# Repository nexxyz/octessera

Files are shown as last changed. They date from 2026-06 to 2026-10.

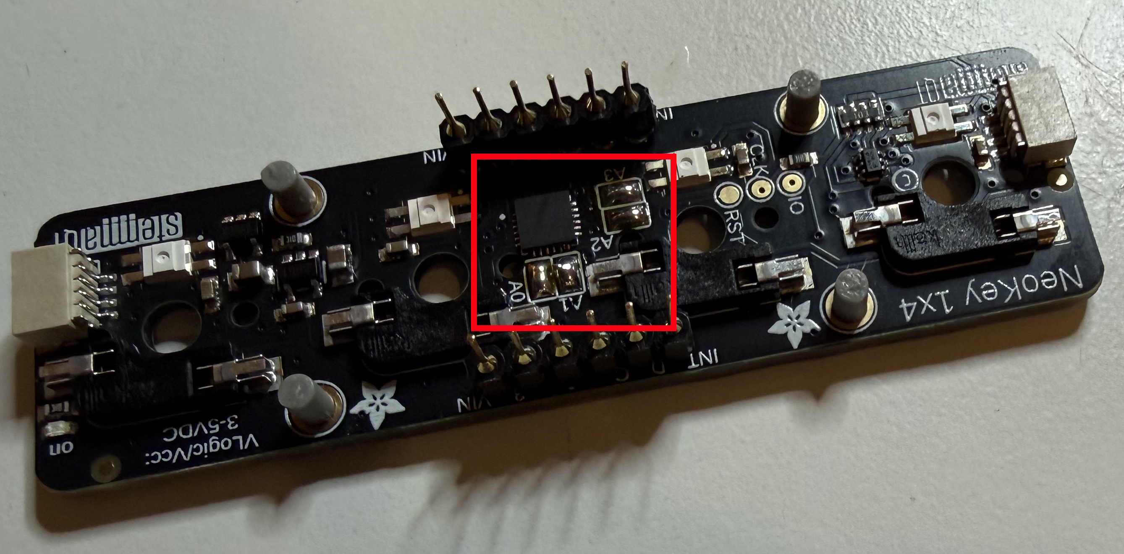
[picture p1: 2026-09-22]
userdocs/hardware/images/assembly/neokey-address-jumpers.jpg

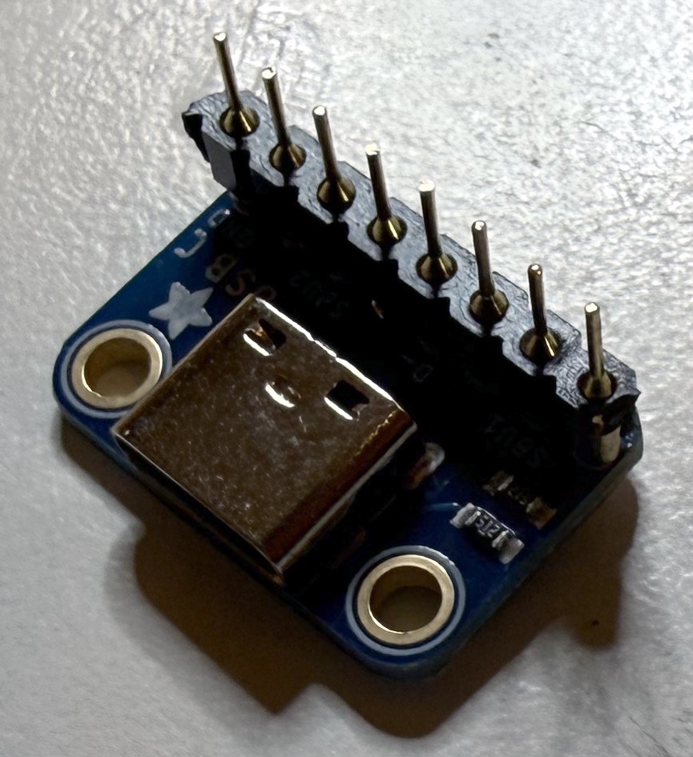
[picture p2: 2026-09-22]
userdocs/hardware/images/assembly/power-breakout.jpg

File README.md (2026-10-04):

# Octessera

Octessera turns cellular automata into music you can play.

It is a collection of small algorithmic musical world-bubbles. Set up a few
systems, combine them, nudge them, anchor them with a little sequencing, and
perform with the result in real time. Instead of filling in a piano roll, you
are giving small rule-based worlds room to surprise you.

## Start here

- [Try the simulator](userdocs/desktop-simulator.md) — make a sound without
  building the hardware.
- [Build the instrument](userdocs/hardware/assembly-manual.md) — assemble a
  standalone Octessera around a Raspberry Pi Zero 2 W or Orange Pi Zero 2W.

The standalone hardware uses one of those two fixed compute-board paths, with
an 8x8 grid, keys, encoders, OLED, and DAC. The desktop simulator mirrors the
same instrument so you can explore it on a computer first.

## What You Can Make

- Grow generative synth patterns from Life, Brain, Ant, Bounce, Raindrops, and
  other cellular-automata behaviors.
- Make hands-on drum sequences, load samples, and send parts to external MIDI
  gear.
- Layer up to eight instruments and let grid motion reshape another layer's
  pitch, filter, velocity, or probability through modulation.
- Route instruments directly or through FX buses, then shape the shared mix with
  bus and global effects.
- Use **Keys** to play a line live, and use **Play** pages to mix, pan, change
  trigger probability, move XY controls, and punch in momentary effects.

A first session might be a drifting `life` pattern under a hand-built drum
sequence, with a sampler providing the hits, a bus effect making room for the
synth, and a live Keys layer nudging the whole thing somewhere new.

## Two reading guides

- [User guide](userdocs/README.md) — simulator, assembly, setup, music-making,
  controls, and reference pages.
- [Technical guide](docs/README.md) — native architecture, contracts, fixed
  hardware paths, build tools, and provenance.

## Notes

[License](LICENSE) · [Sample source](samples/SOURCE.md) ·
[Hardware attributions](hardware/ATTRIBUTIONS.md) ·
[Third-party notices](THIRD_PARTY_NOTICES.md)

This project was created with AI assistance. Octessera itself, however, does not contain any AI.

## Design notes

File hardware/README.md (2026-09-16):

# Hardware

This is the home for Octessera's canonical hardware sources and committed
fabrication outputs.

## Navigate the hardware tree

- [`hardware/docs/`](docs/) contains build, bring-up, and hardware reference documents.
- [`hardware/pcb/`](pcb/) is the canonical KiCad source and library tree.
- [`hardware/enclosure/`](enclosure/) is the canonical CadQuery, generator, test, wrapper,
  and workflow source tree.
- The [hardware build entry](../userdocs/hardware/assembly-manual.md) walks through
  the shared assembly path.

## PCB outputs

[`hardware/pcb/gerber/`](pcb/gerber/) contains the committed fabrication output: Gerbers,
drill files, the KiCad job file, and [`gerber.zip`](pcb/gerber/gerber.zip).

## Enclosure outputs

The enclosure source tree includes
[`CAD_WORKFLOW.md`](enclosure/CAD_WORKFLOW.md) and the CadQuery generators,
tests, and wrappers. Its committed generated output sets are:

- [`hardware/enclosure/step/`](enclosure/step/) — exactly 18 STEP files;
- [`hardware/enclosure/stl/`](enclosure/stl/) — exactly 18 printable STL files;
- [`hardware/enclosure/3mf-single-material/`](enclosure/3mf-single-material/) — exactly 18 single-material 3MF files;
- [`hardware/enclosure/3mf-multicolor/`](enclosure/3mf-multicolor/) — exactly 18 3MF files.

The multicolor set is a complete print set: 12 authored two-material designs
plus six one-material support pieces.

Protective-case filenames are canonical and statusless (`protective_case_*`).
The design remains an unqualified check-fit prototype, not a drop-rated,
waterproof, or transport-qualified product.

## Attribution and notices

Consult these companions as applicable:

- [`hardware/ATTRIBUTIONS.md`](ATTRIBUTIONS.md)
- [`NOTICE`](../NOTICE)
- [`THIRD_PARTY_NOTICES.md`](../THIRD_PARTY_NOTICES.md)
- [`samples/SOURCE.md`](../samples/SOURCE.md)

## Release assets

GitHub Desktop and Pi release assets are built by the release workflows and are
not stored here. This tree contains the canonical hardware sources and
committed fabrication outputs only.

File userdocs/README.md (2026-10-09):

# Octessera user manual

Octessera is a collection of small algorithmic musical world-bubbles. Set up a
few systems, nudge them, anchor them with a little sequencing, and play the
result together with the machine.

## 1. Try the simulator

Start with the [desktop simulator](desktop-simulator.md) if you want to make a
sound before building anything. It needs no PCB, board, OLED, or soldering iron.

**Next:** [Learn the controls](controls-cheat-sheet.md)

## 2. Build the device

Choose a Raspberry Pi Zero 2 W or Orange Pi Zero 2W. Use the matching board
image and enclosure top.

[Build and assembly manual](hardware/assembly-manual.md) · [Safety and
power](hardware/safety-and-power.md)

**Next:** [Flash and first boot](hardware/flash-and-first-boot.md)

## 3. Flash and set it up

[Flash and first-boot guide](hardware/flash-and-first-boot.md) — matching image,
flashing, first boot, and network setup.

[USB roles](hardware/usb-roles.md) — host-computer connections.

**Next:** [Make music](#4-make-music)

## 4. Make music

1. In **Build**, choose `life`, `brain`, or `raindrops` for a layer.
2. Draw a few cells on the grid.
3. In **Shape**, choose a **synth**.
4. Press **Play** or **Space**.
5. Use **Play Mix** to adjust the layer's level, then explore the other Play
   pages.

[Controls cheat sheet](controls-cheat-sheet.md) · [Behaviors and Play
pages](behaviors-and-play.md) · [Sound and Link](sound-and-link.md) ·
[Recording](recording.md)

**Next:** [Controls cheat sheet](controls-cheat-sheet.md)

**Something is wrong?** Start with [troubleshooting](troubleshooting.md). Power
down before opening the case or moving wiring.

## Reference

### Contents

- **Operation:** [Controls cheat sheet](controls-cheat-sheet.md), [Behaviors and
  Play pages](behaviors-and-play.md), [Sound and Link: instruments, effects,
  and modulation](sound-and-link.md), [Recording audio and OLED](recording.md),
  [Data backup and restore](data-backup-restore.md),
  [Bluetooth keyboards and speakers](bluetooth.md), and
  [Troubleshooting](troubleshooting.md).
- **Build and hardware:** [Assembly manual](hardware/assembly-manual.md),
  [Flash and first boot](hardware/flash-and-first-boot.md),
  [Setup portal](hardware/setup-portal.md), [Enclosure](hardware/enclosure.md),
  [Protective case (optional)](hardware/protective-case.md),
  [Safety and power](hardware/safety-and-power.md), and
  [USB roles](hardware/usb-roles.md).
- **Quick reference:** [Printable quick reference](print/quick-reference.pdf).

### Practical performance

Use these as planning targets for dense patches:

| Mode | Synth voices | Sample voices | Bus FX | Global FX |
|---|---:|---:|---:|---:|
| Raspberry Latency | 16 | 16 | 8 | 2 |
| Raspberry Capacity | 32 | 32 | 8 | 2 |
| Orange Latency | 24 | 24 | 8 | 2 |
| Orange Capacity | 64 | 32 | 12 | 2 |

Voice counts are totals across all instrument slots, not per-instrument limits.
Adaptive voice stealing may reduce the active synth count as load rises. These
are practical targets rather than guarantees; behaviors, samples, and effects
all change the available headroom.

How quick does it feel? In Latency mode a grid press reaches your ears in about
6 ms on the Orange and 8 ms on the Raspberry. Capacity mode renders a little
ahead so it can spread the work over two cores, which puts it at about 13 to
15 ms: still fine for most playing, but you may feel it on fast finger drumming.

### Playing in front of people

Octessera boards skip the operating system's daily package-list and
manual-index jobs, plus a few other chores that do nothing useful on an
instrument. They never installed anything here anyway, but on the Raspberry
they made the audio stutter for a few seconds at a random time each day.

A handful of useful housekeeping jobs still run on a timer: log rotation, SD
card trim, temp-file cleanup, a package-database backup, and on the Raspberry
a once-a-minute Wi-Fi health log. Each of them has been run during playback
without disturbing the sound, but if you'd rather not find out the hard way,
use **System > Setup > Show Hold > Hold 48h** before a show. It postpones those
jobs for 48 hours (a reboot doesn't cancel it); they simply run at their next
scheduled time afterwards. **Release** ends the hold early. A couple of tiny
chores always keep running because things break without them: saving the
clock, and on the Orange trimming the in-memory logs.

The Raspberry's four cores share one fairly slow memory bus, so anything
heavy happening next to the music can still cause crackles even when it runs
on another core. Do your maintenance before the show, not during it: updates,
`apt` over SSH, copying big files onto the board. The Orange has a lot more
memory headroom and shrugs most of this off, but the same habit doesn't hurt.

One more thing: don't run `apt upgrade` on the board. Octessera boots its own
tuned kernel and device-tree setup, and a stock kernel or bootloader package
sneaking in can leave you with a board that boots but doesn't make a sound (or
doesn't boot at all). The boards hold those packages so apt leaves them alone,
but please don't go fishing with `--allow-change-held-packages`. Octessera
updates come through **System > Setup > Updates** or a fresh image.

### Samples

The default library has 320 media files: 318 WAV files available to the
sampler, plus two AIFF files outside the WAV-only browser. You can add your own
samples through the desktop sample browser or the board sample paths.

For the optional OLED microSD card, format it as FAT32 or exFAT and name the
volume `OCTESSERA`; the instrument only picks up a card with exactly that name.
This is SD2; the selected board's boot card is SD1. Put WAV files under
`octessera/samples`. You can swap the card while the instrument is on; give it
a couple of seconds to show up. If you use **System > SD Card 2 > Start
Transfer**, eject the host drive before
pressing **Back** or **Main** to stop the transfer.

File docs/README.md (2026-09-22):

# Technical guide

This is the short route through Octessera's current implementation contracts,
fixed hardware paths, build tools, and provenance. For operating the instrument,
start with the [user manual](../userdocs/README.md).

## Repository map

- `apps/` — platform applications and hardware adapters.
- `crates/` — native Rust core, runtime, and audio crates.
- `packages/` — shared TypeScript packages and desktop-facing contracts.
- `config/` + `resources/` — shipped defaults, generated configuration, and shared data.
- [`hardware/`](../hardware/README.md) — canonical PCB, enclosure, and hardware documentation.
- `userdocs/` — end-user build, controls, and operation guides.
- `docs/` — technical specifications, workflows, and contributor references.
- `tools/` — build, image, hardware, release, and verification tooling.
- `samples/` — bundled sample content, source acknowledgements, and manifests.
- `licenses/` + `third_party/` — generated dependency inventories and vendored/source provenance.
- `assets/` — shared branding and device visual assets.
- `userpatches/` — Armbian image overlays and device files; it stays at the root because Armbian consumes this conventional path.

## Architecture and contracts

- [Runtime boundaries](runtime-boundaries.md) — ownership between the desktop
  UI, native runtime, core, adapters, and realtime audio engine.
- [Menu and controls spec](menu-and-controls-spec.md) — the authoritative
  control, menu, overlay, persistence, and display contract.
- [Menu tree spec](menu-tree-spec.md) — the canonical menu structure.
- [Board profiles](board-profiles.md) — the two fixed board IDs and their
  platform boundaries.
- [Platform capabilities](../resources/platform-capabilities.json) — shared
  dimensions and limits used by native and desktop contracts.

## Hardware and images

- [Hardware pinout and connections](../hardware/docs/pinout-and-connections.md)
  — board wiring, buses, and port ownership.
- [Flash and first boot](../userdocs/hardware/flash-and-first-boot.md) — image
  selection, flashing, network setup, and first power-on.
- [Orange production image and runtime reference](../hardware/docs/orange-pi-production-reference.md)
  — Orange image, service, storage, audio, USB, and updater contracts.
- [Orange Pi input routing](../hardware/docs/orange-pi-input-routing.md) — the
  board-specific UART and encoder-routing overlay.

## Development, build, and deployment

- [Development workflows](development-workflows.md) — contributor workflow map
  and focused references.
- [Desktop development](workflows/desktop-development.md) — simulator
  development and desktop builds.
- [Pi provisioning](../tools/pi/provision/README.md) — Raspberry OS and boot
  configuration.
- [Board deployment](workflows/deployment.md) — Raspberry deployment and Orange
  input-routing operations.
- [Orange Pi tools](../tools/orange-pi/README.md) — Orange SSH bootstrap and
  cross-build commands.

## Attribution and licensing

- [License](../LICENSE) — terms for original Octessera material.
- [Notice](../NOTICE) — concise standalone-artifact notices.
- [Third-party notices](../THIRD_PARTY_NOTICES.md) — known third-party material.
- [Bundled sample source](../samples/SOURCE.md) — the sample-pack source.
- [Hardware attributions](../hardware/ATTRIBUTIONS.md) — PCB, enclosure, and
  module references.
- [Vendored CPAL provenance](../third_party/cpal-0.15.3/PROVENANCE.md) — the
  source and fixed audio-host modifications for the vendored dependency.

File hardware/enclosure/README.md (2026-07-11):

# Enclosure

This is the enclosure and mechanical reference for the Octessera hardware target.

Use it with [`../docs/pinout-and-connections.md`](../docs/pinout-and-connections.md) for wiring and [`../docs/pi-bring-up.md`](../docs/pi-bring-up.md) for Pi setup. For the user-facing docs home, start at [`../../userdocs/README.md`](../../userdocs/README.md).

This is the part where the instrument becomes an object you can pick up. Print carefully, test-fit patiently, and take out the SD card before you put the device in the enclosure, or it may break. Ask me how I found that one out.

## Current Status

The enclosure is under construction. The current parameter data in
`enclosure_params.json` is the `v21` set, but the generated two-level faceplate
is still an active design model, not a production-ready enclosure release.

- Case size: `247 x 140 mm`
- Main PCB rail height: `3.2 mm`
- NeoTrellis rail height: `8.0 mm`

## Two-Level CadQuery Model

Generate the current two-level model with CadQuery/OpenCascade:

```sh
python hardware/enclosure/generate_two_level_enclosure_cadquery.py
```

After changing the roof or parametric wave guidance, run the validation script:

```sh
python hardware/enclosure/validate_wave_roof.py
```

It writes:

- `../../release-artifacts/enclosure/step/case_top_two_level_cadquery.step`
- `../../release-artifacts/enclosure/stl/case_top_two_level_cadquery.stl`

The script requires the enclosure Python dependencies:

```sh
python -m pip install -r hardware/enclosure/requirements.txt
```

This model keeps OLED and encoders on the lower deck, raises the NeoKeys and
8x8 NeoTrellis field, and uses a parametric raised roof/shoulder over the Pi area.
See [`CAD_WORKFLOW.md`](CAD_WORKFLOW.md) for the edit and validation loop. For branded top artifacts, prefer:

```powershell
powershell -NoProfile -ExecutionPolicy Bypass -File hardware/enclosure/generate_branded_top_artifacts_checked.ps1
```

Branding source and cleanup rules are documented in [`../docs/branding-assets.md`](../docs/branding-assets.md).

The STEP file is the preferred generated artifact. This is still not a
production lid: it does not yet recreate the full underside lip, catch rims,
board capture ribs, or bottom mating interface. Promote it to the production top
only after validating that underside interface, board capture, connector
clearance, slicer output, and the measured component height stack.

## External Access

The current case exposes these ports:

- Left side: audio 3.5mm
- Left side: USB-C power
- Left side: Pi microSD
- Bottom side: Pi mini-HDMI
- Bottom side: Pi USB data

The OLED microSD is not exposed as a case-edge port in the current `v21` entry.

## Power Rule

- Power the device through the enclosure USB-C power opening.
- Do not power the Raspberry Pi through its own micro-USB power connector.
- The Pi micro-USB power connector is intentionally covered by the enclosure and is not meant to be used.

## Mechanical Strategy

The current enclosure captures the boards without running screws through active hardware areas.

- Case screws do not pass through the PCBs or component fields.
- Heat-set insert bosses are integrated into the outer locator rail regions.
- The main PCB is located laterally by tight rails and nubs.
- Lid capture ribs limit upward movement at safe board-edge regions.
- The NeoTrellis cluster is located by perimeter rails.
- The NeoTrellis left rail is broken for the `J1` / connector path clearance.
- NeoTrellis vertical retention is handled by the screwed-down top faceplate and edge capture ribs, not by screws through the button field.

## Printing Notes

Current enclosure notes from the parameter source:

- No OLED top-edge / top-plate hole above the display
- Case height reduced to `140 mm`; width remains `247 mm`
- The checked-in release artifact is the current generated faceplate mesh:
  `../../release-artifacts/enclosure/stl/case_top_two_level_cadquery.stl`.

## Source of Truth

- Parameters: [`enclosure_params.json`](enclosure_params.json)
- Enclosure layout image: [`layout.png`](layout.png)
- Wave/slot guidance: [`wave_guidance.py`](wave_guidance.py)
- Parametric generator: [`generate_two_level_enclosure_cadquery.py`](generate_two_level_enclosure_cadquery.py)
- Standoff pillar generator: [`generate_standoff_pillars.py`](generate_standoff_pillars.py)
- Standoff top-pin generator: [`generate_standoff_top_pins.py`](generate_standoff_top_pins.py)
- CAD workflow and checks: [`CAD_WORKFLOW.md`](CAD_WORKFLOW.md)
- Branded top artifact wrapper: [`generate_branded_top_artifacts_checked.ps1`](generate_branded_top_artifacts_checked.ps1)
- Roof-wall validation: [`validate_wave_roof.py`](validate_wave_roof.py)

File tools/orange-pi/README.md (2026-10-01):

# Orange Pi tools

This is a one-key bootstrap for an Armbian Orange Pi. It creates only the
dedicated `octessera` deployment account and its SSH key authorization. It does
not edit global `sshd` configuration, passwords, firewall rules, or default
users. Supply the deployed board target explicitly; the bootstrap examples below
remain generic for bringing up a replacement image.

## SSH bootstrap

### 1. Generate the key on Windows

Run this from the repository root in PowerShell. The key is created only when
`$env:USERPROFILE\.ssh\octessera_orange_pi_ed25519` is absent. The script never
prints the private key. Supplying a host appends a labelled stanza to
`$env:USERPROFILE\.ssh\config`; an existing different stanza is an error, not
an overwrite.

```powershell
.\tools\orange-pi\bootstrap-ssh.ps1 -HostName "<ORANGE_HOST>" -UserName octessera
```

To preview without creating or changing anything:

```powershell
.\tools\orange-pi\bootstrap-ssh.ps1 -HostName "<ORANGE_HOST>" -UserName octessera -WhatIf
```

Copy the public-key line and the exact next command printed by the script.
Copy `bootstrap-armbian-ssh.sh` to the Orange Pi first; for example, place it
in the current directory as `./bootstrap-armbian-ssh.sh` using the board's
local terminal, a console transfer, or another trusted path.

Record the deployment-key fingerprint on Windows:

```powershell
ssh-keygen -lf "$env:USERPROFILE\.ssh\octessera_orange_pi_ed25519.pub" -E sha256
```

### 2. Run on the Orange Pi terminal

Run this on the Armbian board, not on Windows. Replace the quoted key with the
single line printed in step 1:

```sh
sudo bash ./bootstrap-armbian-ssh.sh 'ssh-ed25519 AAAA... octessera-orange-pi'
```

The script is idempotent. It preserves existing `authorized_keys` entries and
refuses unexpected existing `octessera` homes, groups, or sudoers rules. It
requires exactly one `ssh-ed25519` public-key argument. Passwordless sudo is
not enabled unless explicitly requested:

```sh
sudo bash ./bootstrap-armbian-ssh.sh --allow-deploy-sudo 'ssh-ed25519 AAAA... octessera-orange-pi'
```

That opt-in grants `octessera` passwordless sudo for all commands and writes
`/etc/sudoers.d/octessera-deploy`; the script validates the rule with
`visudo`. Without the flag, the standard sudo policy is unchanged.

### 3. Verify fingerprints, then connect

Before accepting a host key, compare the board's host-key fingerprint with the
fingerprint shown by Windows. On the Orange Pi's local terminal:

```sh
sudo ssh-keygen -lf /etc/ssh/ssh_host_ed25519_key.pub -E sha256
```

On Windows, replace `<ORANGE_PI_HOST>` with the user-supplied IP or hostname:

```powershell
ssh-keyscan -t ed25519 <ORANGE_PI_HOST> | ssh-keygen -lf - -E sha256
```

Only continue when those fingerprints match. Then test the dedicated key
(replace the host with the same user-supplied value):

```powershell
ssh -i "$env:USERPROFILE\.ssh\octessera_orange_pi_ed25519" -o IdentitiesOnly=yes octessera@<ORANGE_PI_HOST> "id -un; hostname; test -r ~/.ssh/authorized_keys"
```

If the local script added its stanza, the shorter equivalent is:

```powershell
ssh octessera-orange-pi "id -un; hostname; test -r ~/.ssh/authorized_keys"
```

Review the host key before answering the first SSH authenticity prompt. Do not
use `StrictHostKeyChecking=accept-new` as a substitute for comparing the
fingerprint.

### Removal and revocation

To revoke this key but keep the deployment account, remove its exact public
key line from `/home/octessera/.ssh/authorized_keys` on the Orange Pi and then
remove the local key files if no longer needed:

```sh
sudoedit /home/octessera/.ssh/authorized_keys
```

```powershell
Remove-Item "$env:USERPROFILE\.ssh\octessera_orange_pi_ed25519", "$env:USERPROFILE\.ssh\octessera_orange_pi_ed25519.pub"
```

To remove the account and its home after revoking the key:

```sh
sudo userdel --remove octessera
sudo groupdel octessera
```

If passwordless deploy sudo was enabled, remove only the drop-in after checking
that it is the rule created for this account:

```sh
sudo rm -- /etc/sudoers.d/octessera-deploy
sudo visudo -c
```

Remove the labelled `OCTESSERA ORANGE PI` stanza from the Windows SSH config
manually. Do not commit private keys, public keys, fingerprints tied to a
specific board, hostnames, IP addresses, or generated SSH config to Git.

## Target and transport

Set the target for the board you are operating. Use `with-opi-ssh.ps1` for
SSH and SCP; it supplies the dedicated key,
`known_hosts`, strict host-key checking, and the passphrase from
`OCTESSERA_PI_PASSPHRASE`.

```powershell
$OrangeTarget = "octessera@<ORANGE_HOST>"
./tools/orange-pi/with-opi-ssh.ps1 ssh -Target $OrangeTarget "id -un; hostname"
```

For input-routing changes, use the [Orange input-routing reference](../../hardware/docs/orange-pi-input-routing.md)
and its `provision-input-routing.ps1` wrapper. The [deployment workflow](../../docs/workflows/deployment.md)
covers Raspberry deployment, Orange development deployment, and Orange input routing.

## Cross-build and stage

The WSL Docker builder writes AArch64 binaries and schema-2 metadata sidecars
under `target/orange-pi-cross/`:

```powershell
./tools/orange-pi/build-opi-cross.ps1 -Binary orange-oled-smoke -Profile release
./tools/orange-pi/build-opi-cross.ps1 -Binary orange-seesaw-smoke -Profile release
./tools/orange-pi/build-opi-cross.ps1 -Binary octessera-pi -Profile release
./tools/orange-pi/test-build-opi-cross.ps1
```

Use `-DryRun` to print the Docker command. The canonical outputs are
`orange-oled-smoke`, `orange-seesaw-smoke`, and `octessera-pi`, each with its
adjacent `.metadata.json` file. The production image and runtime bundle use the
contracts in the [Orange production reference](../../hardware/docs/orange-pi-production-reference.md).

To stage an output on the fixed board, use the canonical wrapper and preserve
the binary and sidecar names:

```powershell
$OrangeTarget = "octessera@<ORANGE_HOST>"
./tools/orange-pi/with-opi-ssh.ps1 scp `
  -Target $OrangeTarget `
  target/orange-pi-cross/octessera-pi `
  "${OrangeTarget}:/tmp/octessera-pi"
./tools/orange-pi/with-opi-ssh.ps1 scp `
  -Target $OrangeTarget `
  target/orange-pi-cross/octessera-pi.metadata.json `
  "${OrangeTarget}:/tmp/octessera-pi.metadata.json"
```

### Persistent Orange development runtime (explicit opt-in)

This is **not** the release updater and is separate from the temporary
foreground `/pi-smoke orange` run. After reviewing the target, artifact, and
service interruption, use the exact cross-built runtime candidate and its
unchanged adjacent metadata sidecar:

```powershell
$OrangeTarget = "octessera@<ORANGE_HOST>"
./tools/orange-pi/deploy-opi-fast.ps1 -Target $OrangeTarget -LocalBinary target/orange-pi-cross/octessera-pi
# Later, to return to the installed release:
./tools/orange-pi/deploy-opi-fast.ps1 -Target $OrangeTarget -Restore
./tools/orange-pi/test-deploy-opi-fast.ps1
```

The binary must match the current repository HEAD and be an ELF64 AArch64
`runtime-candidate` for `orange-pi-zero-2w`, with schema-2 release-profile
metadata and matching SHA-256. This does **not** promote `runtime_ready` or
write release/updater metadata. On the board, the tool stages a root-owned
copy at `/opt/octessera/dev/<source-commit>/octessera-pi` and overrides only
`ExecStart` using `/etc/systemd/system/octessera.service.d/90-octessera-dev.conf`.
It refuses a pre-existing drop-in or an unexpected service/executable, checks
the restarted process, and tries to restore the installed service on activation
failure. `-Restore` removes only the recognized development override; it does
not delete the development binary. Neither action touches `current`, releases,
the installed executable symlink, boot files, or the image. A failure to verify
rollback requires immediate manual service inspection. Journal errors and
underruns are reported as warnings; an active service is not proof of clean
audio. Keep hardware listening and control checks in the operator loop. The
tool refuses an existing `/opt/octessera/dev/<source-commit>` directory rather
than overwriting a previously staged build; restore leaves that directory in
place for explicit operator review or cleanup.

## Performance tools

The current performance commands are also listed in
[`docs/workflows/pi-development-and-profiling.md`](../../docs/workflows/pi-development-and-profiling.md):

```powershell
$OrangeTarget = "octessera@<ORANGE_HOST>"
./tools/orange-pi/run-orange-capability-study.ps1 -Target $OrangeTarget -Mode PassiveBaseline -PrintOnly
./tools/orange-pi/run-orange-capability-study.ps1 -Target $OrangeTarget -Mode Dsp64 -AllowServiceInterruption -PrintOnly
./tools/orange-pi/run-orange-capability-study.ps1 -Target $OrangeTarget -Mode Dsp256 -AllowServiceInterruption -PrintOnly
./tools/orange-pi/run-orange-live-audio-matrix.ps1 -Target $OrangeTarget -PrintOnly
./tools/orange-pi/run-orange-performance-baseline.ps1 -Target $OrangeTarget -PrintOnly
```

Active runs use `-AllowServiceInterruption`; the live matrix additionally uses
`-AllowMatrixServiceInterruption`. The command-generation checks are:

```powershell
./tools/orange-pi/test-with-opi-ssh.ps1
./tools/orange-pi/test-run-orange-capability-study.ps1
./tools/orange-pi/test-run-orange-live-audio-matrix.ps1
./tools/orange-pi/test-run-orange-performance-baseline.ps1
```

For an isolated Orange AWAKE live candidate, the workstation-only Aux timing
smoke is separately opt-in. It runs a short cutoff-edit pattern after the native
menu and host path are verified, then requires an accepted, identified automatic
default-save success for the final edit revision. The native worker emits that
completion only after writing the clone's default config. The existing AWAKE
wrapper uses a temporary study-store clone:

```powershell
$OrangeTarget = "octessera@<ORANGE_HOST>"
$previousAutoAux = $env:OCTESSERA_ORANGE_STUDY_AUTOAUX
$env:OCTESSERA_ORANGE_STUDY_AUTOAUX = "1"
try {
  ./tools/orange-pi/run-orange-capability-study.ps1 `
    -Target $OrangeTarget -Mode LiveCandidate -UiProfile -AutoPlay -KeepAwake `
    -AllowServiceInterruption -LiveSeconds 30
} finally {
  if ($null -eq $previousAutoAux) {
    Remove-Item Env:OCTESSERA_ORANGE_STUDY_AUTOAUX -ErrorAction SilentlyContinue
  } else {
    $env:OCTESSERA_ORANGE_STUDY_AUTOAUX = $previousAutoAux
  }
}
```

Without the workstation opt-in, `-KeepAwake` does not schedule Aux turns. The
candidate refuses the timing sequence unless all its timing/profile gates and
the isolated study-store path are present; it never rewrites the installed
user store. If Auto Save is off, the candidate enables it through the native
Saves menu in the temporary clone so the final edit has a due save. The one-line
`orange-autoaux` report includes the final save revision, request ID, and elapsed
time from the edit burst to accepted completion, alongside the existing input,
OLED, and host-command evidence. A missing completion or matching failed save
fails the opt-in smoke; unrelated, stale-revision, manual, and unidentified
results do not count. The installed default and original user store remain
untouched.

## Orange Pi USB gadget composer

`orange-pi-usb-gadget.sh` is the Armbian ConfigFS composer. It reads
`/var/lib/octessera/presets/system.json`; `audioOutputs.usb` selects UAC2 and
`usb.midiOutEnabled` selects MIDI. The fixed UDC is `musb-hdrc.4.auto`.

```sh
sudo bash ./tools/orange-pi/orange-pi-usb-gadget.sh setup \
  --config /var/lib/octessera/presets/system.json
sudo bash ./tools/orange-pi/orange-pi-usb-gadget.sh teardown
bash ./tools/orange-pi/test-orange-pi-usb-gadget.sh
```

Supported modes are no gadget, `midi`, `uac2`, and `combined`; the installed
image uses `combined`. Setup and teardown share
`/run/lock/octessera-orange-usb-gadget.lock`. `--lock-file`, `--configfs-root`,
and `--udc-root` are available for isolated fake-ConfigFS tests.

The product strings are `Octessera MIDI`, `Octessera Line In`, and
`Octessera Audio + MIDI` for `midi`, `uac2`, and `combined`. MIDI and combined
require a writable ConfigFS `interface_string`. The MIDI interface descriptor
and Windows `DEVPKEY_Device_BusReportedDeviceDesc` are `Octessera MIDI`; the
composer writes and verifies the 14-byte value before binding the UDC.

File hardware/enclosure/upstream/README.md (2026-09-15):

# Upstream parametric box

`andy_wings_parametric_box.py` is adapted from **Simple and Light Parametric
BOX – CadQuery** by Andy Wings / `@WingsWorld_2406962`:

- Printables: https://www.printables.com/model/1069138-simple-and-light-parametric-box-cadquery
- Matching Thingiverse listing: https://www.thingiverse.com/thing:6842165
- License: [CC BY-SA 4.0](https://creativecommons.org/licenses/by-sa/4.0/)

Octessera adapted and modified the upstream shell, mating ring, hinge, and Clip
profile algorithms. The adaptation only makes construction reusable, derives
the hinge leaf depth from each measure instance, supports configured clip
positions, skips the horizontal chamfer when `chamfer_xy=0` while preserving the
default chamfer, and guards default construction/export behind the module
entrypoint.

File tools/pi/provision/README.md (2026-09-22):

# Pi provisioning

`../provision-pi.ps1` installs the development Pi OS, boot, network, sudoers,
performance, and splash configuration. It is safe to run again after changing
the tracked files in this directory or the shared Pi image files.

Provision the device before the first fast deployment:

```powershell
$PiTarget = "pi@<PI_HOST>"
./tools/pi/provision-pi.ps1 -Target $PiTarget -BoardProfile raspberry-pi-zero-2w
```

The selected initramfs is not refreshed by default. Pass `-UpdateInitramfs` for
an explicit OS or boot rebuild; the direct script accepts
`--update-initramfs`. Provisioning removes the retired Raspberry animation hook
and script before an explicit rebuild, so no board carries animation in its
initramfs. The deployment script does not change OS configuration; it uploads
the binary or source, restarts the service, and can tail its logs.
Raspberry Pi provisioning rejects `orange-pi-zero-2w`; Orange Pi uses the
separate Armbian bring-up path.

The shared transport wrapper reads an encrypted-key passphrase only from the
process environment and removes its temporary askpass script when it exits.
Set `OCTESSERA_PI_PASSPHRASE` in the current PowerShell process first:

```powershell
# Set OCTESSERA_PI_PASSPHRASE in this PowerShell process before these commands.
$PiTarget = "pi@<PI_HOST>"
./tools/pi/with-rpi-ssh.ps1 ssh -Target $PiTarget "hostname"
./tools/pi/with-rpi-ssh.ps1 scp -Target $PiTarget ./candidate.bin "${PiTarget}:/tmp/candidate.bin"
./tools/pi/with-rpi-ssh.ps1 ssh-payload -Target $PiTarget ./remote-script.sh
```

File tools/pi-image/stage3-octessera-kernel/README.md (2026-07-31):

# Raspberry custom-kernel stage

Enable this stage before `stage4-octessera`. The image build must provide:

- `OCTESSERA_KERNEL_PACKAGE`: the already validated exact arm64 `.deb`;
- `OCTESSERA_KERNEL_CHECKSUMS`: its one-entry `SHA256SUMS` file;
- `OCTESSERA_KERNEL_PROVENANCE`: the package provenance JSON; it is copied and
  validated before `dpkg` is allowed to install the package.

The stage rechecks the package filename, Debian control fields, checksum, ARM64
firmware header, DTB, overlays, and required modules. It retains stock boot
files under `octessera/recovery-stock` before installing the package. Stage 4B
generates the custom initramfs after the service stage has installed its hooks.

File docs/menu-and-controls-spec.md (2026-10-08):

# Menu and Controls Spec (Authoritative)

This is the entry point for the canonical menu/control spec. The full menu tree is split into `docs/menu-tree-spec.md`; that file is part of this authoritative spec and must stay in sync with native menu changes.

Context-help copy source: `resources/menu-help-texts.tsv` (required header row). Each row provides a title plus two short text fields. Keep one idea per text field; the runtime may join and wrap them for the target display.
Platform capability source: `resources/platform-capabilities.json`; generated TypeScript and Rust constants must stay in sync with it. Display palette source: `resources/display-palette.json`; generated TypeScript, CSS, and Rust constants must stay in sync with it.

## Cheat Sheet

| Combo | Function | Notes |
|---|---|---|
| Shift + Space | Stop | Internal sync: stop/reset, silence internal audio, and clear held MIDI notes without broad panic.
| Shift + Space (external sync) | Resync arm | External sync: arms a one-shot resync at the next 96-PPQN (one-bar) boundary; playback and the grid continue, then transport origins reset to zero and the arm clears.
| Shift + Back | Clear active layer | Re-initializes current active layer behavior state.
| Shift + Fn | Combined modifier | Acts as its own logical button; Fn and Shift are inactive while both physical buttons are held.
| Combined modifier + Main press | Context help | Opens help for highlighted menu entry.
| Fn + Main press | Aux mappings modal | Opens the scrollable mappings modal from anywhere, whether stopped or playing. Holding Fn alone does not open it.
| Fn + Main encoder turn right outside edit | Single step | While paused/stopped, advances exactly one behavior generation and remains paused/stopped; while playing, shows `Pause first`. Turning left is consumed with no action. Numeric edit takes priority over this gesture.
| Main numeric edit turn | Coarse/fine value change | Plain Main is coarse; Fn+Main is fine. Shift+Main and combined Shift+Fn+Main remain coarse. Fn does not change enum, bool, or text edit turns.
| Aux1–3 numeric turn | Coarse/fine bound value change | Plain turn is coarse and Fn turn fine in the normal custom/auto-map target. Shift is coarse and combined Shift+Fn fine in the shifted custom bank only, with no fallback.
| Fn + Space | Reset stop | Stops/resets, silences internal audio, and clears held MIDI notes without broad panic; takes priority over sample preview.
| Combined modifier + Space | Reserved | No-op.
| Fn + leftmost grid column | Navigate layers (1..8) | Mirrors `Build > Layer`.
| Combined modifier + leftmost grid column | Layer trigger gate toggle | Toggles that layer between `0%` and its previous trigger mode without changing active layer. Only this disable transition releases held Synth, FM, Plucked, and Sampler notes owned by that layer, plus external MIDI notes; an already-ringing one-shot Drum hit finishes its decay. Ordinary Play Trigger Gate edits to `0%` only suppress future admissions. Other layers are unaffected, and re-enable does not resurrect released notes.
| Fn held + leftmost column LEDs | Navigation indicators | Cyan = navigation/current layer focus, green = configured layer, gray/black = inactive or non-navigable.
| Fn + rightmost grid column | Navigate Play pages | Opens `Play` and enables Play page if currently off; exits Play if already active.
| Combined modifier held LEDs | Layer-only indicators | Shows the left/layer side of Fn navigation only; Play page column is hidden/reserved.
| Sample assign + Shift + cell | Row assign step | Applies current selected-cell assign step to the whole row.
| Sample assign + combined modifier + cell | Column assign step | Applies current selected-cell assign step to the whole column.
| Fn + Aux press | Alternate aux binding | Binds the focused bindable value as that aux Turn target, or focused action as its `!` press target.

## Control Mapping

| Control | Simulator Key | Function |
|---|---|---|
| Main encoder turn | ← → | Move cursor / adjust values |
| Main encoder press | Enter | Enter group / enter/exit edit / trigger action |
| Back button | Backspace / Esc | Go back / exit edit / clear grid (with Shift) |
| Space button | Space | Play / Pause |
| Shift + Space | Shift+Space | Stop/reset with internal-audio silence and bounded held-note cleanup; external sync arms the next 96-PPQN boundary instead |
| Fn + Space | Ctrl+Space | Reset stop with internal-audio silence and bounded held-note cleanup |
| Shift + Fn + Space | Shift+Ctrl+Space | Reserved no-op |
| Shift + Back | Shift+Backspace / Shift+Esc | Clear grid (re-initialize behavior) |
| Aux encoder 1-3 turn | (simulated) | Adjust a numeric target coarsely, or retain ordinary discrete turns for enum/bool targets; Orange SW1/SW2/SW4 use the native GPIO event path |
| Aux encoder 1-3 press | (simulated) | Trigger bound press mapping; Orange AUX2's switch line is unavailable only while UART0 TX is active and is enabled by the input-routing overlay |
| Fn + Aux encoder press | Fn + (simulated) | Alternate action: bind current value as Turn target or current action as `!` press target |
| Fn + Main encoder press | Fn+Enter | Open/close the Aux mappings modal; holding Fn alone does not open it |
| Shift + Aux encoder turn/press | Shift + (simulated) | Numeric turns are coarse; use only the shifted aux binding bank |
| Fn + Aux encoder turn | Fn + (simulated) | Fine numeric turn on the normal custom/auto-map target |
| Shift + Fn + Aux encoder press | Shift+Ctrl + (simulated) | Bind current value/action into shifted aux binding bank |
| Shift + Fn + Aux encoder turn | Shift+Ctrl + (simulated) | Fine numeric turn using only the shifted custom bank |
| Shift + Fn | Shift+Ctrl | Combined modifier; acts as its own logical button and disables Fn/Shift functions while both are held |
| Combined modifier + Main press | Shift+Ctrl+Enter | Context help for highlighted entry |
| Fn + Main encoder turn right outside editing | Ctrl+→ | Single behavior/world generation step while paused/stopped; while editing, numeric values turn finely and other edit types keep their ordinary turn behavior |
| Fn + leftmost grid column | Ctrl + leftmost grid column | Navigate active layer (1..8); hold Fn to see layer indicators |
| Fn + rightmost grid column | Ctrl + rightmost grid column | Navigate/activate Play Play page; hold Fn to see page indicators |
| Shift + Fn + leftmost grid column | Shift+Ctrl + leftmost grid column | Toggle that layer's trigger gate without changing active layer; disabling releases its held Synth, FM, Plucked, Sampler, and external MIDI notes and suppresses future triggers; one-shot Drum hits finish their decay |
| Sample assign mode + Shift + cell press | Shift + cell | Apply current assign toggle/level step to entire row |
| Sample assign mode + combined modifier + cell press | Shift+Ctrl + cell | Apply current assign toggle/level step to entire column |

## USB-host keyboard

The base keyboard controls mirror the simulator controls. USB-host capture
additionally maps the three AUX encoder rows:

| Keyboard key | Native control | Repeat |
|---|---|---|
| ← / ↑ | Main encoder turn `-1` | Accepted |
| → / ↓ | Main encoder turn `+1` | Accepted |
| Q / W / E | AUX1 turn `-1` / click / turn `+1` | Turns accepted; click suppressed |
| A / S / D | AUX2 turn `-1` / click / turn `+1` | Turns accepted; click suppressed |
| Y/Z / X / C | AUX3 turn `-1` / click / turn `+1` | Turns accepted; click suppressed |
| Enter | Main encoder press | Suppressed |
| Backspace / Escape | Back button | Suppressed |
| Space | Space button (`S`) | Suppressed |
| Shift | Shift modifier | Suppressed |
| Control | Fn modifier | Suppressed |

Key presses and releases update the corresponding native button or modifier state. Arrow and AUX turn key-repeat events emit additional turns; repeat events for Enter, AUX click keys, Back, Space, Shift, and Control do not emit additional edges. AUX click key releases clear their held keyboard state without retriggering the encoder click, and disconnect, disable, read failure, and shutdown use the same held-state cleanup. The AUX3 left key is the physical key immediately right of left Shift; Linux binds that position as `KEY_Z` whether its keycap is `Y` or `Z`. Space remains the hardware Space/S button; the letter `S` is the AUX2 encoder click. Modifier combinations therefore retain their normal semantics: Shift+Space is Stop (or Resync arm under external sync), Control+Space is Reset stop, and Shift+Control+Enter opens context help.

Raspberry capture requires the persisted USB role to be `Host`; changing that role still uses the existing save-and-reboot flow. Orange capture uses the fixed USB-A host connector and is independent of USB0 OTG/gadget behavior. On both boards, capture is enabled only for graphical HDMI modes: `live-grid`, `plain-grid`, `active-behavior`, and `cycle-behaviors`. `Terminal` disables capture. Hotplug and HDMI-mode transitions are live: the first supported keyboard is selected and exclusively grabbed, a second keyboard is ignored while it is selected, and disconnects or gate changes release held logical controls and the grab.

Simulator grid drag behavior follows the active behavior's declared interaction mode. Paint behaviors drag-toggle/draw cells for editing; momentary behaviors such as Keys release the previous cell when the pointer enters another cell, matching a single finger sliding across grid buttons.

Raspberry and Orange use the same native encoder dispatch semantics: consecutive turns from one encoder in one direction coalesce and clamp to a `-127..127` delta, reversals remain ordered, and pending turns dispatch before an encoder press. Each input pickup drains at most 16 encoder events so other runtime work is not starved.

Help popup behavior:

- Main encoder turn scrolls help text
- Main encoder press closes help

Aux mappings modal behavior:

- Fn + Main encoder press opens the scrollable modal from anywhere, whether transport is stopped or playing. Releasing Fn does not close it; Fn held alone does not open it.
- The modal shows all 12 mappings, including unbound rows as `-`:

  | Bank | Aux | Turn | Click |
  |---|---|---|---|
  | Normal | 1 | Mapping or `-` | Mapping or `-` |
  | Normal | 2 | Mapping or `-` | Mapping or `-` |
  | Normal | 3 | Mapping or `-` | Mapping or `-` |
  | Shifted | 1 | Mapping or `-` | Mapping or `-` |
  | Shifted | 2 | Mapping or `-` | Mapping or `-` |
  | Shifted | 3 | Mapping or `-` | Mapping or `-` |

- Normal mappings use a custom binding first, then auto-map; shifted mappings use the shifted custom bank only, with no fallback.
- Main encoder turn scrolls the modal. Aux turns and clicks do nothing while it is open; they do not affect the underlying menu or bindings.
- Plain Main press, Fn + Main press again, or Back closes the modal. Shift + Fn + Main press opens context help instead. After closing, normal Main/Shift+Main clicks, Fn fine turns, and Aux bindings work as usual.

## Transport States

- Play: `▶` (green flash on full-note/measure boundaries, yellow flash on other beat boundaries)
- Pause: `⏸`
- Stop: `■`
- Stop, accepted MIDI Start, and resync reset the transport origin, generic scan cursor, autonomous Build cadence, Pattern phase, and Looper playback position while preserving evolved worlds, configuration, and recorded loop; behavior-owned state follows each behavior's reset contract. While transport runs, clearing or replacing a behavior reinitializes or restores its behavior-owned state as defined, while preserving the transport-owned generic interpretation cursor, fractional accumulator, and page/section phase. Only Sequencer has origin-immediate static-grid semantics: page 1 step 1 is anchored at transport origin, empty leading cells are timed rests, and later pages continue without restarting. For an armed external resync, clocks strictly before the next 96-PPQN boundary process normally; the boundary clock is consumed by the reset, scanning Sequencer layers process their origin tick at reported PPQN 0, and non-Sequencer layers do not receive a zero-elapsed tick. The following clock reports PPQN 1 and does not repeat the origin tick. Pause and layer trigger-gate changes preserve phase; true stop/reset returns to origin. Pause/Continue resumes the exact phase.

## Seeded Randomness

Randomness is unseeded unless a source opts in. `Build > Seed` (`randomSeed`, `1..9999`, default `1`) is one shared per-patch seed. `Build > Lx > Seeded` makes that layer's behavior randomness, including hash-style choices and the Rhythm/Musical/weave pattern seed, follow a stream mixed from Seed and the layer index. `Link > Lx > Seeded` does the same for that layer's trigger probability and random arp order; unseeded Link layers keep the shared unseeded streams. Seeded streams restart on every transport reset (stop, play-from-stop, accepted MIDI Start, resync), on patch load, and when Seed or the layer's Seeded switch changes, so the same starting world, inputs, and timing replay the same result on every platform. Restarting a stream never resets an evolved grid. Instrument and FX audio-rate noise is never seeded.

## Menu Tree

The full native menu tree lives in [`menu-tree-spec.md`](menu-tree-spec.md). Keep that file in sync with native menu/control changes.

System children are ordered as Load Preset, Recording, Notes, MIDI, Audio, UI, conditional SD Card 2,
conditional HDMI Video, conditional Bluetooth, Saves, Setup, Reset, then Panic, Sys. Info, Basic Help, Reboot, and Shutdown.
Within each recursive group, parameters and submenus precede action rows, except that the dynamic Rename group lists preset choices before its Rename actions. The System tree fully expands
the desktop, Orange, Raspberry Gadget, and Raspberry Host branches.

## OLED Display

- Native presentation publishes a positive-revision `oled_frame` (`128x128`, `rgb565be`) only when the frame bytes change, immediately before the semantic snapshot that references `oledFrameRevision`. PlaybackRuntime owns OLED brightness conversion and must not emit a snapshot with revision `0`, including when presentation input is absent or malformed. Before the first valid frame, an invalid snapshot is suppressed and typed fault/status is emitted; after a valid frame, non-OLED snapshot state continues with the prior positive revision and a typed retain-last-good fault/status. Desktop, Raspberry, and Orange consume native frames only; no TypeScript or semantic Pi renderer fallback is permitted.
- Every snapshot `display` object carries the required `bodyLayout`: `rows` preserves the existing menu/help/sample/restore/confirmation/System Info/concise-MIDI row semantics, including its 28-character/7-row normalization, bars, selected-line scrolling, and scrollbars; `card` is used for setup-portal and Backup / Restore status and keeps every complete semantic source string in `display.lines`. Card rendering uses the shared `x=4`, `width=120`, `y=18`, `height=91`, `rowAdvance=13` body rectangle (20 monospace columns by 7 rows), reserves the final visual row for the selected action, and ignores row bars/scroll metadata. When card prose wraps or later semantic lines do not fit, only the final visible prose row receives `...`. The canonical native renderer and the Pi renderer use the same fixed-font layout metrics and wrapping rules.
- Pi/Orange cache candidates promote only on an exact matching snapshot reference. With no accepted frame, publication is explicit black. With an accepted frame and a missing, future, stale, malformed, or conflicting reference, publication is `RetainedLastGood` carrying the accepted immutable bytes and revision, while the typed cache fault remains sticky. Same-revision byte conflicts remove candidates or poison accepted revisions; only a strictly newer valid candidate plus matching snapshot can recover. The first acknowledged menu still requires an exact accepted matching pair; retained-last-good is not sufficient. Boot, direct fault, shutdown, suspend, and ownership lifecycle frames remain native adapter paths.

- 128×128 pixel, simulated in desktop app
- 20 characters × 8 lines of text (5×7 font, 16px line height)
- Top line: title bar (colored by section)
- Canonical display palette names are independent from menu sections: `GREEN` `#63D23F` for `Build`, `RED` `#DD82CD` for `Link`, `BLUE` `#35CFF2` for `Shape`, `YELLOW` `#FFD447` for `Play`, `GRAY` `#C9CED6` for `System`, plus white `#FFFFFF` and black `#000000`. Runtime, Pi, and desktop UI colors use this palette unless a behavior deliberately owns its own palette.
- Body lines 2-8: menu items use a `> ` marker and inverted highlight on the selected row, and `* ` when editing; while browsing, selected value rows stay compact on one row (for example `> Cutoff 127`) instead of adding a separate value row
- Native menu snapshots include rendered-row scroll metadata (`scrollOffset`, `totalRows`, `visibleRows`) for the current body window. Desktop renders this as a 1-2 px scrollbar inside the OLED body only when total rendered rows exceed visible body rows; it does not consume text columns and is omitted for splash/help/confirm overlays unless menu metadata is present.
- Context help for every submenu, parameter, action, and non-file selector menu item must resolve to an entry from `resources/menu-help-texts.tsv`; native tests must fail on missing coverage. Behavior selector leaves use behavior-specific help, behavior category menu items use stable `behavior.category.*` help keys, and parameter binding picker leaves resolve to the underlying target parameter help. Dynamic file menu items such as sample browser files and folders keep their own `sample.*` action help.
- Platform-sized menu/runtime limits such as layer count, instrument count, sample slots, bus count, global FX slots, Play-FX concurrency, scan section counts, OLED size, and pan position count come from `resources/platform-capabilities.json`.
- Splash graphics use the shared static `SPLASH_SLEEP_SHUTDOWN` logo+wordmark background for sleep/shutdown with the existing toaster geometry; the native sleep transition toast is exactly `Going to sleep`; regular logo presentation remains unchanged for startup/wakeup.
- On Pi, `display.off` keeps the OLED dark. Otherwise a top-level `runtimeError` takes full-frame priority over splash, menu, and footer toast content; it shows the typed domain/code/operation/message fault and leaves transport/event indicators hidden. The native MIDI input-list failure presentation is the exception: it keeps the concise `MIDI INPUTS` / `MIDI unavailable` menu frame and toast. With no runtime error, splash precedes the normal menu/footer priority described below.
- Full runtime errors use seven fixed body rows at the existing card geometry: `DOMAIN ` plus 11 identifier cells, `CODE ` plus 13, `OP ` plus 15, then `MSG ` plus up to 14 message cells and three continuation rows with a four-space prefix plus up to 14 cells. Identifier underscores become spaces; controls and whitespace collapse; unsupported glyphs become visible `?`; missing identifiers show `unknown`. Messages preserve supported path punctuation and underscores, use `needs attention` when missing, wrap words and hard-break long words across the four message rows, and end the final content row with `...` when truncated. Unused continuation rows are empty. PlaybackRuntime owns this layout; Pi consumes the resulting rows.
- `PlaybackRuntime::latched_errors` is the sole canonical owner of presented runtime-error visibility. While its top error is visible, ordinary physical `DeviceInput` messages are rewritten internally and never forwarded to platform adapters; `requestSnapshot: false` is ignored on this gated path. Awake `DeviceInput::ButtonA { pressed: Some(true) }` (the Back button) or `DeviceInput::EncoderPress { id: Some("main") }` dismisses only the exact captured top error; the transaction then emits the underlying menu/modal/OLED snapshot. A dismissal does not restart transport or emit any action/effect/event/command. Every other input, including button releases, encoder turns, aux inputs, grid presses/releases, and `Other`, is consumed without changing the underlying state. Wake handling still has precedence: the first input that wakes the OLED is consumed as wake input and does not dismiss the error frame.
- While the error gate is active, Shift/Fn/combined-modifier press and release inputs update only their physical pressed/held state. They do not execute mapped controls, and dismissal does not blindly clear a modifier that is still physically held; a release received during the error gate reconciles the held state before the underlying UI is restored.
- The runtime error frame shows the compact `Back/Press: close` affordance below the fixed metadata/message rows.
- A visible setup portal modal has priority after confirmation dialogs and ahead of system-info and help modals.
- A visible Backup / Restore card has the same modal priority after confirmation dialogs and setup-portal presentation, ahead of system-info and help modals.
- Bottom-right corner: transport icon (`▶` / `⏸` / `■`), hidden while a footer toast is active
- Transport color: the native snapshot owns the NeoKey presentation. Back is red; Space is red stopped, blue paused, dim green while playing at rest, yellow on beat flashes, and green on measure flashes. Combined modifiers are blue, held modifiers are yellow, and inactive modifiers are dim gray.
- Event-dot and transport-flash presentation uses native monotonic deadlines: 45 ms for the event dot and 90 ms for beat/measure flashes. A visible start, flash-kind change, or expiry transition forces one snapshot; same-state retriggers extend only.
- Aggregate audio-load telemetry is separate from worker warning presentation. Recent voice stealing turns the active event dot magenta; aggregate load and voice-steal status remain on the desktop audio-load bridge and do not drive the worker icon.
- Persistent-worker CPU icon: red at `(117,5)` only when valid persistent worker metrics report `high_cpu_steady`; missing or inline metrics hide it. A missed-quantum flash has priority in that same CPU slot and uses the inverted white/black CPU glyph, so the red CPU icon is hidden while the miss is active. The save icon remains yellow at `(107,5)` and may coexist with either CPU-slot state. A newly missed persistent quantum replays the previous final master quantum exactly once when its frame count matches; otherwise it emits silence, and subsequent refills during recovery emit silence. `missedQuantumFlash` is armed for five emitted seconds (`sampleRate * 5`), clears on the exact emitted-frame crossing, and resets on a later miss. These status transitions do not change the existing OLED layout or coordinates.
- Toast text: displayed at bottom for feedback messages

NeoKey snapshot contract:

- `neoKeyLeds.back`, `.space`, `.shift`, and `.fn` are required native RGB values before brightness scaling. Desktop and Pi apply the same basis-point rule: normal scale is `buttonBrightness * 100`; dimmed scale is zero for zero brightness, otherwise `max(buttonBrightness * 8, 400)`; each channel is `(channel * scale + 5000) / 10000`.
- `eventDotOn`, `transportIcon`, and `transportFlash` are required top-level snapshot fields. `transportFlash` is not duplicated under `settings`.

## Grid Coordinate Boundary

- The fixed grid is 8×8. Native behavior/world coordinates use a lower-left origin: `(0,0)` is bottom-left and `y` increases upward.
- Display and hardware frames use top-left row-major order at the boundary. `platform-core` owns the pure logical row-major and logical/display projection helpers; `playback-runtime` delegates its existing display-index API to them.
- Desktop `GRID_DOMAIN` remains a deliberate boundary mirror for input/rendering and is checked against every cell in `resources/grid-projection-v1.json`. The fixture is verification data, not a runtime projection table.
- HAL NeoTrellis wiring remains fixed adapter data: four device quadrants, physical keys, device addresses, and GRB output are kept separate from the shared world/display projection.

Value editing semantics:

- Number/enum/bool rows enter edit mode on Main press; Main or Back finishes the row. At the Save Setting choice, Back means Cancel; at the Restart? choice, Back means Continue.
- Navigation memory is limited to `System`, `System > Notes`, `System > Audio`, `System > Audio > Engine`, and `System > UI`. It is native, ephemeral, cleared on menu rebuild, and does not apply to any other menu, dynamic list, sample browser, preset list, MIDI port list, parameter picker, help, confirm dialog, or assignment overlay.
- `System > Audio > Engine` persists `runtimeConfig.dsp.workerWarningThreshold` as `70/75/80/85/90/95` with default `85`, and `runtimeConfig.dsp.busIdleThreshold` as `exact/-140/-120/-100/-80` with default `-120`. These typed settings propagate directly to the realtime engine without rebuilding prepared audio or changing structural render-plan revisions. Worker warning presentation and bus silence behavior are separate runtime phases.
- Steady high-CPU presentation uses persistent worker metrics only: the configured threshold is immediate, clearing requires utilization strictly below `threshold - 5 percentage points` for five rendered seconds, and equality remains in the hold band and resets clear accumulation. Absent worker metrics hide the icon. `DeadlineMiss` is native, nonterminal ownership recovery; a valid previous final master quantum is repeated once on the first matching missed quantum, then pending refills are silent until the late state recovers. `missedQuantumFlash` remains a native status flag for five emitted seconds, including exact boundary clearing and reset on a later miss; it does not alter the existing visual structure. Structural worker failures (`DispatchFailed`, `CompletionFailed`, `WorkerExited`, and `InvalidBlock`) remain sticky terminal states and do not enter this recovery path.
- `System > Notes` keeps the existing `sound.noteLengthMs`, `sound.velocityScalePct`, and `sound.velocityCurve` keys and semantics. `System > Audio > Perf. Mode` persists `runtimeConfig.sound.optimizeFor` as `latency|capacity`; its compact OLED values are `Lat` and `Cap` for the full Latency and Capacity choices, it is visible on Raspberry and Orange, and it is hidden on desktop. `System > Audio > Polyphony` keeps the existing `sound.voiceStealingMode` values `fixed12/fixed16/auto-soft/auto-balanced/auto-hard/none`; `Engine` keeps the existing DSP threshold keys and values. Neither performance mode changes voice or FX limits.
- `System > Saves` separates local device settings from portable music. `System > Saves > System` contains `Save System` and `Load System`; `System > Saves > Default` contains `Auto Save`, `Backups`, `Save Patch`, and `Load Patch`. `Library` keeps its named-preset actions unchanged. These actions use the same native input semantics on hardware and desktop.
- Restart-sensitive edits to Audio, `System > MIDI > USB Device > USB MIDI`, `System > Setup > USB Role`, and their output settings use the native confirmed System-only Apply flow and `Restart required.` warning. Its default is `Cancel`. A Host pre-save warning shows `Restart required.`, `Before Host reboot:`, `Unplug computer USB.`, and `Audio/MIDI/SD2 off.` The confirmed Apply saves the setting to the System file; it does not discard unsaved musical edits. A successful Host save shows `Restart?` / `Saved. Reboot to apply?` followed by `Unplug computer USB`, `before Host reboot.`, and `Audio/MIDI/SD2 off.`; non-Host acknowledgements retain the existing two-line dialog. Both use default `Continue` and optional `Reboot now`; stale or failed acknowledgements never reboot or advance the persisted baseline. Setting-only saves preserve unrelated dirty edits. `Start Transfer` and `Stop Transfer` under `System > SD Card 2` retain their existing modal/cancel behavior. General MIDI enable/input/clock/sync remains under `System > MIDI`.
- `System > Audio` exposes conditional USB Audio, conditional HDMI Audio, Master Vol, conditional Perf. Mode, Polyphony, and Engine in that order; the output rows are optional mirrors of the always-on Jack mix and are only on Pi boards. USB Audio is hidden and disabled in USB Host mode, while HDMI Audio remains visible. `System > MIDI` contains `MIDI Active`, then conditional `MIDI Host` and `USB Device` groups, then Sync / Clock. MIDI Active is the global runtime gate and selects no port or device. MIDI Host contains MIDI Out then MIDI In and is shown on desktop and Orange, and on Raspberry only in Host mode. USB Device contains USB MIDI and is shown on Orange and on Raspberry only in Gadget mode; it is the computer-facing gadget interface and automatically owns both Gadget MIDI input and output while enabled. Host-selected input/output IDs are ignored while USB Device MIDI is enabled; on Orange they are retained for later use after it is disabled. USB Device changes are restart-sensitive: pending edits do not change the live route until the next process startup. `System > Setup > USB Role` is Raspberry-capability-only and precedes Updates. Host also hides SD Card 2 Start Transfer while retaining Stop Transfer for cleanup, and Gadget does not restore previously disabled outputs. `System > SD Card 2` contains Start Transfer and Stop Transfer; the second card is exposed to a USB host only while conflicting USB audio, MIDI, and recording are inactive. `System > HDMI Video` contains the existing HDMI display controls; SD Card 2 and HDMI Video are board-only. HDMI Audio is independent of HDMI video. Simultaneous physical outputs use independent unsynchronized clocks and can drift or echo; this phase does not provide sample alignment.
- `System > Reboot` and `System > Shutdown` confirm before emitting their native effects, after the recovery-save effect. One board-neutral terminal lifecycle requires that save to succeed, atomically stops non-terminal follow-ups and new input, independently attempts external MIDI panic and internal audio silence, then only after both succeed publishes and physically acknowledges the final shutdown/reboot snapshot and LED/OLED state before submitting the board-specific fixed power request. Save, safety, terminal acknowledgement, and power-submission failures are typed/logged and never resume normal follow-ups incorrectly. The exact ordinary-menu toasts remain `Rebooting` and `Shutting down`; the OLED frame stays preserved while native hardware teardown completes. Raspberry uses the exact noninteractive power commands allowed by `/etc/sudoers.d/octessera-shutdown`, with no broad `NOPASSWD` grant. Orange uses its fixed root-owned `/run/octessera-device-apply/reboot.sock` with exact `reboot\n` and `poweroff\n` requests and exact `accepted\n`/`rejected\n` responses. Orange reboot still validates persisted config in the root helper; poweroff does not depend on that config validation. This bounded contract applies to confirmed instrument-menu actions, not arbitrary administrative `systemctl poweroff` or `systemctl reboot` commands.
- `System > Setup > Updates > Check` emits `RuntimePlatformEffect::UpdateCheck` without confirmation. On supported Raspberry Pi hosts, the updater reports whether the GitHub release contains the installed profile's ZIP/checksum pair. On Orange, Check/Apply/Rollback use the root-owned broker and guarded updater with the explicit profile-qualified `octessera-<version>-orange-pi-zero-2w-runtime-updater-aarch64.zip` and `SHA256SUMS-orange-pi-zero-2w-runtime-updater.txt` pair. These actions update only the managed runtime release; full Armbian, kernel, device-tree, and image replacement remains manual, and the standalone manual runtime ZIP is not an OTA asset. Orange profile, asset, manifest, checksum, and health mismatches fail closed; it never consumes Raspberry assets or falls back to the manual ZIP or image path. On desktop, Check opens the GitHub releases page; desktop Apply and Rollback report unsupported. On supported Raspberry and Orange hosts, Apply and Rollback confirm first, stage the candidate or previous runtime release, and schedule guarded validation. The immediate Apply result may be `Update health validation scheduled.`; it is not a completed-update result. The guard validates process identity and stability before committing; downloaded Apply candidates also require profile/version readiness, and a failed validation automatically restores the previous release. Legacy installations must be provisioned or updated with the current OS bundle, or reflashed, before online apply; the legacy updater must not apply new releases.
- On the Orange production runtime, native musical events, runtime audio commands, and silence route through the realtime engine at the shared 44.1 kHz runtime rate. Jack is always-on primary; selected USB or HDMI audio routes are optional mirrors of the canonical Jack mix. Readiness depends on Jack; an absent, waiting, or faulted optional mirror is route-local and never blocks or replaces Jack. HDMI audio is separate from HDMI video, and simultaneous physical outputs are not sample-synchronized. MIDI uses the native host adapter, including USB MIDI when the configured gadget port is present. The service polls NeoTrellis/NeoKey over `/dev/i2c-2` at about 10 ms and uses the native gpiocdev v2 encoder path for all four encoders. Orange HAL descriptors reverse each literal board A/B net at the event boundary so all four produce canonical turn direction without changing shared quadrature decoding. AUX2 A/B offsets 227/269 are always requested; switch offset 224 is omitted only while UART0 is active and is requested once the dedicated UART0-disabled input-routing overlay is applied. Lower-left grid and GRB output semantics remain unchanged.
- `System > Sys. Info` opens a native loading popup and emits `RuntimePlatformEffect::SystemInfoRequest`. Desktop and Pi return an asynchronously identified, sanitized `RuntimeSystemInfo` containing OS/version, Octessera version, primary IP/MAC when available, hostname, and explicit board profile. The desktop UI only renders the resulting snapshot.
- `System > Setup > Configure WiFi` uses stable key `system.configureWifi` and keeps its existing confirmation and native setup-portal behavior. `System > Setup > Backup / Restore` uses stable key `system.backupRestore` and remains a direct, unconfirmed action. Updates and Hardware Test remain under Setup without action-key changes.
- `System > Setup > Show Hold` is board-only (Raspberry and Orange) and follows Updates. `Hold 48h` (`maintenance.hold`) and `Release` (`maintenance.release`) are direct, unconfirmed actions that emit `RuntimePlatformEffect::MaintenanceHold { active }` and show the `Show hold: 48h` / `Show hold released` toast. The board writes or removes `/var/lib/octessera/show-hold/until` (Unix expiry seconds); the images' `ExecCondition` drop-ins skip fstrim, logrotate, dpkg-db-backup, systemd-tmpfiles-clean, and the Raspberry network-health logger while that time is in the future and no more than about 48 h away. Skipped jobs run at their next schedule; the hold survives reboots. Desktop reports it as board-only.
- `System > HDMI Video` displays `Mode` as `Terminal | live-grid | plain-grid | active-behavior | cycle-behaviors` and persists the canonical `runtimeConfig.hdmi.mode` value (`none|live-grid|plain-grid|active-behavior|cycle-behaviors`, default `none`). `Terminal` is the compatibility label for stored/runtime `none`; it releases and disables Octessera framebuffer output so Linux terminal ownership can show, while snapshots retain their existing black/inactive HDMI grid semantics. `Bars per cycle` appears only in `cycle-behaviors` mode.
- `System > Bluetooth` is board-only. It contains `Bluetooth` (key `bluetooth.enabled`, persisted as `runtimeConfig.bluetooth.enabled`, default Off) and, only while it is On, `Audio Out`, `Devices`, `Pair New`, and `Forget`. The setting powers the board radio; Off powers it down. `Audio Out` (key `bluetooth.audio`, persisted as `runtimeConfig.bluetooth.audio`, default Off) sends a copy of the final mix to the first paired, connected speaker: the primary callback fills a bounded, never-blocking monitor tap, and a background feeder (SCHED_OTHER, nice 10, on the DSP cores) plays it through bluez-alsa. Monitor audio is dropped under pressure, lags by a few hundred milliseconds, and never changes the wired outputs; a disconnected speaker simply stops it. `Devices` lists paired devices as `name [kbd]` or `name [audio]` with ` - on` for connected ones, and pressing a row connects or disconnects it. `Pair New` emits `BluetoothScan { active: true }` when it opens and `active: false` when Back leaves it; it opens while still empty and lists found unpaired keyboards and speakers. Pressing a row pairs, trusts, and then connects the device; a passkey shows as a modal, and Back or a Main click cancels pairing. `Forget` removes a pairing. Results and failures arrive as `BluetoothStatus` toasts. While Bluetooth is On, keyboard capture also accepts Bluetooth keyboards under the same HDMI gate, so Raspberry Gadget can be played from a Bluetooth keyboard.
- Hardware HDMI timing can be sampled on Pi/Orange Pi without framebuffer writes using `cargo run -p octessera-pi --bin octessera-pi-hdmi-bench --release`.
- `System > Recording` persists `runtimeConfig.recording.maxMinutes` with default `10` and clamps to `1..120`; the same limit applies to WAV and Audio+OLED AVI. `Start Audio` emits `RuntimePlatformEffect::RecordingStartAudio { max_minutes }` and writes 44.1 kHz stereo signed-16 little-endian PCM WAV. `St. Audio+OLED` emits `RuntimePlatformEffect::RecordingStartAudioOled { max_minutes }` and writes an AVI with 128x128 MJPG video at 10 fps plus 44.1 kHz stereo signed-16 little-endian PCM audio. Audio is the master clock, so each video frame advances every 4,410 audio frames and accepted OLED frames are held between updates. `Stop` emits `RuntimePlatformEffect::RecordingStop` and is safe when idle. Both actions capture the final internal stereo output; external MIDI instrument audio is not captured.
- Recording roots are fixed by host adapter: desktop uses the Tauri Audio/Music directory under `Octessera/recordings` for WAV and `Octessera/screen-recordings` for Audio+OLED; Raspberry uses `/home/pi/recordings` and `/home/pi/screen-recordings`; Orange uses `/var/lib/octessera/recordings` and `/var/lib/octessera/screen-recordings`. A reserved `.partial.*` file becomes `.wav`/`.avi` after successful finalization, or `.incomplete.wav`/`.incomplete.avi` after gaps, ingress overflow, or accepted-OLED material loss; failed workers retain the partial file and existing takes are never replaced.
- Recording feedback is native: a successful start shows `Recording started`; a duplicate start shows `Recording is already running`; manual Stop shows `Recording saved` or `Recording incomplete`; clean max-duration completion shows `Max time: saved`. While active, recording keeps the OLED awake without changing the saved `OLED Sleep` setting, and normal idle sleep timing restarts when recording ends.
- Browsing selected values are shown on the selected label row; edit mode uses a separate value-focused row for clarity.
- Breadcrumbs use full labels for the current submenu and short labels for ancestors, e.g. `/S/FX/Bus 1` and, one level deeper, `/S/FX/B1/Slot 1`. Top-level ancestors use `Build`/`B`, `Link`/`L`, `Shape`/`S`, `Play`/`P`; layer ancestors use `Layer N`/`LN`; FX bus ancestors use `Bus N`/`BN`. Overlong breadcrumbs are front-ellipsized with `...` so the current location remains visible. Section color follows the canonical section path, not the truncated display text.
- Menu items that lead to a submenu or selector render with a trailing `>` marker. `Build > Layer > Behavior: <id>` is a synthetic browser-style selector, not an editable enum. It groups behavior items under `[Human]`, `[Rhythm]`, `[Musical]`, then alphabetically under `[Cellular]`, `[Fields]`, `[Geometry]`, `[Growth]`, and `[Motion]`, uses `..` items for parent navigation, and writes the selected native behavior ID to that layer's persisted `behaviorId` field. Human includes direct play plus `weave`; Rhythm includes `polyrhythm`, `breaks`, `fills`, `clave`, `groove`, and `euclid`; Musical includes `ostinato`, `motif`, `canon`, `chords`, `contour`, `cadence`, and `phrase`. Selecting a behavior uses a targeted native Build refresh for that layer and does not rebuild the full menu tree. `arp` is not a native Build behavior; arpeggiation lives under `Link > L* > Arp`. `glider` is no longer a behavior ID; its glider injection controls are part of `life`. `forest_fire` is the canonical Forest Fire behavior ID, with no `forest` alias. `bubbles` belongs to Motion; its current, drift, and buoyancy items use eighth-cell units per tick, and `Add Bubble` spawns one bottom-origin rising bubble immediately.
- Forest Fire renders trees and burning cells as visible, but event interpretation follows the behavior's trigger types: tree-to-fire and manual ignition emit activate triggers, burned-out cells emit deactivate triggers, visible non-burning trees are stable, and unrelated empty cells emit no event.
- `crystal_growth` is the canonical Crystal Growth behavior ID, with no `crystal` or `crystals` alias. It belongs to Growth before `dla`. `cross` grows through cardinal neighbors only; `diagonal` grows through diagonal neighbors only; `snowflake` grows through cardinal neighbors plus parity-selected diagonals: even `(x + y)` uses NW/SE, odd uses NE/SW. Grid press seeds or refreshes the exact lower-left world-space cell without toggling it off or changing its phase; scheduled/action seeding chooses deterministic cells.
- `lightning` is the canonical Lightning behavior ID, with no aliases. It belongs to Fields before `raindrops`. Target edges use lower-left world space: north is `y=max`, south is `y=0`, east is `x=max`, and west is `x=0`; automatic strikes seed from the opposite edge. On the connection tick, all visible lightning cells emit activate once, then remain stable during decay and deactivate when cleared.
- `kuramoto` is the canonical Kuramoto behavior ID, with no aliases. It belongs to Fields before `lightning`. Cells are visible only near the sync/wrap window; phase wraps emit activate, stable sync-window cells stay quiet, grid press sets the exact lower-left world-space cell just before wrap and emits activate, and `Desync Pulse` perturbs phases without immediate activate events.
- `wave` is the canonical Wave behavior ID, with no aliases. It belongs to Fields near `raindrops` but uses oscillating displacement/velocity rather than ripple rings or diffusion. Grid press applies an impulse to the exact lower-left world-space cell and emits activate; threshold crossings activate/deactivate as the wave propagates and damps. `Impulse Interval` and `Spawn Step` schedule deterministic small impulses so the default patch keeps breathing.
- `gravity` is the canonical Gravity behavior ID, with no aliases. It belongs to Motion after `bubbles`. It is falling granular sand only: gravity directions use lower-left world space, movement into a new cell activates the destination and deactivates the origin, unchanged settled grains are stable, and near-saturated/stalled defaults drain a few settled grains instead of staying full.
- `boids` is the canonical Boids behavior ID, with no aliases. It belongs to Motion after `bubbles` and `gravity`. It renders many quantized flocking agents; cell entry activates, vacated cells deactivate only when no boid remains, and scatter changes velocity without immediate activation.
- `orbit` is the canonical Orbit behavior ID, with no aliases. It belongs to Motion after `boids`. Particles orbit one moving attractor; particle cell entry activates, vacated cells deactivate only when no particle remains, and attractor-only cells render stable except press/reset forced accents.
- `sand_ripples` is the canonical Sand Ripples behavior ID, with no aliases. It belongs to Motion after `orbit`. It models wind-driven grain transport and migrating crests, with no water flow or gravity avalanche behavior; saturated defaults shed tiny deterministic gaps so dunes keep moving.
- `lava_lamp` is the canonical Lava Lamp behavior ID, with no aliases. It belongs to Motion between `boids` and `orbit`. It renders soft moving blobs/metaball-like fields that merge and split; it is not flocking, orbiting, or passive diffusion.
- `ink` is the canonical Ink behavior ID, with no aliases. It belongs to Fields before `ising`. Ink diffuses toward cardinal-neighbor average and fades; direct drops force activate, passive threshold crossings activate/deactivate, and low pigment remains quiet. `Drop Interval` and `Spawn Step` schedule deterministic small drops for default liveness.
- `ising` is the canonical Ising behavior ID, with no aliases. It belongs to Fields between `ink` and `kuramoto`. It models binary magnetic domains with temperature, noise, and field bias; spin flips to +1 activate, flips to -1 deactivate, unchanged +1 cells remain stable, and -1 cells are quiet.
- `reaction_diffusion` is the canonical Reaction-Diffusion behavior ID, with no aliases. It belongs to Fields between `raindrops` and `wave`. It uses two-chemical Gray-Scott-style integer pattern formation; B concentration drives visibility, upward threshold crossings activate, downward visibility crossings deactivate, and grid presses splash chemicals into the exact lower-left world-space cell plus cardinal neighbors. `Seed Interval` and `Spawn Step` schedule deterministic small chemical splashes for default liveness.
- `rivers` is the canonical Rivers behavior ID, with no aliases. It belongs to Fields between `reaction_diffusion` and `wave`. It models water flow over height with erosion/deposition, cardinal non-wrapping downhill movement, and visible water threshold triggers.
- `cracks` is the canonical Cracks behavior ID, with no aliases. It belongs to Growth before `crystal_growth`. Crack tips propagate through stressed cells, new tips activate, stress-only cells are stable/quiet, and shatter/replace removes visible pane cells in bounded staged passes with deactivate triggers.
- `coral` is the canonical Coral behavior ID, with no aliases. It belongs to Growth before `cracks`. Exposed cardinal colony surfaces grow, adjacent opposing colonies become skeletons instead of directly converting, breakaway clearing deactivates removed cells, and full defaults thin a few cells deterministically instead of staying solid.
- `physarum` is the canonical Physarum behavior ID, with no aliases. It belongs to Growth after `dla`. Bounded agents follow trail and food, deposit evaporating memory, food is stable/quiet, and seed slime forces new agent-cell activate accents.
- `vines` is the canonical Vines behavior ID, with no aliases. It belongs to Growth after `physarum`. Directional tendril tips seek light and open space, branches reserve empty cells without wrapping, pruning deactivates removed vines, full defaults shed a few old cells deterministically, and direct planting uses exact lower-left world-space cells.
- `fractal_explorer` is the canonical Fractal Explorer behavior ID, with no aliases. It belongs to Geometry before `shapes`. It dynamically samples Mandelbrot/Julia regions with drift and zoom; class increases activate, class disappearance deactivates, and grid press recenters the exact world-space cell with a one-shot forced activate. Its mode action key is `toggleFractalMode`.
- `maze_growth` is the canonical Maze Growth behavior ID, with no aliases. It belongs to Geometry between `fractal_explorer` and `shapes`. It carves one-cell corridors from frontiers, moves walkers over visible cells, never wraps neighbors, and collapse/removal deactivates visible cells.
- `predator_prey` is the canonical Predator–Prey behavior ID, with no aliases. Grass persistence and regrowth are visible, quiet `Stable` background events; animals emit activate on entry, birth, and reseed, deactivate on move-out or death, and stable while persisting. Predator eating a herbivore adds a one-tick trigger-only cardinal burst without mutating neighbor cells, so visible grass cells may briefly emit activate as predator-event accents. Saturated defaults reopen a few cells instead of staying full.
- `twinkle` is the canonical Twinkle behavior ID, with no aliases. It keeps a deterministic 1–5 star cap, with `Activate` on births, `Deactivate` on deaths, `Stable` on persisting stars, and quiet inactive cells. A manual birth at the cap replaces one deterministic existing star. One tick may perform at most one eligible fade and one birth; `Star Life` gates fading, and `Cluster Bias` selects clipped, non-wrapping neighborhoods versus global empty cells. Missing saved cells seed the deterministic default, while an explicit empty array stays empty. `Reseed Stars` and `Clear Stars` are the only Twinkle actions; Build `Reset` remains the generic behavior reset.
- `cyclic` is the canonical Cyclic behavior ID, with no aliases. It belongs to Cellular between `brain` and `forest_fire`. Cells chase the next discrete state through a clipped Moore neighborhood; advancement emits activate except wrap-to-zero, which emits deactivate. Zero cells are inactive and quiet.
- Bool behaves like a 2-option enum (`off`/`on`) and changes on encoder turn, not immediate row press
- Named target selectors (instrument slot, layer index, mixer route) display their computed names via `formatDisplayValue()` (e.g. `I1: synth`, `L3: rain`, `fxb2`)
- The instrument target enums under `Link > Layer > Scanning` and `Link > Layer > Events` keep canonical options as `I#: name`; their unselected rows show only `I#`, while the selected item uses exactly two body rows: its plain item-specific heading followed by the selected `> I#: name` detail (or `>* I#: name` while editing). Long selected details scroll horizontally in both browsing and edit mode. Other named selectors retain their existing presentation.
- Behavior `none` hides Build Step Rate, dynamic behavior config rows, and Reset while preserving stored values. Instrument Type `none` hides Note Mode, engine-specific params, mixer/MIDI rows, and Slot Actions while preserving stored config.
- `Shape > Instruments > I# > Type` offers `fm` (shown as `FM`) alongside synth, sampler, and MIDI. An FM slot keeps Type, Note Mode, FM, Mixer, Auto Label, Name, and Slot Actions in that order. FM opens to seven rows: `Preset >`, `Tone >`, `Index Env >`, `Filter >`, `Volume >`, `Amp Env >`, `Filter Env >`; all fit below the OLED title. `Preset > Load` offers Init, Soft Keys, and Bell for this slot's FM settings. Tone contains exactly Ratio (`0.5|1|2|3|4|5|6|8`, default `2`, displayed as `1:2|1:1|2:1|3:1|4:1|5:1|6:1|8:1`), Fine cents (-100..100, default 0, shown with sign and `c`), Index (0..100, default 50, mapped to 0..4 radians), Vel to Index (0..100%, default 0), Mod Shape (0..100%, default 0), and Mod Mix (0..100%, default 0), in that order. The six Tone rows fit on the existing OLED body. Fine cents offsets the modulator interval relative to the carrier, not carrier tuning. Vel to Index scales harmonic depth rather than directly scaling amplitude or Volume; Mod Shape blends a second harmonic when Index is above 0; Mod Mix adds audible modulator tone even at Index 0 and can reinforce at Ratio 1. Tone edits can reshape notes already ringing. Index Env starts at Attack 0 ms, Decay 250 ms, Sustain 20%, Release 120 ms. Volume starts at Gain 80%, Vel Sens 100%; Amp Env starts at 5/300/70/350. FM Filter and Filter Env use Synth's control scales and defaults, saved under this slot's own `fm` block. Use the familiar edit encoder and Back to nudge the tone; FM audio follows the same Mixer and FX bus path as Synth, while MIDI remains external.
- FM parameter binding pickers expose Index, Volume Gain, Filter Cutoff, and Filter Res as numeric targets for modulation, XY, and Aux. Their saved labels carry an `FM` prefix and fit on the OLED's selected Current row. Ratio and Filter Type stay menu selectors, not continuous binding targets.
- `Shape > Instruments > I# > Type` also offers `pluck` (shown as `Plucked`). A Plucked slot keeps Type, Note Mode, Plucked, Mixer, Auto Label, Name, and Slot Actions in that order. Plucked opens to six rows: `Preset >`, `String >`, `Filter >`, `Volume >`, `Amp Env >`, `Filter Env >`, all below the OLED title. `Preset > Load` offers Init, Nylon, Steel, and Muted for this slot's Plucked settings. String has seven rows in order: Decay (`100..5000 ms`, default `1500`), Brightness (`0..100%`, default `65`), Pick Pos (`5..50%`, default `25`), Pick Depth (`0..100%`, default `65`), Stiffness (`0..100%`, default `0`), Body Amt (`0..100%`, default `0`), and Body Hz (`100..2000 Hz`, default `500`). These fit the existing seven-row OLED body. Decay and Brightness edits can reshape ringing notes; the four new String controls apply to the next pluck. Pick Depth changes excitation color, not Pick Pos or Brightness. Stiffness shapes wire-like inharmonic upper partials; it is not a literal material, weight, or tension model. Body Amt adds coloration outside the string feedback, and Body Hz moves that coloration rather than shared Filter cutoff; Body Hz is dormant at zero Body Amt. Volume starts at Gain 80% and Vel Sens 100%; Amp Env starts at 0/0/100/900. Filter and Filter Env keep Synth's scales and defaults but save under this slot's `pluck` block. Use the normal edit encoder and Back. Plucked audio uses the same Mixer and FX bus path as Synth and FM.
- Plucked binding pickers offer numeric Decay, Brightness, Pick Pos, Gain, Filter Cutoff, and Filter Res. Decay and Brightness adjust ringing strings; Pick Pos shapes the next pluck and does not change a note already ringing. Filter Type and instrument Type are not smooth numeric targets.
- Sampler binding pickers offer Tune, Gain, Base Velocity, velocity sensitivity/levels, and Filter Cutoff/Res as audible audio targets. Filter Type, Env Amount, Key Tracking, Amp Env, and Filter Env remain editable and saved in the Sampler menu, but are not currently rendered as sampler audio controls and are not offered as new binding targets.
- `Sampler > Kit > Load` is the first Sampler group; Sample Slot, the loaded sample, Browse, Assign, Tune, Gain, Base Velocity, optional Vel Levels group, Vel Levels switch, Filter, Vel Sens, Amp Env, and Filter Env retain their relative order. SDB Kit, Synth Kit, and Dist Kit replace this slot's eight sample paths, not its cell assignments/per-cell levels, selected sample slot, or other sample settings. The browser still offers `..`, folders, files, `(empty)`, and Space preview; loading a kit does not preview it.
- `Shape > Instruments > I# > Type` also offers `drum` (shown as `Drum`). A Drum slot shows Type, Drum, Mixer, Auto Label, Name, Slot Actions; Note Mode is hidden because hits are always one-shot. Drum has eight rows: `Kit >`, Voice, `Edit >`, Assign, Cell Tune, Preview, `Filter >`, `Volume >`. The OLED shows seven body rows at once; turn to scroll down to Volume without covering the footer. `Kit > Load` offers Default, Tight, and Heavy: loading changes eight voice sounds/settings, not mapped cell references or their tune offsets. Voice lists `V1: Kick` through `V8: Rim`, deriving each name from its current Sound. Edit preserves Sound (`kick`, `snare`, `closed_hat`, `open_hat`, `low_tom`, `high_tom`, `clap`, `rim`), Tune (-12..12 semitones), Decay (20..2000 ms), Tone (0..100%), and Attack (0..50 ms), then appends Sweep st (0..36 semitones), Sweep ms (0..200 ms), Noise % (0..100), and Level % (0..100). The nine Edit rows scroll within the existing seven-row OLED body. For legacy data missing these controls, Sound defaults are Kick 24/55/12/100, Snare 3/25/80/100, Closed/Open Hat 0/0/95/100, Low Tom 8/70/15/100, High Tom 6/50/15/100, Clap 0/0/95/100, and Rim 0/0/35/100 (Sweep st/ms/Noise %/Level %). Sweep and Noise shape the next hit, not one already ringing; Sweep ms at 0 causes no pitch excursion even when Sweep st is positive. Noise % blends noise against pitched tone. Level % attenuates the selected kit voice, not kit-wide Gain. Sound resets that voice's style controls; other voices and cell offsets stay put. Drum keeps its own Filter and Volume values using Synth's control scales, with default Gain 80% and Vel Sens 100%; no Amp Env or Filter Env page.
- The four per-slot Load lists use the existing Synth preset confirmation: choosing an entry opens confirmation with Cancel selected; nothing changes until Confirm. A confirmed load affects only that slot and shows which slot, type, and entry was loaded; custom names and mixer routing remain. No load action plays an automatic preview. `System > Saves` is still the separate whole-patch workflow, not a per-slot kit save manager.
- Assign maps the selected voice onto grid cells with the Sample Assignment gestures: plain press sets/replaces or toggles that cell, Shift+press edits its whole world-space row (bottom row `y=0`), combined modifier+press edits its column. Assignments start empty, never auto-fill the grid; Back exits without undoing work. Cell Tune picks an assigned cell and edits that cell's -24..24 semitone offset; empty cells report `No drum here`, and Back returns to selection, then exits. Preview plays the selected voice at its own Tune with zero cell offset through the main encoder, without Space or the sample browser. Numeric kit Tune/Decay/Tone/Attack bindings change **next hits**, never ringing hits; slot Gain/Filter Cutoff/Res remain live targets. Voice, Sound, cell offsets, Filter Type, and instrument Type are not smooth numeric targets.
- `Play > Drums` is seventh in the Play page list (Fn+right world `y=6`), leaving rows 0..5 alone. `Slot` displays `I#: Drum` for existing Drum slots and initially selects the first one for this session. The seventh Play row reads `No Drum slot` when none exists; the menu does not add a selectable guidance row. Assigned grid presses on the Drums page play one immediate hit even when stopped; releases are consumed. Empty cells/non-Drum slots are silent. This direct performance mode does not also invoke behavior, Link, or trigger probability. Outside it, behavior-triggered Drum hits still follow their normal Link/probability/timing path.
- Parameter target pickers mirror the main menu root order (`Build`, `Link`, `Shape`, `Play`, `System`) so modulation, Aux, and XY target browsing use the same mental model as normal navigation. Within `Build`, Behavior targets are generated per layer: layers with behavior `none` expose no behavior targets; real behavior layers expose their own Step Rate as `layers.N.algorithmStep` and config fields/actions as `layers.N.build.behaviorConfig.*`.
- Global Play XY and layer X/Y parameter-mod bindings may store optional user `Range Min`/`Range Max` values. These constrain modulation output while preserving the target capability `min`/`max` metadata. Enum and bool bindings ignore user ranges.
- `Play > XY` is ordered `X Axis`, `Y Axis`, `Smoothing`, `Invert X`, `Invert Y`, `Release`. `Smoothing` is `Off` at `0`, or `10–500 ms` in `10 ms` steps with a shipped default of `80 ms`; it displays `Off` or `<n> ms`. Raw XY markers update immediately, while mapped normalized axes glide independently from their current mapped values without overshoot before target range/step conversion. Elapsed time is monotonic; sample-hold retains and completes an active glide, reset-center moves the marker immediately to center and glides mapped axes to `0.5` when enabled, and inversion retargets only the affected mapped axis while the marker remains non-inverted.
- `Link > LFOs > L1..L8` is the canonical global exact-eight bank stored as `runtimeConfig.linkLfos`. Slots are not associated with layers. Targets are additive, numeric, and live-safe only; exclusive controls and every LFO configuration key are excluded. Phase and live contributions are transient and are not serialized; playback-runtime composes the current contributions once per affected endpoint and emits transient audio commands without mutating the persistent config.
- Layer X/Y, global Play XY, and global LFO target assignments are staged through the native claim validator. An exclusive target may have only one layer/Play claim, and an LFO may never claim one; rejected assignments leave the binding, contribution, revision, autosave state, and menu focus unchanged and show a bounded `Mapping rejected` toast. Accepted assignments and removals refresh the visible `Current:` claim label.
- Each layer has `Link > L* > Arp` stored as `layers.N.link.arp` with `mode`, `source`, `stepIntervalSteps`, `noteLengthMs`, `gatePct`, and `octaveSpread`. Defaults are `none`, `simultaneous`, `1`, `120`, `80`, and `0`. Sources are `simultaneous` routed note-on batches and playback-runtime tracked `held` notes; unsupported sources normalize to `simultaneous`. `none` preserves the normal Link path. Other modes emit finite note-ons using `noteLengthMs * gatePct / 100` and do not create held notes; matching note-offs update held membership and do not cut off arp-owned finite notes. `stepIntervalSteps` is clamped to 1..16, `noteLengthMs` to 10..2000, `gatePct` to 1..100, and `octaveSpread` to 0..3.
- Link event mappings (`activate`, `stable`, `deactivate`, `scanned`, `scanned_empty`) have per-target Delay and Retrig controls. Delay is counted in that layer's link ticks; Retrig is extra repeats after the original at delay+1, delay+2, and so on. Trigger probability is evaluated once before scheduling.
- Link collapses only same-tick NoteOn duplicates within one CellTriggerKind group and mapping context, after finalized instrument routing and before Delay/Retrig scheduling; it keeps the first event and duration and uses the highest velocity. Other event kinds, lanes, ticks, layers, mappings, and durations remain distinct.
- Musical timing selectors use the 24 PPQN vocabulary `1/32T`, `1/32`, `1/16T`, `1/16`, `1/8T`, `1/8`, `1/4T`, `1/4`, `1/2T`, `1/2`, `1/1T`, `1/1`. Straight `1/64` is intentionally not exposed because it is 1.5 pulses at 24 PPQN; triplet values are exact. Invalid timing labels use the canonical `1/8`/12-pulse default when presented in selectors; delay metadata continues to normalize invalid labels to the nearest note derived from `timeMs`.
- When `Number Style` is `bar` or `bar+numbers`, bounded sound/control/behavior number items keep the numeric value on the selected text row and render a compact bounded bar on the next body row, so the value is not shortened to make room for the bar. Bars use the current row/menu color, keep a visible bounding box for empty/partial/full states, render marker-style values as a tick inside the same box, and preserve contrast on highlighted rows.
- Bar display applies automatically to FX params, synth/FM/sample shaping controls, editable mixer volume/pan, FX bus volume/pan, Play FX controls, system sound/UI controls, Link axis controls, and behavior controls such as spawn interval/count, threshold, lifespan, and radius
- `Play > FX > Pitch Shift` exposes `Semitones`, `Cents`, `Slide In`, `Slide Out`, and `Mix`. Slide times are `10..3000 ms` in `10 ms` steps with defaults of `120 ms` and `180 ms`; pitch amount glides linearly in octaves, independently of the fixed `PITCH_FILL_FRAMES=1088` live-input fill and fixed 10 ms wet/dry anti-click envelopes.
- DLA has `Cell Life` (`0..256`, default `96`) so old aggregate cells age out and the cluster keeps renewing instead of filling the grid forever. `0` disables DLA aging/removal. If aging removes the whole cluster, DLA reseeds its small starter cluster.
- Selector-like numeric rows stay plain text, including MIDI channels, instrument/sample slots, layer selectors, and MIDI note ranges
- Structural selector edits apply immediately while the menu item is in edit mode through key-specific fast paths. This covers instrument type, instrument route, FX bus slot type, and master FX slot type. Behavior selection applies immediately when a behavior action item is pressed. Dynamic parameter menu items also apply immediately while editing.
- Runtime audio commands and full audio-config payloads use the same native normalization on desktop and Pi. Malformed instrument/FX payloads retain the last good audio state and surface a typed audio failure; sample preview resolves and decodes through the host adapter before entering the selected realtime instrument path.
- If a loaded sample cannot be found or decoded on the current platform, the native loaded-sample row and matching browser row display `N/A-<filename>` using the saved path's basename. The original path remains the replacement action's source and remains unchanged in patch/config payloads; available samples keep their normal names. Missing shipped `samples/...` files still fail audio preparation rather than becoming acceptable defaults.
- FX buses expose three ordered mono-chain slots: `Slot 1`, `Slot 2`, and `Slot 3`, with keys under `mixer.buses.N.slot1.*`, `slot2.*`, and `slot3.*`. When bus config is missing, the menu displays shipped defaults (`Slot 1: Delay`, `Slot 2: Duck`, `Slot 3: None`) rather than selecting the first option by accident. Old runtime/default configs that omit `slot3` load it as `none`; saved configs include explicit `slot3`. Global/master FX remains two stereo slots and does not expand with bus slot count.
- The Pi active bus FX warning budget is 12 active bus slots, matching the current 4 buses × 3 slots maximum after Pi DSP profiling. The warning budget excludes the two global/master FX slots and does not reject saved patches.
- Bus Delay FX exposes `Mix %`, `Spread %`, `Time Mode`, `Time Note`, and `Time ms`. Editing `Time Note` switches to note mode and materializes `timeMs` from the current BPM; later BPM edits retime note-mode bus Delays. Editing `Time ms` switches to ms mode and remains manual. Runtime/audio commands carry `timeMs` only, while `timeMode` and `timeNote` persist as patch metadata and are excluded from modulation, Aux, and XY binding targets. `Spread %` is 0..100 and widens only the final FX bus output; instruments, sampler voices, bus sends, and the FX slot chain remain mono. Delay Mix 0 with Spread 100 produces no widening.
- Bus Duck FX exposes `Source`, `Source Tap` (`pre|post`, displayed as `Pre|Post`), `Threshold` 0..1, `Amount %` 0..100, `Attack` 1..500 ms, and `Release` 1..5000 ms. For an Instrument source, `Pre` is the raw source before its fader; `Post` applies its fader before instrument-target momentary FX and pan. For a Bus source, `Pre` is the bus input before its fader and Slot 1→2→3 chain; `Post` applies that bus fader to the same pre-chain input. A bus input already includes routed instruments' faders and instrument-target momentary FX. Both modes exclude source-bus slot FX, bus-target momentary FX, spread/pan, global FX, and master volume. Missing `sourceTap` defaults to `pre` for legacy patches. These are the canonical menu, saved-config, and realtime ranges; accepted values are passed to the ducking renderer without a narrower downstream range.
- Bus input and Slot 1→2→3 processing remain mono. Bus `Volume`, `Pan Pos`, and delay `Spread %` apply only at the final bus output stage before summing into the main mix.
- Bar value text uses compact units where useful: `%`, `ms`/`s`, `Hz`, `bpm`, `dB`, semitones/cents, and pan as `L15`/`C`/`R15`; ambiguous internal `0..1` ranges display as `0..100`
- `Link > Swing` is a global groove amount. `0%` is straight timing. Swing delays internal off-beat step/scan progression and catches up before the next beat; external MIDI clock output remains straight.

Action row markers:

- `!` prefix means the row is an action item
- Plain action rows reduce one leading display space so the action text aligns visually with ordinary menu item text despite the `!` marker. Auto-mapped rows keep the normal alignment because `1-` and `1!` prefixes are equal width.
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

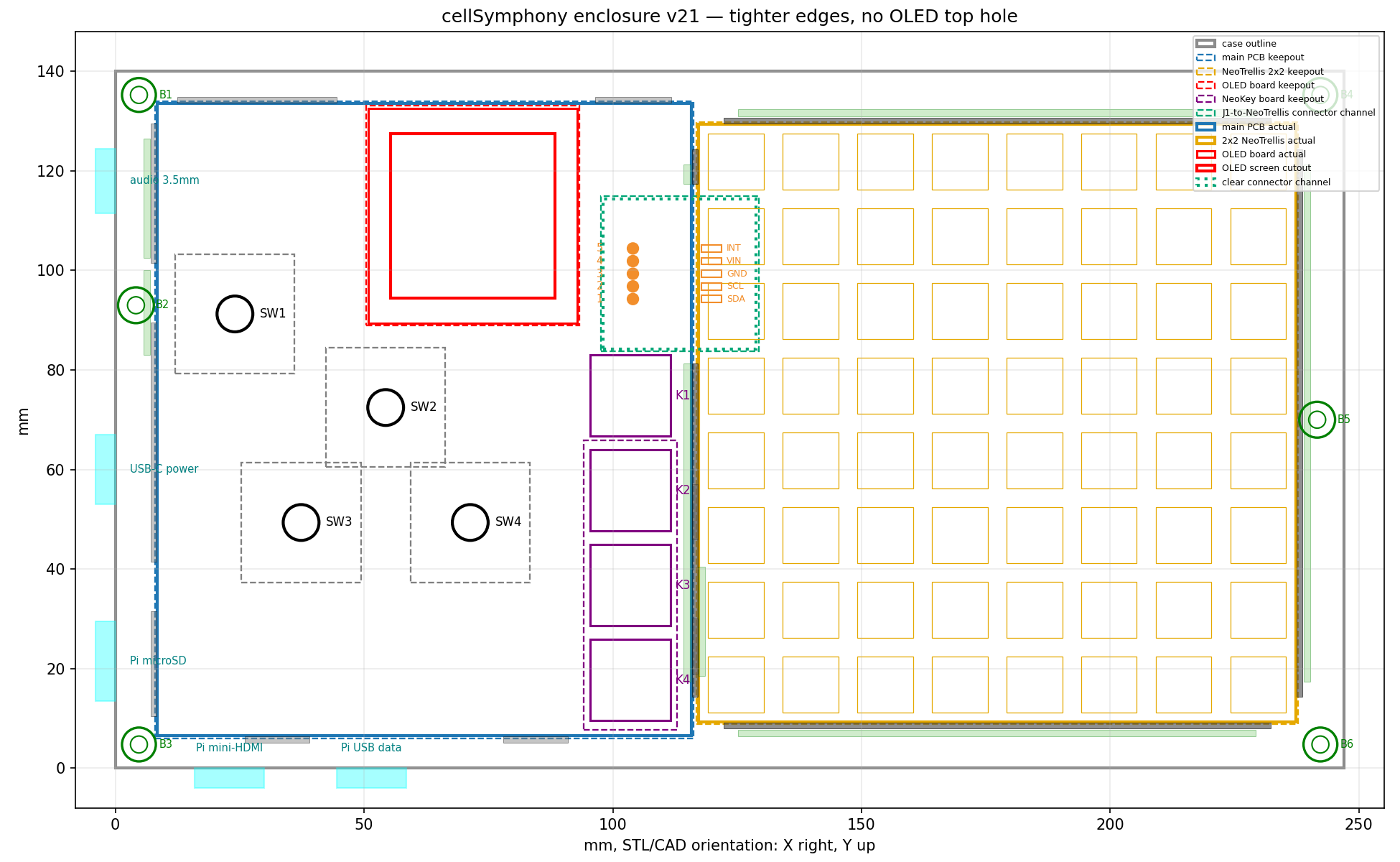
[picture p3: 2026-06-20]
hardware/enclosure/layout.png

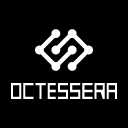
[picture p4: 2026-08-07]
assets/octessera-pi-booting.png

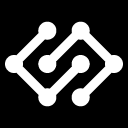
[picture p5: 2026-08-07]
assets/octessera-app-large.png

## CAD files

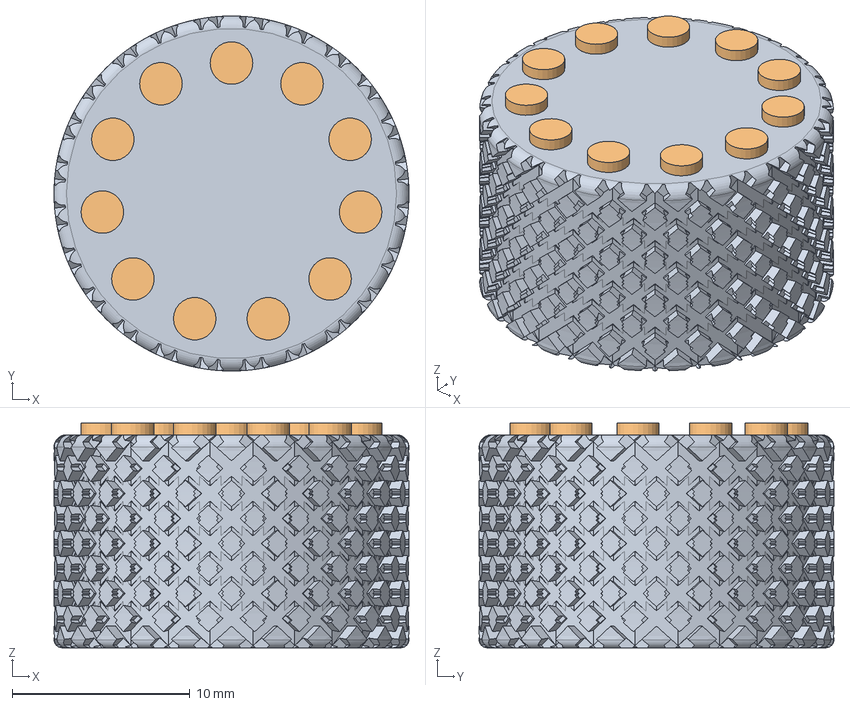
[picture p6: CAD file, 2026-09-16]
hardware/enclosure/step/encoder_cap_main_knurled_dots.step
20.0 x 20.0 x 12.7 mm

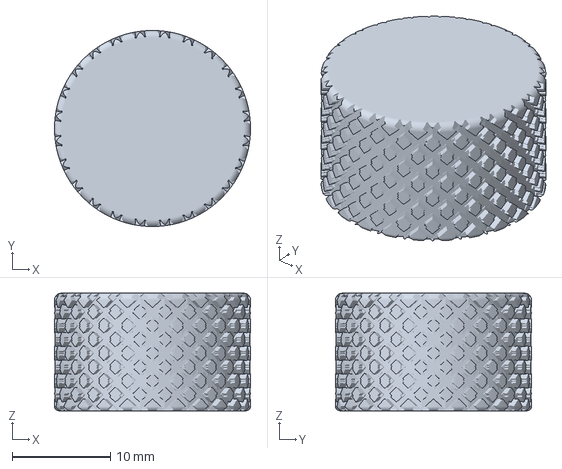
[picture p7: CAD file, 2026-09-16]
hardware/enclosure/3mf-multicolor/encoder_cap_main_knurled_dots_multicolor_flush.3mf
20.0 x 20.0 x 12.0 mm

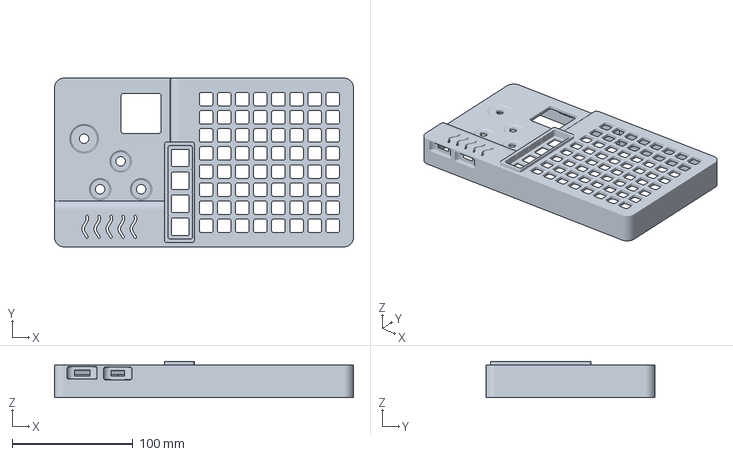
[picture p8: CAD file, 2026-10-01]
hardware/enclosure/3mf-multicolor/case_top_two_level_raspberry-pi-zero-2w_multicolor.3mf
248.0 x 140.0 x 30.0 mm

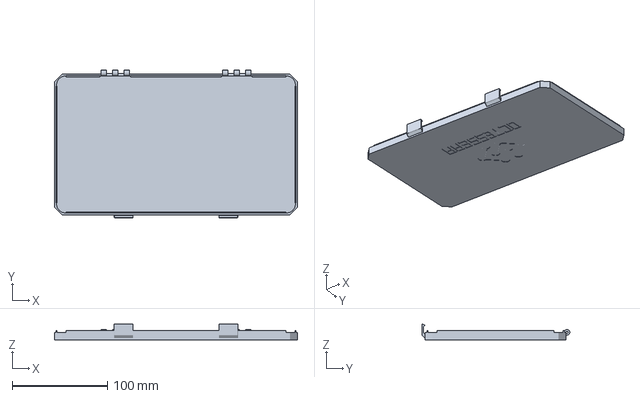
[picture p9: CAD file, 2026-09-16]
hardware/enclosure/3mf-single-material/protective_case_shallow_lid_debossed_branding.3mf
255.6 x 155.4 x 16.8 mm

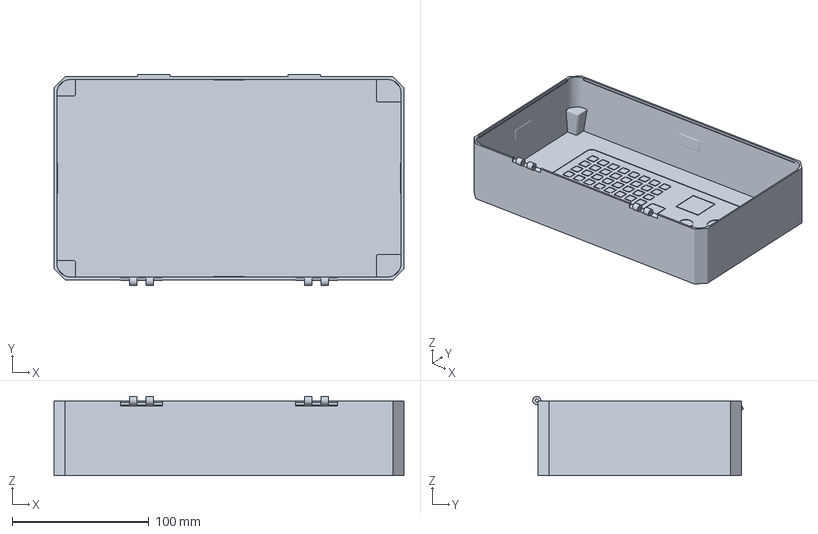
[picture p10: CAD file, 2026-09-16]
hardware/enclosure/3mf-single-material/protective_case_deep_tub_debossed_logo.3mf
255.6 x 153.8 x 57.8 mm

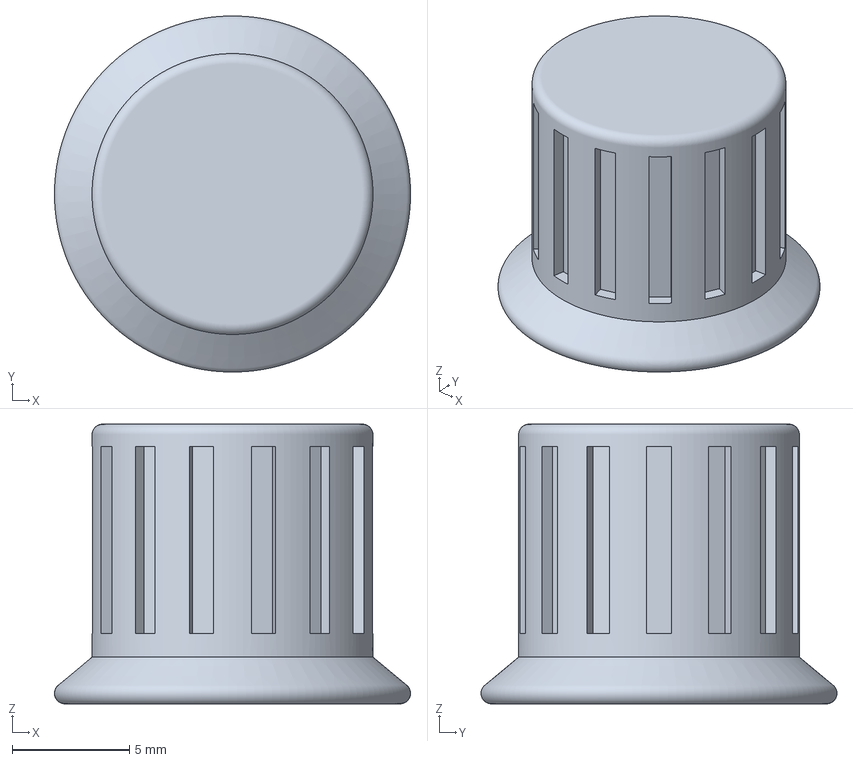
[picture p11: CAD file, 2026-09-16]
hardware/enclosure/3mf-multicolor/encoder_cap_aux2_ribbed_dots_multicolor_flush.3mf
15.2 x 15.2 x 11.9 mm

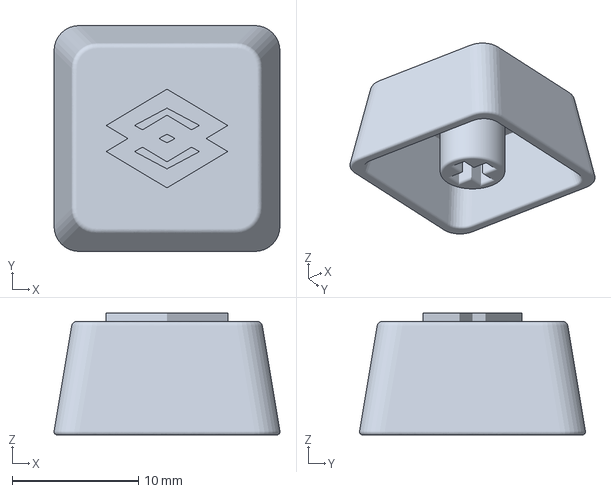
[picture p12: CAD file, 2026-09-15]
hardware/enclosure/3mf-single-material/mx_keycap_fn_layer.3mf
17.9 x 17.9 x 9.65 mm

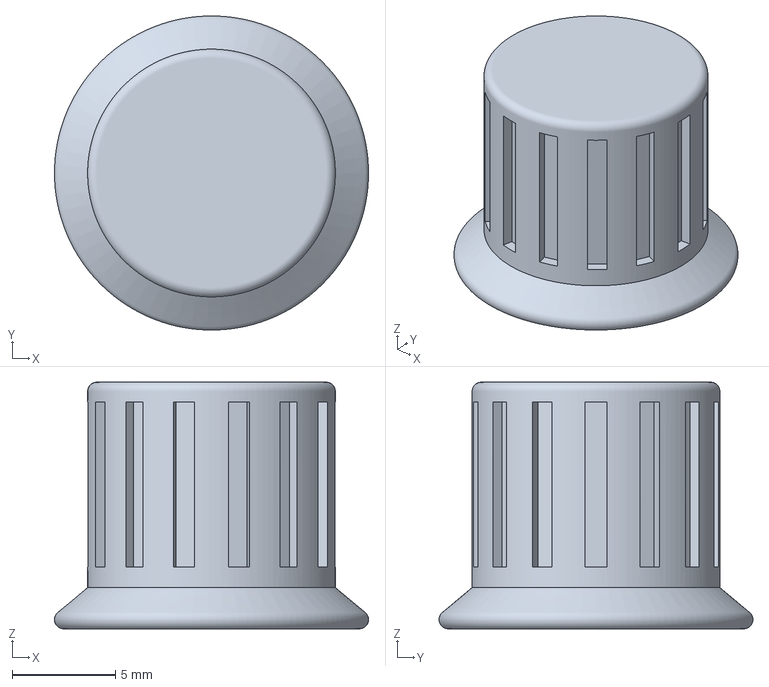
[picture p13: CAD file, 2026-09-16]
hardware/enclosure/3mf-multicolor/encoder_cap_aux3_ribbed_dots_multicolor_flush.3mf
15.2 x 15.2 x 11.9 mm

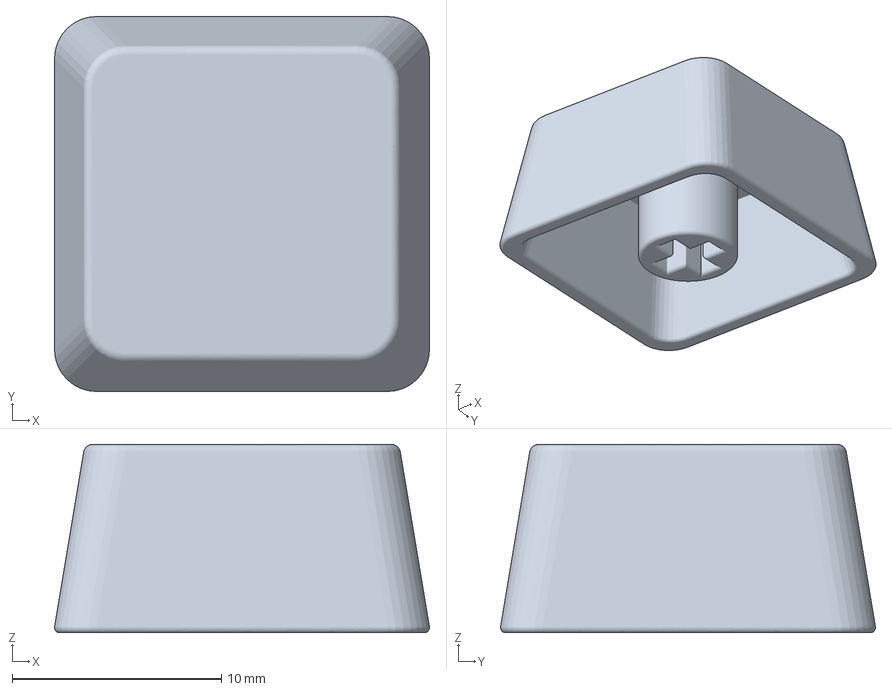
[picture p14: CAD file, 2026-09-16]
hardware/enclosure/3mf-multicolor/mx_keycap_fn_layer_multicolor_flush.3mf
17.9 x 17.9 x 9.00 mm

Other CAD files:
hardware/enclosure/3mf-single-material/encoder_cap_main_knurled_dots.3mf
hardware/enclosure/step/case_top_two_level_cadquery_orange-pi-zero-2w.step
release-artifacts/enclosure/stl/case_top_two_level_cadquery_orange_pi.stl
hardware/enclosure/3mf-multicolor/case_top_two_level_orange-pi-zero-2w_multicolor.3mf
hardware/enclosure/step/case_top_two_level_cadquery_raspberry-pi-zero-2w.step
release-artifacts/enclosure/stl/case_top_two_level_cadquery.stl
hardware/enclosure/step/mx_keycap_back.step
hardware/enclosure/3mf-single-material/case_top_two_level_cadquery_raspberry-pi-zero-2w.3mf
hardware/enclosure/step/mx_keycap_fn_layer.step
hardware/enclosure/3mf-multicolor/case_bottom_plate_cadquery.3mf
hardware/enclosure/3mf-multicolor/encoder_cap_aux1_ribbed_dot_multicolor_flush.3mf
hardware/enclosure/3mf-multicolor/friction_insert_expanding_plug_flat_sides.3mf
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

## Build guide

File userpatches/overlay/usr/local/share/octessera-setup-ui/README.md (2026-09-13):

# Octessera setup portal

Static UI for the one-page branded dark Wi-Fi setup portal.

## Page fields

- Country code
- Scanned or manual SSID
- Wi-Fi password or open network
- Local device password and confirmation; it is required even when SSH is disabled
- SSH key, SSH password, or none
- Optional hostname
- Apply

## Backend calls

- `GET /networks` and `POST /connect` are served by the pinned patched
  wifi-connect. It owns the setup AP, DHCP, HTTP portal, and network switch.
- `POST http://192.168.42.1:8080/country` applies the two-letter country code to
  the running radio.
- `POST http://192.168.42.1:8080/stage` validates the country, local device
  password, SSH, and hostname fields and passes them to the root coordinator in
  memory.

## `/stage` request body

Send JSON to `http://192.168.42.1:8080/stage` with these exact fields:

```json
{
  "sshMode": "none",
  "sshPublicKey": "",
  "accountPassword": "Example-only-123!",
  "accountPasswordConfirm": "Example-only-123!",
  "hostname": "",
  "wifiCountry": "US"
}
```

The example password is fictional; do not reuse it.

`sshMode` must be one of `none`, `key`, or `password`.

The local device password is set for the board account even when `sshMode` is
`none`. Key mode installs the public key and keeps SSH password login disabled.
Password mode enables SSH password login using the same local device password.
None mode keeps SSH disabled while leaving the local console and attended sudo
password available.

## `/country` request body

Send JSON to `http://192.168.42.1:8080/country` with exactly one field:

```json
{"wifiCountry":"US"}
```

The endpoint accepts two ASCII letters and applies the country to the running
radio. It does not write credentials.

## `/connect` request body

Send form-urlencoded fields:

- `ssid`
- `identity`
- `passphrase`

`identity` may be blank.

## Behavior

- Apply `/country` before the initial network scan and before every refresh.
- Call `/stage` before `/connect`.
- Show the provisional `Applying setup` screen after `/stage` succeeds and
  before `/connect`. A response only means that wifi-connect accepted the
  request. The AP may disconnect while settings apply; watch the OLED for the
  result and find the address in `System > Sys. Info` after success.
- The browser makes no completion or retry call. Keep form state in memory only.
- Do not rely on external services or storage.

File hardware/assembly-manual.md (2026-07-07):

# Cell Symphony Hardware Assembly Manual

This guide builds the standalone Cell Symphony instrument: PCB, soldered controls, plug-in modules, NeoTrellis grid, Raspberry Pi image, and enclosure.

The hardware is still being fit-tested. Check the current enclosure files before ordering printed parts.

## Source files

- Gerbers for PCB fabrication: [`KiCAD/gerber/gerber.zip`](KiCAD/gerber/gerber.zip)
- Schematic: [`KiCAD/cellSymphony.kicad_sch`](KiCAD/cellSymphony.kicad_sch)
- PCB layout: [`KiCAD/cellSymphony.kicad_pcb`](KiCAD/cellSymphony.kicad_pcb)
- Wiring reference: [`pinout-and-connections.md`](pinout-and-connections.md)
- Pi setup and bring-up: [`pi-bring-up.md`](pi-bring-up.md)
- Enclosure reference: [`enclosure/README.md`](enclosure/README.md)

## BOM

### PCB and electronics

| Qty | Item | Exact/current part | Notes |
|---:|---|---|---|
| 1 | Custom PCB | Fabricate from [`KiCAD/gerber/gerber.zip`](KiCAD/gerber/gerber.zip) | Order as a two-layer PCB unless the Gerber notes say otherwise. |
| 4 | NeoTrellis 4x4 driver PCB | [Mouser `485-3954`](https://www.mouser.com/ProductDetail/Adafruit/3954), Adafruit `3954` | Forms the 8x8 grid. |
| 4 | Silicone 4x4 keypad | [Mouser `485-1611`](https://www.mouser.com/ProductDetail/Adafruit/1611), Adafruit `1611` | One per NeoTrellis board. |
| 1 | NeoKey 1x4 QT | [Mouser `485-4980`](https://www.mouser.com/ProductDetail/Adafruit/4980), Adafruit `4980` | Holds the four Cherry MX keys. |
| 1 | Raspberry Pi Zero 2 W with header | [Mouser `358-SC0721`](https://www.mouser.com/ProductDetail/Raspberry-Pi/SC0721), Raspberry Pi `SC0721` | Use the headered version. |
| 1 | SSD1351 OLED breakout with microSD holder | [Mouser `485-1431`](https://www.mouser.com/ProductDetail/Adafruit/1431), Adafruit `1431` | SPI display. |
| 1 | PCM5102 I2S DAC | [Mouser `485-6250`](https://www.mouser.com/ProductDetail/Adafruit/6250), Adafruit `6250` | Line/headphone output path. |
| 1 | USB-C power breakout | [Mouser `485-4090`](https://www.mouser.com/ProductDetail/Adafruit/4090), Adafruit `4090` | Power the device here, not through the Pi. |
| 5 | Horizontal rotary encoder with switch | [Mouser `652-PEC12R-4225F-S24`](https://www.mouser.com/ProductDetail/Bourns/PEC12R-4225F-S0024), Bourns `PEC12R-4225F-S0024` | The PCB uses four encoders; buy one spare. |
| 4 | Black D-shaft encoder knob | [Mouser `450-BA600`](https://www.mouser.com/ProductDetail/Eagle-Plastic-Devices/450-BA600) | Main/aux encoder caps. |
| 1 | Red 20mm encoder knob | [Mouser `485-5530`](https://www.mouser.com/ProductDetail/Adafruit/5530), Adafruit `5530` | Optional accent knob. |
| 2 | STEMMA QT / Qwiic JST-SH cable, 200mm | [Mouser `485-4401`](https://www.mouser.com/ProductDetail/Adafruit/4401), Adafruit `4401` | For module bring-up or alternate I2C wiring. |
| 1 | Polarized capacitor | [`470uF`, 16V, radial, about 8x12mm](https://de.aliexpress.com/item/1005010415990713.html) | PCB footprint: `CP_Radial_D8.0mm_P3.50mm`. Any equivalent 470uF polarized radial capacitor with 3.5mm lead pitch and >5V rating is fine. |
| 1 | 1x5 right-angle female socket/header, 2.54mm pitch | [2.54mm right-angle female header strip](https://de.aliexpress.com/item/32896617287.html) | Cut to 5 pins for the NeoTrellis connector on the PCB. |
| 1 | 5-wire female-to-male Dupont cable, about 5cm | [Female-to-male Dupont jumper cable set](https://de.aliexpress.com/item/1005003683781229.html) | Use five adjacent leads, about 5cm long, to connect the NeoTrellis array to the PCB. |
| several | Low-profile female header/socket strips, 2.54mm pitch | [Round-pin 2.54mm header/socket strip](https://de.aliexpress.com/item/1005006673257121.html) or [round-pin 2.54mm header/socket strip](https://de.aliexpress.com/item/4001122376295.html) | Cut to length for Pi, OLED, DAC, power breakout, and other plug-in modules. Confirm the socket height before ordering. |
| 4 | Cherry MX-compatible key switches | [Mouser `540-MX1A-G1NW`](https://www.mouser.com/ProductDetail/CHERRY/MX1A-G1NW), Cherry MX Black, or any MX-compatible switch | Install into the NeoKey after bring-up. |
| 4 | MX keycaps | [Mouser `540-G99-1779ZUB`](https://www.mouser.com/ProductDetail/CHERRY/G99-1779ZUB), or any MX-stem keycap | Match your preferred profile. |
| 1 | MicroSD card for Raspberry Pi | 16GB or larger recommended | Flash the release image. |
| 1 | USB-C power supply | 5V supply with enough current for Pi + LEDs | Connect only to the USB-C breakout. |
| 1 | Audio cable/headphones/speaker | 3.5mm audio | Used for test and operation. |

### 3D printed and mechanical parts

| Qty | Item | File/spec | Notes |
|---:|---|---|---|
| 1 | Enclosure top | `enclosure/case_top_two_level_cadquery.stl` | Generated from CadQuery. STEP file is also checked in. |
| 1 | Enclosure bottom | `enclosure/case_bottom_plate_cadquery.stl` | Current bottom plate with guide walls and screw holes. |
| 18 | Regular module standoff | `enclosure/standoff_pillar_9mm.stl` | For Pi, OLED, DAC, power breakout, and NeoKey support locations. |
| 8 | NeoTrellis standoff | `enclosure/standoff_pillar_10mm.stl` | Two for each NeoTrellis board. |
| 26 | Standoff top pin | `enclosure/standoff_top_pin_thin_base.stl` | One top pin for every standoff. This is the default top pin with a `0.5mm` base disc. |
| 8 | Heat-set insert | [M3 heat-set insert](https://de.aliexpress.com/item/1005012199553197.html), about `4.0-4.2mm` outer diameter and `5-6mm` long | Insert from the underside of the top. The linked kit includes multiple sizes; use the M3 inserts that fit the `4.2mm` pilot holes. |
| 8 | Screws | M3 x 8mm socket-head cap screw, DIN 912 / ISO 4762 style | Installed from the bottom. Use a head diameter no larger than `6.4mm` so it fits the counterbores. |
| 8 | Rubber feet or screw-hole plugs | Small adhesive feet | Optional, covers bottom screw holes and prevents sliding. |

Standoff STL attribution: the standoff models are based on [Stackable PCB Standoff by theduckom](https://www.printables.com/model/163087-stackable-pcb-standoff), licensed under [Creative Commons Attribution 4.0 International](https://creativecommons.org/licenses/by/4.0/).

### Tools and consumables

- Soldering iron and solder.
- Flush cutters.
- Small screwdriver and a longish bit for bottom screws.
- Heat-set insert tool or soldering iron tip for M3 inserts.
- Multimeter.
- Raspberry Pi Imager.
- Optional: continuity tester, tweezers, helping hands, and magnifier.

## Before soldering

1. Inspect the PCB for visible manufacturing defects.
2. Confirm the PCB matches the current Gerber zip.
3. Sort sockets, headers, and modules before soldering.
4. Keep every module oriented the same way it will sit in the enclosure.
5. Mark the correct side of every module before soldering headers.

Headers on the wrong side are difficult to fix. Check the silkscreen, enclosure orientation, and module footprint before soldering.

## Solder the main PCB

Solder low-profile sockets and headers first. They define module height and alignment.

1. Solder the low-profile sockets for the Raspberry Pi, OLED, DAC, USB-C power breakout, and any other socketed modules.
2. Solder the 1x5 right-angle female socket for the NeoTrellis connector.
3. Solder `C1`, the `470uF` polarized capacitor. Match polarity to the PCB markings.
4. Solder the four rotary encoders into `SW1` through `SW4`.

Do not install plug-in modules yet.

## Build the NeoTrellis array

The four NeoTrellis boards form one 8x8 grid.

1. Arrange the boards as viewed from the play surface:
   - upper left
   - upper right
   - lower left
   - lower right
2. Solder the boards together with pin links between adjacent edges.
3. Add the external connector pins to the left side of the upper-left NeoTrellis board.
4. Set the NeoTrellis addresses:

   | Position | Jumpers | Address |
   |---|---|---:|
   | upper left | none | `0x2E` |
   | upper right | A0 | `0x2F` |
   | lower left | A1 | `0x30` |
   | lower right | A0 + A1 | `0x31` |

5. Set the NeoKey address by soldering A0, A1, A2, and A3. Leave A4 open. The expected address is `0x3F`.

## Flash the Raspberry Pi image

1. Download the latest release image from the project releases. It is named like:

   ```text
   CellSymphony-<version>-pi-zero-2w.img.zip
   ```

2. Flash it to the Pi microSD card with Raspberry Pi Imager.
3. Configure WiFi, SSH, hostname, and locale in Raspberry Pi Imager if you need network access.
4. Insert the microSD card into the Raspberry Pi.

For manual Pi setup and diagnostics, see [`pi-bring-up.md`](pi-bring-up.md).

## First electrical assembly

1. Insert the Raspberry Pi, OLED, DAC, USB-C power breakout, and NeoKey into their sockets.
2. Connect the NeoTrellis array to the PCB with the short 5-wire female-to-male Dupont cable.
3. Install the Cherry MX switches into the NeoKey.
4. Add the keycaps.
5. Connect audio output to headphones, speakers, or a mixer.
6. Connect power to the USB-C breakout.

Do not power the device from the Raspberry Pi power connector.

Wait for the Pi to boot. First boot can take a while. Then check:

- NeoKey LEDs/input.
- NeoTrellis LEDs/input.
- OLED output.
- Encoder turns and presses.
- Audio output.

Then run the hardware diagnostics from the System menu before assembling the enclosure. Complete the guided checks for display, grid, keys, encoders, and audio while the boards are still accessible.

If the hardware does not come up, stop and use the bring-up checks in [`pi-bring-up.md`](pi-bring-up.md).

## Enclosure assembly

Only assemble the enclosure after the electrical test and System-menu diagnostics pass.

1. Place the bottom enclosure on the bench.
2. Put the PCB and NeoTrellis array onto the bottom.
3. Add standoffs between the bottom supports and the modules:
   - For each plug-in module, remove the module, add the standoff, then reinstall the module.
   - Repeat for the NeoTrellis array.
4. Press one top pin into every standoff, including PCB/module standoffs and NeoTrellis standoffs.
5. Insert the M3 heat-set inserts into the underside of the enclosure top with a soldering iron or insert tool.
6. Place the enclosure top over the assembly. The guide walls and standoff pins should locate the parts without forcing them.
7. Turn the device over carefully.
8. Install the bottom screws into the recessed holes and tighten them into the heat inserts.
9. Add rubber feet or screw-hole covers if desired.

Tighten screws gently. If the top does not sit flat, stop and find the interference instead of forcing the case closed.

## Final checks

1. Connect power through the USB-C breakout.
2. Wait for boot.
3. Confirm input from all encoders, NeoKey switches, and NeoTrellis buttons.
4. Confirm the OLED is readable.
5. Confirm audio output from the DAC.
6. Confirm the Pi microSD, OLED microSD, audio, USB-C power, Pi mini-HDMI, and Pi USB data openings are accessible.

## Things to verify before ordering in quantity

- Confirm the selected M3 heat-set inserts fit the `4.2mm` pilot holes and that M3 x 8mm socket-head screws reach the inserts cleanly after printing.
- Final fit of the printed bottom, top, standoffs, and top pins.
- Whether the generic sockets you buy match the intended low profile.
- Whether the 5cm Dupont cable has enough slack after the NeoTrellis array is installed.
- Port alignment after printing with your printer and slicer.

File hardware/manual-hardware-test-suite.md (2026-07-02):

# Manual Hardware Test Suite

Use this checklist for hands-on hardware bring-up when no OLED is installed. The operator watches the hardware while the test runner controls the Pi over SSH.

## Starting State

- Pi is reachable as `pi@192.168.0.211`.
- `cellsymphony.service` is disabled and inactive unless a test step explicitly starts it.
- OLED is removed.
- NeoTrellis, NeoKey, DAC/audio, encoders, and power are connected.

Before each session:

```powershell
./tools/pi-preflight.ps1 -Target pi@192.168.0.211
```

Then confirm the app is stopped:

```bash
sudo systemctl disable cellsymphony.service
sudo systemctl stop cellsymphony.service
```

## 1. Bus And Power Baseline

Run with the app stopped:

```bash
pinctrl get 2
pinctrl get 3
sudo i2cdetect -y -r 1 0x2e 0x3f
vcgencmd get_throttled
aplay -l
```

Expected:

- `GPIO2` / SDA and `GPIO3` / SCL are high when idle.
- NeoTrellis appears at `0x2E`, `0x2F`, `0x30`, `0x31`.
- NeoKey appears at `0x3F`.
- `throttled=0x0`.
- ALSA lists `snd_rpi_hifiberry_dac` / `pcm5102a`.

Stop if the clean scan does not match. Fix wiring before running active tests.

## 2. NeoTrellis LED Sweep

Goal: prove all 64 grid LEDs can be addressed and confirm physical coordinate orientation.

Test behavior to run from code for up to 90 seconds, or until the operator presses Enter:

1. Clear all grid LEDs.
2. Light each physical 4x4 board address as a different solid color:
   - `0x2E`: red
   - `0x2F`: green
   - `0x30`: blue
   - `0x31`: white
3. Sweep one red pixel left-to-right, bottom-to-top in runtime grid coordinates.
4. Light the four logical corners:
   - `(0,0)` red
   - `(7,0)` green
   - `(0,7)` blue
   - `(7,7)` white

Operator records:

- Whether all LEDs light.
- Whether colors match.
- Whether `(0,0)` appears at the lower-left of the play surface. If it appears at the upper-left, the HAL Y mapping is inverted.
- Any rotated, mirrored, or board-swapped regions.

## 3. NeoTrellis Button Events

Goal: prove all 64 grid buttons generate press and release events.

Test behavior to run from code for up to 90 seconds, or until the operator presses Enter:

1. Clear grid LEDs.
2. On every grid press, log `grid_press x y` and light that cell yellow.
3. On release, log `grid_release x y` and dim that cell blue.
4. Keep a count of seen cells.
5. Print missing coordinates after each pass.

Manual pass:

- Press each cell once, left-to-right, bottom-to-top.
- Repeat the four corners.
- Hold two adjacent cells briefly to check multi-key handling.

Expected:

- Every press and release logs exactly once.
- Coordinates match lower-left runtime semantics.
- No stuck cells remain lit as pressed after release.

## 4. NeoKey LED And Button Test

Goal: prove four keys and four LEDs work without OLED feedback.

Test behavior to run from code:

1. Light NeoKey LEDs one at a time:
   - key 0 red
   - key 1 green
   - key 2 blue
   - key 3 white
2. Then set all keys dim amber.
3. Confirm hands-off readiness, then run a no-touch idle noise check across NeoTrellis, NeoKey, and encoders. Confirmed input during this phase is a failure. Raw NeoKey one-sample glitches whose immediate reread burst is clean are warnings within tolerance.
4. On press, log and set pressed key bright white.
5. On release, log and return it to dim amber.

Expected logical mapping:

| NeoKey index | Runtime input |
|---:|---|
| 0 | Back / `button_a` |
| 1 | Space / `button_s` |
| 2 | Shift / `button_shift` |
| 3 | Fn / `button_fn` |

Operator records:

- Physical left-to-right order.
- Any LED color-order mismatch.
- Any missed press/release.
- Any idle ghost press, encoder event, grid event, or raw noise warning on any input.
- NeoKey raw one-sample glitches whose immediate reread burst is clean are reported as warnings within tolerance, because runtime input confirmation rejects them.

## 5. Encoder Turn And Click Test

Goal: prove all encoder A/B pins and push switches work.

Test behavior to run from code:

1. Log every encoder turn as `encoder_turn id delta`.
2. Log every encoder click as `encoder_press id`.
3. Optionally flash NeoKey key 0 on main encoder input and NeoKey keys 1-3 for aux encoders.

Expected IDs:

| Physical control | Runtime ID |
|---|---|
| Main encoder | `main` |
| Aux 1 | `aux1` |
| Aux 2 | `aux2` |
| Aux 3 | `aux3` |

Manual pass per encoder:

1. Turn one detent clockwise.
2. Turn one detent counter-clockwise.
3. Turn quickly for several detents.
4. Press and release the push switch.

Record:

- Direction polarity.
- Bounce or duplicate clicks.
- Missing detents.
- Wrong encoder ID.

## 6. Audio Output Test

The test harness asks the operator to connect speakers or headphones and set a safe volume before playing the direct ALSA tone:

```bash
timeout 15 speaker-test -D hw:0,0 -c 2 -t sine -f 440 -l 1
```

Expected:

- Audible 440 Hz tone.
- No underrun or device-open error.

Then run a runtime audio smoke test:

1. Start the app only after I2C devices are healthy.
2. Trigger a simple internal synth note from code or a known grid action.
3. Confirm output through the DAC path, not HDMI or headphone fallback.

## 7. Integrated Runtime Smoke Test

Use after individual hardware tests pass.

1. Start `cellsymphony.service` manually.
2. Watch logs:

   ```bash
   journalctl -u cellsymphony.service -f
   ```

3. Confirm no `critical hardware init failed` messages.
4. Press grid cells and NeoKeys.
5. Turn and click encoders.
6. Confirm audio still works.
7. Stop the service and verify the I2C bus releases:

   ```bash
   sudo systemctl stop cellsymphony.service
   pinctrl get 2
   pinctrl get 3
   sudo i2cdetect -y -r 1 0x2e 0x3f
   ```

Expected:

- Service stays active.
- No restart loop.
- I2C devices remain detectable after service stop.
- Runtime input/output behavior matches hardware semantics.

## Test Harness Command

Run the no-OLED interactive hardware-test mode directly over SSH:

```bash
sudo systemctl disable cellsymphony.service
sudo systemctl stop cellsymphony.service
/usr/local/bin/cellsymphony-pi --hardware-test
```

The mode initializes NeoTrellis, NeoKey, DAC, and encoders without requiring an OLED. It then runs the LED checks, logs grid/key/encoder events to stdout, and launches the ALSA test tone.
It prints a final `SUMMARY` with warning and failure counts.

For unattended launch, set `CELLSYMPHONY_PI_HARDWARE_TEST=1` instead of passing `--hardware-test`.

To run only the no-touch input noise check:

```bash
sudo systemctl disable cellsymphony.service
sudo systemctl stop cellsymphony.service
/usr/local/bin/cellsymphony-pi --hardware-noise-test
```

For unattended no-touch-only launch, set `CELLSYMPHONY_PI_HARDWARE_NOISE_TEST=1`.
The noise-only mode also prints a final `SUMMARY`. Warnings indicate raw noise that is below the runtime confirmation threshold; failures indicate confirmed input, read failures, or encoder/grid idle events.

Use skip flags to isolate one hardware family while another is disconnected or suspect:

```bash
/usr/local/bin/cellsymphony-pi --hardware-noise-test --skip-trellis
/usr/local/bin/cellsymphony-pi --hardware-noise-test --skip-neokey
/usr/local/bin/cellsymphony-pi --hardware-noise-test --skip-encoders
```

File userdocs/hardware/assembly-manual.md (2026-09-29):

# octessera hardware assembly manual

Follow these stages in order. Keep the assembly open through [flash and first
boot](flash-and-first-boot.md); close the enclosure only after the first-boot
checks pass.

## 1. Safety and board choice

Choose one compute board before ordering parts:

- Raspberry Pi Zero 2 W
- Orange Pi Zero 2W

Choose the board, then use its matching image in [flash and first boot](flash-and-first-boot.md)
and its matching enclosure top. The normal user journey is otherwise shared.

Read [safety and power](safety-and-power.md) before handling power, a host
cable, or the enclosure. Power the finished instrument through the enclosure
USB-C power breakout. Do not power the Raspberry Pi through its micro-USB power
connector.

## 2. Parts and tools

### PCB and electronics

| Qty | Item | Part | Notes |
|---:|---|---|---|
| 1 | Custom PCB | Fabricate from [`../../hardware/pcb/gerber/gerber.zip`](../../hardware/pcb/gerber/gerber.zip) | Order as a two-layer PCB unless the Gerber notes say otherwise. |
| 4 | NeoTrellis 4x4 driver PCB | [Adafruit `3954`](https://www.adafruit.com/product/3954), Mouser `485-3954` | Forms the 8x8 grid. |
| 4 | Silicone 4x4 keypad | [Adafruit `1611`](https://www.adafruit.com/product/1611), Mouser `485-1611` | One per NeoTrellis board. |
| 1 | NeoKey 1x4 QT | [Adafruit `4980`](https://www.adafruit.com/product/4980), Mouser `485-4980` | Holds the four Cherry MX keys. |
| 1 | Compute board | [Raspberry Pi Zero 2 W](https://www.raspberrypi.com/products/raspberry-pi-zero-2-w/) or Orange Pi Zero 2W | Choose one board. |
| 1 | Wi-Fi antenna (Orange Pi only, optional) | Orange Pi Zero 2W-compatible antenna | Connect it before final assembly. Secure it with non-conductive tape on a free PCB area where it cannot cover pads, touch exposed contacts, be pinched, or strain the connector. |
| 1 | SSD1351 OLED breakout with microSD holder | [Adafruit `1431`](https://www.adafruit.com/product/1431), Mouser `485-1431` | SPI display. |
| 1 | PCM5102 I2S DAC | [Adafruit `6250`](https://www.adafruit.com/product/6250), Mouser `485-6250` | Line/headphone output path. |
| 1 | USB-C power breakout | [Adafruit `4090`](https://www.adafruit.com/product/4090), Mouser `485-4090` | Power the device here, not through the compute board. |
| 4 | Horizontal rotary encoder with switch | [RS `781-6811`](https://at.rs-online.com/web/p/mechanische-drehgeber/7816811), Bourns `PEC12R-4225F-S0024` | The PCB uses four encoders. |
| 1 | Polarized capacitor | [`470uF`, 16V, radial, about 8x12mm](https://de.aliexpress.com/item/1005010415990713.html) | PCB footprint: `CP_Radial_D8.0mm_P3.50mm`. An equivalent 470uF polarized radial capacitor with 3.5mm lead pitch and >5V rating is fine. |
| 1 | 5V TVS diode | `SA5.0A`, axial DO-15, `Diode_THT:D_DO-15_P10.16mm_Horizontal` | Required PCB part `D1`. The banded cathode goes to `K/+5V`; the unbanded anode goes to `A/GND`. |
| 1 | 1x5 right-angle male header, 2.54mm pitch | Any standard breakaway right-angle male pin header | Cut to 5 pins for the NeoTrellis connector. |
| 1 | 5-wire female-to-female Dupont cable, about 10cm | Any 2.54mm female-to-female jumper cable set | Use five adjacent leads for the NeoTrellis array. |
| 25 pins | Straight male pin header, 2.54mm pitch | Any standard breakaway male pin header strip | Use 20 pins to link the four NeoTrellis boards and 5 pins for the external connection point on the upper-left board. |
| several | Low-profile female header/socket strips, 2.54mm pitch | [Round-pin 2.54mm header/socket strip](https://de.aliexpress.com/item/1005006673257121.html) or [round-pin 2.54mm header/socket strip](https://de.aliexpress.com/item/4001122376295.html) | Cut to length for the selected compute board, OLED, DAC, power breakout, and other plug-in modules. Confirm socket height before ordering. |
| 4 | Cherry MX-compatible key switches | [Cherry MX Black switches](https://www.amazon.de/-/en/CHERRY-Mechanical-Keyboard-Switches-without/dp/B0CBS4HJJR?th=1), or any MX-compatible switch | Fit through the enclosure top into the NeoKey after closing the case. |
| 1 | MicroSD card for the selected board | 16GB or larger recommended | Flash the matching board image. Raspberry and Orange images are separate. |
| 1 | USB-C power supply | Dedicated regulated 5V/4A supply intended for Raspberry Pi 4-class systems | The documented GeeekPi 20W 5V/4A example is acceptable. Connect only to the USB-C breakout. |
| 1 | USB data cable and adapter (optional) | Suitable cable and adapter for the selected USB operation | See [USB roles](usb-roles.md) before connecting it. |
| 1 | Audio cable/headphones/speaker | 3.5mm audio | Use for audio output. |

### 3D-printed and mechanical parts

The enclosure uses a printed dowel, standoff, and top-pin system. This assembly
uses heat-set inserts and screws to join the two shells. The fits are snug, so
calibrate the printer or test partial prints before printing the full set.

The STEP, STL, single-material 3MF, and multicolor 3MF folders each contain a
complete 18-part set. The multicolor set combines 12 authored two-material
designs with six one-material support pieces.

| Qty | Item | File/spec | Notes |
|---:|---|---|---|
| 1 | Enclosure top | Board-specific `../../hardware/enclosure/stl/case_top_two_level_cadquery_<board>.stl`, matching single-material `../../hardware/enclosure/3mf-single-material/case_top_two_level_cadquery_<board>.3mf`, or branded multicolor `../../hardware/enclosure/3mf-multicolor/case_top_two_level_<board>_multicolor.3mf` | The generated tops are named for Raspberry Pi Zero 2 W and Orange Pi Zero 2W. Fit the exact board before ordering a final print. |
| 1 | Enclosure bottom | `../../hardware/enclosure/stl/case_bottom_plate_cadquery.stl` | Bottom plate with guide walls and screw holes. |
| 1 | Main encoder knob | Print `../../hardware/enclosure/stl/encoder_cap_main_knurled_dots.stl`, use `../../hardware/enclosure/3mf-single-material/encoder_cap_main_knurled_dots.3mf`, or use `../../hardware/enclosure/3mf-multicolor/encoder_cap_main_knurled_dots_multicolor_flush.3mf` | Main encoder cap. The multicolor version uses the dot-ring marking. |
| 3 | Aux encoder knobs | Print `../../hardware/enclosure/stl/encoder_cap_aux*_ribbed_dot*.stl`, use matching `../../hardware/enclosure/3mf-single-material/encoder_cap_aux*.3mf`, or use matching `../../hardware/enclosure/3mf-multicolor/encoder_cap_aux*_multicolor_flush.3mf` | Aux 1/2/3 caps. Multicolor versions use one, two, and three dots. |
| 4 | MX keycaps | Print `../../hardware/enclosure/stl/mx_keycap_*.stl`, use matching `../../hardware/enclosure/3mf-single-material/mx_keycap_*.3mf`, use matching `../../hardware/enclosure/3mf-multicolor/mx_keycap_*_multicolor_flush.3mf`, or use any MX-stem keycap | Four NeoKey caps: back, play, shift, and function/layer. Transparent filament for the cap body lets the color LEDs shine through. |
| 8 | 9.5mm standoff pillar | Print `../../hardware/enclosure/stl/standoff_pillar_9_5mm.stl` and matching `../../hardware/enclosure/3mf-single-material/standoff_pillar_9_5mm.3mf`, or use compatible purchased stackable PCB standoffs | Use for the OLED and audio/DAC board support locations. |
| 10 | 10mm standoff pillar | Print `../../hardware/enclosure/stl/standoff_pillar_10mm.stl` and matching `../../hardware/enclosure/3mf-single-material/standoff_pillar_10mm.3mf`, or use compatible purchased stackable PCB standoffs | Use for the selected compute board, power breakout, and NeoKey support locations. NeoTrellis array pins go straight into the bottom's integrated pillars. |
| 26 | Standoff top pin | Print `../../hardware/enclosure/stl/standoff_top_pin_thin_base.stl` and matching `../../hardware/enclosure/3mf-single-material/standoff_top_pin_thin_base.3mf`, or use compatible purchased stackable PCB standoff pins | 4 compute-board + 4 audio/DAC + 4 OLED/screen + 4 NeoKey + 2 power + 8 NeoTrellis array pins = 26 total. |
| 8 | Heat-set insert | M3x6x5 heat-set insert, such as the M3 size in this [heat-set insert kit](https://de.aliexpress.com/item/1005012199553197.html) | Install in the empty top from its underside; the smooth lead-in side locates in the `4.6mm` pilot hole. |
| 8 | Screws | M3x8 socket-head cap screw, DIN 912 / ISO 4762 style | Install from the bottom; head diameter must be no larger than `6.4mm`. |
| 8 | Rubber feet or screw-hole plugs | Small adhesive feet | Optional. Covers bottom screw holes and prevents sliding. |

### Tools and consumables

- Soldering iron and solder.
- Flush cutters.
- Multimeter.
- BalenaEtcher or another suitable image flasher.
- Optional: small screwdriver, heat-set insert tool, pliers, continuity
  tester, tweezers, helping hands, and magnifier.

## 3. Soldering

### Main PCB

Before soldering, inspect the PCB, sort the sockets and modules, and mark the
correct side of every module. Keep each module oriented as it will sit in the
enclosure. Headers on the wrong side are difficult to fix.

1. Solder the four rotary encoders into `SW1` through `SW4`.
2. Solder the low-profile sockets for the selected compute board, OLED, DAC,
   USB-C power breakout, and other socketed modules.
3. Solder the 1x5 right-angle male header at `J1` for the NeoTrellis cable.
4. Solder `D1`, the `SA5.0A` TVS diode. Put the banded cathode in `K/+5V` and
   the unbanded anode in `A/GND`. Keep the body and leads clear of nearby pads
   and metal parts.
5. Solder `C1`, the `470uF` polarized capacitor, matching the PCB polarity
   markings. The legs may remain a little long so the capacitor can bend
   sideways; prevent the legs from touching pads or metal.

Aim the horizontal NeoTrellis header toward the cable path and check the PCB
connector indicator. Solder the mating pin headers onto the plug-in compute
board and breakouts before fitting them. Their pins must point into the main
PCB's sockets when the modules sit on their standoffs. Do not install the
modules yet.

### NeoTrellis and NeoKey

The four NeoTrellis boards form one 8x8 grid.

1. Arrange the boards as upper-left, upper-right, lower-left, and lower-right
   when viewed from the play surface.
2. Turn the whole arrangement around as one plane before soldering. The address
   table below uses positions seen from the bottom after that flip, so left and
   right are swapped relative to the play surface.
3. Solder 20 straight male header pins between adjacent boards.
4. Add 5 straight male header pins as the external connection point on the
   left side of the upper-left board.
5. Viewed from the bottom, set the addresses as follows:

   | Position | Jumpers | Address |
   |---|---|---:|
   | upper left | A0 | `0x2F` |
   | upper right | none | `0x2E` |
   | lower left | A0 + A1 | `0x31` |
   | lower right | A1 | `0x30` |

   On the play surface, the resulting order is upper-left none/`0x2E`,
   upper-right A0/`0x2F`, lower-left A1/`0x30`, and lower-right
   A0+A1/`0x31`.

   See the [NeoTrellis address jumper photo](images/assembly/neotrellis-address-jumpers.jpg).

6. Set the NeoKey address by soldering A0, A1, A2, and A3. Its address is
   `0x3F`. See the [NeoKey address jumper photo](images/assembly/neokey-address-jumpers.jpg).

The NeoKey and NeoTrellis connector are easy to plug in backwards. Before
powering the device, check that `INT` is on the south side.

## 4. Open assembly

1. Insert the selected compute board, OLED, DAC, USB-C power breakout, and
   NeoKey into their sockets for the open-air first-boot test.
2. Connect `J1` on the main PCB to the five-pin header on the upper-left
   NeoTrellis board with the five female-to-female Dupont leads. Match `INT`,
   `VIN`, `GND`, `SCL`, and `SDA` by their labels and the [J1 pin
   reference](../../hardware/docs/pinout-and-connections.md#other-connections);
   do not assume the cable's colors or physical pin order match at both ends.
   Check the NeoTrellis orientation before applying power.
3. If your build includes the optional board antenna, connect it now and secure
   it where it cannot touch contacts, cover pads, or be pinched.
4. Connect headphones, speakers, or a mixer to the audio output.
5. Keep the assembly open and continue with [flash and first boot](flash-and-first-boot.md).

## 5. Flash and setup

Complete [flash and first boot](flash-and-first-boot.md) before installing the
enclosure. Keep the boards accessible and check what does not need the silicone
keys or the NeoKey switches yet:

- All four encoders turn and click.
- The OLED is readable.
- The NeoTrellis cable is seated at both ends, with the five signals matched as
  in [open assembly](#4-open-assembly).

Do not close the enclosure if an open-air check fails. The full grid and synth
audio checks belong in the [final check](#7-final-check) once the silicone keys
and guided NeoKey switches are fitted. If you can test either safely while the
assembly is open, do; neither requires a risky bare-switch test. For the normal
open-air test, leave the NeoKey switches off:
the enclosure top guides their pins and holds them by friction. A bare switch
test without that guide is possible if you have spare switches or a spare
NeoKey and accept the risk of bent pins or a damaged breakout; we recommend
waiting until the top is in place.

## 6. Enclosure

Power off and disconnect the cables. Remove the selected compute board's boot
microSD card and the OLED microSD card; they can catch on the case and break.
Take the plug-in boards out of their sockets after the first-boot check.
Reinsert the cards after closing the case if their openings require it.

1. Place the bottom enclosure on the bench. Seat the main PCB over the smaller
   integrated pillars on the west half, inside its locating rails.
2. Place the joined NeoTrellis array on the taller integrated pillars on the
   east half. Route its five-wire cable through the break in the left rail and
   connect the upper-left array header to `J1` if you unplugged it after the
   open-air test. Match the five signals as in [open
   assembly](#4-open-assembly); keep the cable clear of posts and pin holes.
3. Fix the NeoTrellis array to the taller pillars with its eight top pins. Use
   gentle pressure. If a pin is loose, gently squeeze its ball with pliers or
   replace it rather than crushing it.
4. Put one silicone 4x4 key membrane on each NeoTrellis board. Seat all four
   flat to form the 8x8 playing surface.
5. Push the 18 loose standoffs down through the main PCB mounting holes and
   into the smaller west-side pillars. Use eight 9.5mm standoffs for the OLED
   and audio/DAC board, and ten 10mm standoffs for the selected compute board,
   USB-C power breakout, and NeoKey.
6. Set the plug-in boards on those standoffs. Guide their pre-soldered header
   pins into the matching main-PCB sockets; do not bend or force the pins.
7. Pass the remaining 18 top pins through the mounting holes of the plug-in
   boards and press them into the loose standoffs. Check that every board sits
   flat and its header is fully seated.
8. Heat-set the eight M3 inserts into the wall pillars of the **empty top**
   from its underside, then let the top cool. Lower the top onto the assembly
   from the west side first so the ports pass through their openings, then
   lower the east side. Do not force it.

   If you want to try the NeoKey switches before fastening the case, leave the
   top unscrewed but fully seated and use its openings to guide the switches
   straight into the breakout. Reinsert the flashed boot card only if its slot
   is accessible without moving the top. Check all four presses only if you can
   power the stable assembly without pinching a cable. Power off and unplug it;
   with the top and NeoKey supported, withdraw the switches straight through
   the same guide holes. Remove the card before turning the unscrewed case over.
   If the slot is not accessible, skip this test and use the final check instead.

9. Turn the device over carefully and fasten the bottom to the top with the
   eight M3 machine screws from underneath. Tighten gently; add the optional
   rubber feet or screw-hole covers afterward.
10. Press the four encoder caps onto their shafts. Finally, fit the four Cherry
    MX switches into the NeoKey through the top openings, then press the four
    keycaps onto the switches. The top friction-holds the switches and guides
    their pins.

Tighten screws gently. If the top does not sit flat, find the interference
instead of forcing the case closed.

## 7. Final check

1. Reinsert the selected board's boot microSD card and the OLED microSD card if
   you removed them for enclosure assembly.
2. Connect power through the enclosure USB-C breakout and wait for boot.
3. Confirm that the enclosure has not blocked any controls or openings. If
   enclosure work disturbed a connection, reopen it and repeat the acceptance
   gate before use.
4. Press each of the four NeoKey switches now that the top holds them in place.
   If one does not respond, power off and reopen the case to check its seating
   and connection rather than forcing the switch deeper.
5. Check all 64 NeoTrellis cells through the silicone keys, then start a synth
   and confirm that the DAC produces audio. If either fails, power off and
   reopen the case rather than pressing harder on the playing surface.
6. Confirm that the compute-board microSD, OLED microSD, audio, USB-C power,
   and video openings are accessible. See [enclosure](enclosure.md) for the
   matching board top.

If anything is unclear, stop and use [troubleshooting](../troubleshooting.md)
before continuing.

## Source and manufacturing references

- Gerbers: [`../../hardware/pcb/gerber/gerber.zip`](../../hardware/pcb/gerber/gerber.zip)
- Schematic: [`../../hardware/pcb/octessera.kicad_sch`](../../hardware/pcb/octessera.kicad_sch)
- PCB layout: [`../../hardware/pcb/octessera.kicad_pcb`](../../hardware/pcb/octessera.kicad_pcb)
- Pin and bus reference: [`../../hardware/docs/pinout-and-connections.md`](../../hardware/docs/pinout-and-connections.md)
- Enclosure: [`enclosure.md`](enclosure.md)
- Standoff attribution: [Stackable PCB Standoff by theduckom](https://www.printables.com/model/163087-stackable-pcb-standoff), licensed under [CC BY 4.0](https://creativecommons.org/licenses/by/4.0/).

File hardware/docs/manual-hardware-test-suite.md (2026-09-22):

# Manual Hardware Test Suite

This Raspberry-only checklist covers no-OLED bench bring-up. The operator watches the hardware while the test runner controls the Pi over SSH.

## Starting State

- Raspberry Pi is reachable as `pi@<PI_HOST>`.
- `octessera.service` is disabled and inactive unless a test step explicitly starts it.
- OLED is removed.
- NeoTrellis, NeoKey, DAC/audio, encoders, and power are connected.

Before each session:

```powershell
$PiTarget = "pi@<PI_HOST>"
./tools/pi/pi-preflight.ps1 -Target $PiTarget
```

Inspect the installed Raspberry power policy. An interactive dry-run with extra
arguments does not check service context:

```bash
sudo grep -qx 'NoNewPrivileges=no' /etc/systemd/system/octessera.service
sudo stat -c '%u:%g:%a' /etc/sudoers.d/octessera-shutdown
sudo grep -qx 'pi ALL=(root) NOPASSWD: /usr/bin/systemctl poweroff, /bin/systemctl poweroff, /usr/sbin/poweroff, /sbin/poweroff, /usr/bin/systemctl reboot, /bin/systemctl reboot, /usr/sbin/reboot, /sbin/reboot' /etc/sudoers.d/octessera-shutdown
sudo visudo -cf /etc/sudoers.d/octessera-shutdown
```

Expected:

- `/etc/sudoers.d/octessera-shutdown` is root-owned mode `0440` and parses cleanly.
- The runtime unit explicitly uses `NoNewPrivileges=no` for its fixed power commands.
- No broad `NOPASSWD: ALL` rule is required for octessera power controls.
- On a fully assembled Pi, enable the service and separately replay the exact
  physical `System > Reboot` and `System > Shutdown` actions. Check the
  effective service policy, `sudo -n -l`, restart counter, boot IDs, and
  previous-boot journals. Require clean power submission with no same-boot
  service restart; do not substitute shell dry-runs.

Then confirm the app is stopped:

```bash
sudo systemctl disable octessera.service
sudo systemctl stop octessera.service
```

## 1. Bus And Power Baseline

Run with the app stopped:

```bash
pinctrl get 2
pinctrl get 3
sudo i2cdetect -y -r 1 0x2e 0x3f
vcgencmd get_throttled
aplay -l
```

Expected:

- `GPIO2` / SDA and `GPIO3` / SCL are high when idle.
- NeoTrellis appears at `0x2E`, `0x2F`, `0x30`, `0x31`.
- NeoKey appears at `0x3F`.
- `throttled=0x0`.
- ALSA lists `snd_rpi_hifiberry_dac` / `pcm5102a`.

Stop if the clean scan does not match. Fix wiring before running active tests.

## 2. NeoTrellis LED Sweep

Goal: check all 64 grid LEDs and physical coordinate orientation.

Test behavior to run from code for up to 90 seconds, or until the operator presses Enter:

1. Clear all grid LEDs.
2. Light each physical 4x4 board address as a different solid color:
   - `0x2E`: magenta
   - `0x2F`: green
   - `0x30`: cyan
   - `0x31`: white
3. Sweep one yellow pixel left-to-right, bottom-to-top in runtime grid coordinates.
4. Light the four logical corners:
   - `(0,0)` magenta
   - `(7,0)` green
   - `(0,7)` cyan
   - `(7,7)` white

Check:

- Whether all LEDs light.
- Whether colors match.
- Whether `(0,0)` appears at the lower-left of the play surface. If it appears at the upper-left, the HAL Y mapping is inverted.
- Any rotated, mirrored, or board-swapped regions.

## 3. NeoTrellis Button Events

Goal: check that all 64 grid buttons generate press and release events.

Test behavior to run from code for up to 90 seconds, or until the operator presses Enter:

1. Clear grid LEDs.
2. On every grid press, log `grid_press x y` and light that cell yellow.
3. On release, log `grid_release x y` and dim that cell cyan.
4. Keep a count of seen cells.
5. Print missing coordinates after each pass.

Manual pass:

- Press each cell once, left-to-right, bottom-to-top.
- Repeat the four corners.
- Hold two adjacent cells briefly to check multi-key handling.

Expected:

- Every press and release logs exactly once.
- Coordinates match lower-left runtime semantics.
- No stuck cells remain lit as pressed after release.

## 4. NeoKey LED And Button Test

Goal: check four keys and four LEDs without OLED feedback.

Test behavior to run from code:

1. Light NeoKey LEDs one at a time:
   - key 0 magenta
   - key 1 green
   - key 2 cyan
   - key 3 white
2. Then set all keys dim gray.
3. Confirm hands-off readiness, then run a no-touch idle noise check across NeoTrellis, NeoKey, and encoders. Confirmed input during this phase is a failure. Raw NeoKey one-sample glitches whose immediate reread burst is clean are warnings within tolerance.
4. On press, log and set pressed key bright white.
5. On release, log and return it to dim gray.

Expected logical mapping:

| NeoKey index | Runtime input |
|---:|---|
| 0 | Back / `button_a` |
| 1 | Space / `button_s` |
| 2 | Shift / `button_shift` |
| 3 | Fn / `button_fn` |

Check:

- Physical left-to-right order.
- Any LED color-order mismatch.
- Any missed press/release.
- Any idle ghost press, encoder event, grid event, or raw noise warning on any input.
- NeoKey raw one-sample glitches whose immediate reread burst is clean are reported as warnings within tolerance, because runtime input confirmation rejects them.

## 5. Encoder Turn And Click Test

Goal: check all encoder A/B pins and push switches.

Test behavior to run from code:

1. Log every encoder turn as `encoder_turn id delta`.
2. Log every encoder click as `encoder_press id`.
3. Optionally flash NeoKey key 0 on main encoder input and NeoKey keys 1-3 for aux encoders.

Expected IDs:

| Physical control | Runtime ID |
|---|---|
| Main encoder | `main` |
| Aux 1 | `aux1` |
| Aux 2 | `aux2` |
| Aux 3 | `aux3` |

Manual pass per encoder:

1. Turn one detent clockwise.
2. Turn one detent counter-clockwise.
3. Turn quickly for several detents.
4. Press and release the push switch.

Check:

- Direction polarity.
- Bounce or duplicate clicks.
- Missing detents.
- Wrong encoder ID.

## 6. Audio Output Test

### Raspberry HDMI connector check: read-only

Use the fixed connector paths
`/sys/class/drm/card0-HDMI-A-1/{status,edid}`. Check those paths directly; do
not enumerate DRM connectors or substitute `card1`:

```bash
set -eu
connector=/sys/class/drm/card0-HDMI-A-1
test -f "$connector/status"
test -f "$connector/edid"
status=$(tr -d '\r\n' < "$connector/status")
edid_bytes=$(wc -c < "$connector/edid")
printf 'HDMI connector: %s\nstatus: %s\nEDID bytes: %s\n' "$connector" "$status" "$edid_bytes"
if [ "$status" = connected ] && [ "$edid_bytes" -gt 0 ]; then
    echo "connector and EDID present"
elif [ "$status" = disconnected ]; then
    echo "connector present without an active display"
elif [ "$status" = connected ] && [ "$edid_bytes" -eq 0 ]; then
    echo "connector present without EDID"
else
    echo "unexpected HDMI connector state" >&2
    exit 1
fi
```

The test harness asks the operator to connect speakers or headphones and set a safe volume before playing the direct ALSA tone:

```bash
timeout 15 speaker-test -D hw:0,0 -c 2 -t sine -f 440 -l 1
```

Expected:

- Audible 440 Hz tone.
- No underrun or device-open error.

Then run a runtime audio smoke test:

1. Start the app only after I2C devices are healthy.
2. Trigger a simple internal synth note from code or a known grid action.
3. Confirm output through the selected exact route; when Jack is selected, use
   the DAC path and do not count an implicit HDMI or headphone route.

## 7. Integrated Runtime Smoke Test

Use for an integrated runtime check after the individual hardware tests.

1. Start `octessera.service` manually.
2. Watch logs:

   ```bash
   journalctl -u octessera.service -f
   ```

3. Confirm no `critical hardware init failed` messages.
4. Press grid cells and NeoKeys.
5. Turn and click encoders.
6. Confirm audio still works.
7. Stop the service and verify the I2C bus releases:

   ```bash
   sudo systemctl stop octessera.service
   pinctrl get 2
   pinctrl get 3
   sudo i2cdetect -y -r 1 0x2e 0x3f
   ```

Expected:

- Service stays active.
- No restart loop.
- I2C devices remain detectable after service stop.
- Runtime input/output behavior matches hardware semantics.

## Interactive Hardware Test Command

This is the Raspberry-only interactive hardware command. It actuates LEDs, scans
physical inputs, and plays a test tone under operator control. For the passive
diagnostic command, run:

```bash
/usr/local/bin/octessera-pi --fat-diagnostic \
  --board-profile raspberry-pi-zero-2w
```

For the Orange exact-source application FAT procedure, keep
`octessera.service` running and follow [the Orange bring-up
command](orange-pi-armbian-bringup.md#exact-source-application-fat-not-image-fat).
It validates the application candidate only; use the separate image FAT and
construction checks for the installed image.

Run the no-OLED interactive hardware-test mode directly over SSH:

```bash
sudo systemctl disable octessera.service
sudo systemctl stop octessera.service
/usr/local/bin/octessera-pi --hardware-test
```

The mode initializes NeoTrellis, NeoKey, DAC, and encoders without requiring an
OLED. It runs the LED checks, logs grid/key/encoder events to stdout, launches
the ALSA test tone, and prints a final `SUMMARY`.

Do not combine `--hardware-test` or `--hardware-noise-test` with
`--fat-diagnostic --board-profile raspberry-pi-zero-2w`. The command exits
before hardware access when modes are combined.

For unattended launch, set `OCTESSERA_PI_HARDWARE_TEST=1` instead of passing `--hardware-test`.

To run only the no-touch input noise check:

```bash
sudo systemctl disable octessera.service
sudo systemctl stop octessera.service
/usr/local/bin/octessera-pi --hardware-noise-test
```

For unattended no-touch-only launch, set `OCTESSERA_PI_HARDWARE_NOISE_TEST=1`.
The noise-only mode also prints a final `SUMMARY`.

Use skip flags to isolate one hardware family while another is disconnected or suspect:

```bash
/usr/local/bin/octessera-pi --hardware-noise-test --skip-trellis
/usr/local/bin/octessera-pi --hardware-noise-test --skip-neokey
/usr/local/bin/octessera-pi --hardware-noise-test --skip-encoders
```

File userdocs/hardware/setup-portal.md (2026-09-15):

# Open or reopen the setup portal

For the initial setup, follow [flash and first boot](flash-and-first-boot.md).
Use this page when the instrument is already running and you want to change its
network, password, SSH mode, or hostname.

## Steps

1. On the instrument, open `System > Setup > Configure WiFi > Open Portal`.
2. On a phone or computer, join `Octessera Setup <suffix>`.
3. Browse to `http://192.168.42.1`.
4. Choose the country and Wi-Fi network, set the local device password, choose
   an SSH mode, and optionally enter a hostname.
5. Press **Apply setup**.

The deliberately opened nearby setup hotspot can be joined by anyone in range.
Open it while present, complete setup promptly, and do not leave setup mode
running in public.

The portal sets the local board password you entered. SSH mode can be key,
password, or off. Root login is not available.

## What you should see

- The browser may disconnect while settings apply. Leave the instrument powered
  and wait for the OLED result.
- A successful result gives the board a usable Wi-Fi address. Find it later at
  `System > Sys. Info`; no reboot is needed.
- If the OLED reports a failure or timeout, dismiss it and start a new attempt
  with **Open Portal**.

For power and cable precautions while setting up, see [safety and
power](safety-and-power.md). For USB data roles, see [USB roles](usb-roles.md).

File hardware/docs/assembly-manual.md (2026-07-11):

# octessera hardware assembly manual

This guide builds the standalone Octessera instrument: PCB, soldered controls, plug-in modules, NeoTrellis grid, Raspberry Pi image, and enclosure.

The hardware is still being fit-tested. Check the current enclosure files before ordering printed parts, and do the slow fit checks before you close the box. Tiny clearances are where instruments learn humility.

If you are new here, start with the friendlier map in [`../../userdocs/README.md`](../../userdocs/README.md), then come back with a soldering iron and snacks.

## Source files

- Gerbers for PCB fabrication: [`../../release-artifacts/pcb/gerber/gerber.zip`](../../release-artifacts/pcb/gerber/gerber.zip)
- Schematic: [`../pcb/octessera.kicad_sch`](../pcb/octessera.kicad_sch)
- PCB layout: [`../pcb/octessera.kicad_pcb`](../pcb/octessera.kicad_pcb)
- Wiring reference: [`pinout-and-connections.md`](pinout-and-connections.md)
- Pi setup and bring-up: [`pi-bring-up.md`](pi-bring-up.md)
- Enclosure reference: [`../enclosure/README.md`](../enclosure/README.md)
- User docs home: [`../../userdocs/README.md`](../../userdocs/README.md)

## BOM

### PCB and electronics

| Qty | Item | Exact/current part | Notes |
|---:|---|---|---|
| 1 | Custom PCB | Fabricate from [`../../release-artifacts/pcb/gerber/gerber.zip`](../../release-artifacts/pcb/gerber/gerber.zip) | Order as a two-layer PCB unless the Gerber notes say otherwise. |
| 4 | NeoTrellis 4x4 driver PCB | [Adafruit `3954`](https://www.adafruit.com/product/3954), Mouser `485-3954` | Forms the 8x8 grid. |
| 4 | Silicone 4x4 keypad | [Adafruit `1611`](https://www.adafruit.com/product/1611), Mouser `485-1611` | One per NeoTrellis board. |
| 1 | NeoKey 1x4 QT | [Adafruit `4980`](https://www.adafruit.com/product/4980), Mouser `485-4980` | Holds the four Cherry MX keys. |
| 1 | Raspberry Pi Zero 2 W with header | [Raspberry Pi Zero 2 W](https://www.raspberrypi.com/products/raspberry-pi-zero-2-w/), Mouser `358-SC0721`, Raspberry Pi `SC0721` | Use the headered version. |
| 1 | SSD1351 OLED breakout with microSD holder | [Adafruit `1431`](https://www.adafruit.com/product/1431), Mouser `485-1431` | SPI display. |
| 1 | PCM5102 I2S DAC | [Adafruit `6250`](https://www.adafruit.com/product/6250), Mouser `485-6250` | Line/headphone output path. |
| 1 | USB-C power breakout | [Adafruit `4090`](https://www.adafruit.com/product/4090), Mouser `485-4090` | Power the device here, not through the Pi. |
| 4 | Horizontal rotary encoder with switch | [RS `781-6811`](https://at.rs-online.com/web/p/mechanische-drehgeber/7816811), Bourns `PEC12R-4225F-S0024` | The PCB uses four encoders. |
| 1 | Polarized capacitor | [`470uF`, 16V, radial, about 8x12mm](https://de.aliexpress.com/item/1005010415990713.html) | PCB footprint: `CP_Radial_D8.0mm_P3.50mm`. Any equivalent 470uF polarized radial capacitor with 3.5mm lead pitch and >5V rating is fine. |
| 1 | 1x5 right-angle female socket/header, 2.54mm pitch | [2.54mm right-angle female header strip](https://de.aliexpress.com/item/32896617287.html) | Cut to 5 pins for the NeoTrellis connector on the PCB. |
| 1 | 5-wire female-to-male Dupont cable, about 5cm | [Female-to-male Dupont jumper cable set](https://de.aliexpress.com/item/1005003683781229.html) | Use five adjacent leads, about 5cm long, to connect the NeoTrellis array to the PCB. |
| several | Low-profile female header/socket strips, 2.54mm pitch | [Round-pin 2.54mm header/socket strip](https://de.aliexpress.com/item/1005006673257121.html) or [round-pin 2.54mm header/socket strip](https://de.aliexpress.com/item/4001122376295.html) | Cut to length for Pi, OLED, DAC, power breakout, and other plug-in modules. Confirm the socket height before ordering. |
| 4 | Cherry MX-compatible key switches | [Cherry MX Black switches](https://www.amazon.de/-/en/CHERRY-Mechanical-Keyboard-Switches-without/dp/B0CBS4HJJR?th=1), or any MX-compatible switch | Install into the NeoKey after bring-up. |
| 1 | MicroSD card for Raspberry Pi | 16GB or larger recommended | Flash the release image. |
| 1 | USB-C power supply | Regulated 5V supply, 3A minimum; 4A recommended for extra LED headroom | Connect only to the USB-C breakout. A 2A supply is likely marginal once the Pi and LEDs are running together. |
| 1 | Audio cable/headphones/speaker | 3.5mm audio | Used for test and operation. |

### 3D printed and mechanical parts

| Qty | Item | File/spec | Notes |
|---:|---|---|---|
| 1 | Enclosure top | `../../release-artifacts/enclosure/stl/case_top_two_level_cadquery.stl` | Generated from CadQuery. STEP file is also checked in. |
| 1 | Enclosure bottom | `../../release-artifacts/enclosure/stl/case_bottom_plate_cadquery.stl` | Current bottom plate with guide walls and screw holes. |
| 1 | Main encoder knob | Print `../../release-artifacts/enclosure/stl/encoder_cap_main_knurled_dots.stl` or use `../../release-artifacts/enclosure/3mf-multicolor/encoder_cap_main_knurled_dots_multicolor_flush.3mf` | Main encoder cap. Printed version uses the dot-ring marking. |
| 3 | Aux encoder knobs | Print `../../release-artifacts/enclosure/stl/encoder_cap_aux*_ribbed_dot*.stl` or use matching `../../release-artifacts/enclosure/3mf-multicolor/encoder_cap_aux*_multicolor_flush.3mf` | Aux 1/2/3 caps. Printed versions use one, two, and three dots. |
| 4 | MX keycaps | Print `../../release-artifacts/enclosure/stl/mx_keycap_*.stl`, use matching `../../release-artifacts/enclosure/3mf-multicolor/mx_keycap_*_multicolor_flush.3mf`, or use any MX-stem keycap | Four NeoKey caps: back, play, shift, and function/layer. Transparent filament for the cap body and dark filament for the symbols works well, either with a filament swap for the last layers or multi-material printing. |
| 8 | 9.5mm standoff pillar | Print `../../release-artifacts/enclosure/stl/standoff_pillar_9_5mm.stl` and matching `../../release-artifacts/enclosure/3mf-multicolor/standoff_pillar_9_5mm.3mf`, or use compatible purchased stackable PCB standoffs | Use for the OLED and audio/DAC board support locations. |
| 10 | 10mm standoff pillar | Print `../../release-artifacts/enclosure/stl/standoff_pillar_10mm.stl` and matching `../../release-artifacts/enclosure/3mf-multicolor/standoff_pillar_10mm.3mf`, or use compatible purchased stackable PCB standoffs | Use for the Raspberry Pi, power breakout, and NeoKey support locations. NeoTrellis array pins go straight into the bottom's integrated pillars, so they do not need separate standoff pillars. |
| 26 | Standoff top pin | Print `../../release-artifacts/enclosure/stl/standoff_top_pin_thin_base.stl` and matching `../../release-artifacts/enclosure/3mf-multicolor/standoff_top_pin_thin_base.3mf`, or use compatible purchased stackable PCB standoff pins | 4 Pi + 4 audio/DAC + 4 OLED/screen + 4 NeoKey + 2 power + 8 NeoTrellis array pins = 26 total. |
| 8 | Heat-set insert | [M3 heat-set insert](https://de.aliexpress.com/item/1005012199553197.html), about `4.0-4.2mm` outer diameter and `5-6mm` long | Insert from the underside of the top. The linked kit includes multiple sizes; use the M3 inserts that fit the `4.2mm` pilot holes. |
| 8 | Screws | M3 x 8mm socket-head cap screw, DIN 912 / ISO 4762 style | Installed from the bottom. Use a head diameter no larger than `6.4mm` so it fits the counterbores. |
| 8 | Rubber feet or screw-hole plugs | Small adhesive feet | Optional, covers bottom screw holes and prevents sliding. |

Standoff STL attribution and purchase/source reference: the standoff models are based on [Stackable PCB Standoff by theduckom](https://www.printables.com/model/163087-stackable-pcb-standoff), licensed under [Creative Commons Attribution 4.0 International](https://creativecommons.org/licenses/by/4.0/).

### Tools and consumables

- Soldering iron and solder.
- Flush cutters.
- Small screwdriver and a longish bit for bottom screws.
- Optional: Heat-set insert tool.
- Multimeter.
- Raspberry Pi Imager.
- Optional: continuity tester, tweezers, helping hands, and magnifier.

## Before soldering

1. Inspect the PCB for visible manufacturing defects.
2. Confirm the PCB matches the current Gerber zip.
3. Sort sockets, headers, and modules before soldering.
4. Keep every module oriented the same way it will sit in the enclosure.
5. Mark the correct side of every module before soldering headers.

Headers on the wrong side are difficult to fix. Check the silkscreen, enclosure orientation, and module footprint before soldering. Best double-check every header before soldering it: the correct side matters for the PCB sockets, Pi, OLED, DAC/audio breakout, power breakout, NeoKey, and NeoTrellis connector.

Reference photos:

- [Soldered PCB overview](images/assembly/soldered-pcb.jpg)
- [Raspberry Pi Zero 2 W header side](images/assembly/pi-zero-2w.jpg)
- [OLED header side](images/assembly/oled.jpg)
- [Audio breakout header side](images/assembly/audio-breakout.jpg)
- [Power breakout header side](images/assembly/power-breakout.jpg)

## Solder the main PCB

Solder low-profile sockets and headers first. They define module height and alignment.

1. Solder the low-profile sockets for the Raspberry Pi, OLED, DAC, USB-C power breakout, and any other socketed modules.
2. Solder the 1x5 right-angle female socket for the NeoTrellis connector.
3. Solder `C1`, the `470uF` polarized capacitor. Match polarity to the PCB markings.
4. Solder the four rotary encoders into `SW1` through `SW4`.

You can leave the capacitor legs a little longer than usual so the capacitor can bend sideways if you need to save vertical space. Keep polarity correct and make sure the legs cannot short against nearby pads or metal parts.

The horizontal socket for the NeoTrellis array can be a tight fit near the case pillar that supports the NeoTrellis. Consider bending the socket legs slightly before soldering, or use a vertical connector if your build has enough space. If you plug the cable in before mounting the NeoTrellis array on the pillars, it will be very tight, but will fit (barely).

Do not install plug-in modules yet.

## Build the NeoTrellis array

The four NeoTrellis boards form one 8x8 grid.

1. Arrange the boards as viewed from the play surface:
   - upper left
   - upper right
   - lower left
   - lower right
2. Solder the boards together with pin links between adjacent edges.
3. Add the external connector pins to the left side of the upper-left NeoTrellis board.
4. Set the NeoTrellis addresses:

   | Position | Jumpers | Address |
   |---|---|---:|
   | upper left | none | `0x2E` |
   | upper right | A0 | `0x2F` |
   | lower left | A1 | `0x30` |
   | lower right | A0 + A1 | `0x31` |

Use the reference photos to confirm the soldered address jumper pads:

- [NeoTrellis address jumper pads](images/assembly/neotrellis-address-jumpers.jpg)

5. Set the NeoKey address by soldering A0, A1, A2, and A3. Leave A4 open. The expected address is `0x3F`.

- [NeoKey address jumper pads](images/assembly/neokey-address-jumpers.jpg)

The NeoKey and NeoTrellis connector are the two parts that are easiest to plug in backwards. Double-check their orientation before powering the device. The simplest check is that `INT` should always be on the south side.

## Flash the Raspberry Pi image

1. Download the latest release image from the project releases. It is named like:

   ```text
   octessera-<version>-pi-zero-2w.img.zip
   ```

2. Flash it to the Pi microSD card with Raspberry Pi Imager.
3. Configure WiFi, SSH, hostname, and locale in Raspberry Pi Imager if you need network access.
4. Insert the microSD card into the Raspberry Pi.

You can flash the downloaded `.img.zip` directly with Raspberry Pi Imager by choosing **Use custom** and selecting the ZIP. You do not need to extract the ZIP first.

The release also includes Raspberry Pi Imager metadata in two places:

- inside the image ZIP as `os_list.rpi-imager-manifest`;
- next to the image ZIP as `octessera-<version>-pi-zero-2w.rpi-imager-manifest`.

If you want octessera to appear as a custom OS entry in Raspberry Pi Imager, use the standalone `.rpi-imager-manifest` release asset as Imager's custom repository manifest. Loading the manifest/custom image this way lets Raspberry Pi Imager configure locale, WiFi, SSH, hostname, and user settings before flashing.

In Raspberry Pi Imager, open **App Options**, press **Edit** next to **Content Repository**, then choose one of these options:

- **Use custom file**: select the downloaded `.rpi-imager-manifest` file.
- **Use custom URL**: paste the manifest URL from the GitHub release.

Then press **Apply and Restart**. After Imager restarts, the octessera image will show up in the **OS** list after you have selected your device type.

Reference screenshots:

- [Raspberry Pi Imager options](images/assembly/rpi-imager-options.png)
- [Content Repository setting](images/assembly/rpi-content-repository.png)
- [Custom repository source](images/assembly/rpi-repository-source.png)

You can also start Imager with the manifest URL from the command line, for example:

```powershell
rpi-imager --repo "https://github.com/nexxyz/octessera/releases/download/v<version>/octessera-<version>-pi-zero-2w.rpi-imager-manifest"
```

Use the actual release tag and version from the release page. The embedded manifest inside the ZIP is for packaged metadata; do not extract the ZIP just to load the manifest.

For manual Pi setup and diagnostics, see [`pi-bring-up.md`](pi-bring-up.md).

## First electrical assembly

1. Insert the Raspberry Pi, OLED, DAC, USB-C power breakout, and NeoKey into their sockets.
2. Connect the NeoTrellis array to the PCB with the short 5-wire female-to-male Dupont cable.
3. Install the Cherry MX switches into the NeoKey.
4. Add the four keycaps. Use either printed keycaps from `release-artifacts/enclosure/stl/` or purchased MX-stem keycaps. Install them before running diagnostics so the key checks match the assembled control feel.
5. Connect audio output to headphones, speakers, or a mixer.
6. Connect power to the USB-C breakout.

Do not power the device from the Raspberry Pi power connector.

Before applying power, check the NeoKey and NeoTrellis connector orientation again. `INT` should be on the south side.

Wait for the Pi to boot. First boot can take a while, but you should soon see the splashscreen.

Once it is up, check that none of the elements report an error. The OLED, NeoKey, and NeoTrellis can turn completely red in case of an electrical issue. The top NeoKey should light up red; that is intended because it is the Back button.

Then turn the main encoder to select the System menu, and click the main encoder to enter it. In the System menu, scroll to and run the hardware diagnostics before assembling the enclosure. Complete the guided checks for display, grid, keys, encoders, and audio while the boards are still accessible. The diagnostics can also detect inconsistent button or encoder signals. A couple of warnings are usually okay, but if the diagnostics report actual errors, double-check your soldering and components.

If the hardware does not come up, stop and use the bring-up checks in [`pi-bring-up.md`](pi-bring-up.md).

## Enclosure assembly

Only assemble the enclosure after the electrical test and System-menu diagnostics pass.

Before you start with the enclosure, you need to remove the keyswitches from the NeoKey, but you can leave the keycaps on.

1. Place the bottom enclosure on the bench.
2. Put the PCB and NeoTrellis array onto the bottom.
   - Remove the Raspberry Pi microSD card and OLED microSD card first. They can catch on the enclosure and break during installation.
3. Add the 18 separate standoff pillars between the bottom supports and the plug-in modules:
   - Use 9.5mm standoff pillars for the OLED and audio/DAC board.
   - Use 10mm standoff pillars for the Raspberry Pi, power breakout, and NeoKey.
   - Printing the 9mm, 9.5mm, and 10mm support parts in different colors makes them easier to tell apart during assembly.
   - For each plug-in module, remove the module, add the standoff, then reinstall the module.
   - You do not need separate standoff pillars for the NeoTrellis array. Its eight pins go straight into the integrated bottom pillars.
4. Press in all 26 top pins:
   - 18 pins go into the separate standoff pillars.
   - 8 pins go into the NeoTrellis array's integrated bottom pillars.
   - During final assembly, a small drop of glue on the top-pin can keep pins from falling out if the device is turned upside down.
5. Place one silicone 4x4 keypad on each NeoTrellis board. Make sure the pads sit flat and line up with the 8x8 opening before closing the case.
6. Insert the M3 heat-set inserts into the underside of the enclosure top with a soldering iron or insert tool.
7. Place the enclosure top over the assembly. It is easiest to slip the top on from the left/west side first so the ports pass through their holes, then lower the right/east side. The guide walls and standoff pins should locate the parts without forcing them.
8. Install the four printed encoder knobs from `release-artifacts/enclosure/stl/` or the matching multicolor 3MF files. Check the fit before pressing them fully down: they should slide on with a decent amount of friction, but not so tightly that removal would require force. If the fit is too tight, scale the encoder cap models up slightly in the X/Y plane before printing another set.
9. Turn the device over carefully.
10. Install the bottom screws into the recessed holes and tighten them into the heat inserts.
11. Add rubber feet or screw-hole covers if desired.

Tighten screws gently. If the top does not sit flat, stop and find the interference instead of forcing the case closed.

## Final checks

1. Connect power through the USB-C breakout.
2. Wait for boot.
3. Confirm input from all encoders, NeoKey switches, and NeoTrellis buttons.
4. Confirm the OLED is readable.
5. Confirm audio output from the DAC.
6. Confirm the Pi microSD, OLED microSD, audio, USB-C power, Pi mini-HDMI, and Pi USB data openings are accessible.

## Things to verify before ordering in quantity

- Confirm the selected M3 heat-set inserts fit the `4.2mm` pilot holes and that M3 x 8mm socket-head screws reach the inserts cleanly after printing.
- Final fit of the printed bottom, top, standoff pillars, top pins, keycaps, and encoder knobs.
- Whether the generic sockets you buy match the intended low profile.
- Whether the 5cm Dupont cable has enough slack after the NeoTrellis array is installed.
- Port alignment after printing with your printer and slicer.

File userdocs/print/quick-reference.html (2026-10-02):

octessera

# quick reference

Controls, bindings, behaviors, and Play pages across two pages.

## Regular controls

Turn Main | Navigate/edit. Numeric: plain coarse; Fn fine; Shift and Shift+Fn stay coarse. Enum, boolean, and text turns stay ordinary.
Click Main | Menu selection / select, edit, confirm
Back | Exit location / exit edit, overlay, or menu level
Play | Transport / play or pause
Shift + Play | Stop / external sync arms a one-shot resync
Fn + Play | Reset stop / stop, reset position, silence owned notes
Fn + turn Main right | Single step / advance one tick while paused/stopped
Shift + Back | Clear layer / re-initialize active layer
Shift + Fn + Main | Context help / hold modifiers, click menu item

## Navigation + bindings

Fn + left column | Navigate to Layer 1-8 / bottom row = layer 1
Hold Fn | Preview / layers and Play pages
Fn + right column | Navigate Play pages / exits if already active
Fn + Aux click | Bind focused value/action / value to turn, action to click
Fn + click Main | Open Aux mapping / 12-slot scrollable modal

Aux map: Release Fn to keep its 12-slot scrollable modal open; turn Main to scroll, click Main or press Back to close. Fn alone previews navigation only.

Auto-map fills unbound Aux 1-3 slots with values/actions for this menu area; manual bindings take priority.

1-Cutoff Aux 1 turn 1!Assign Aux 1 click

## Special grid modes

Sample assign | Shift + cell maps row; Shift + Fn + cell maps column
Drum assign | Shift+cell: row; Shift+Fn+cell: column; Cell Tune: one cell
Probability map | Trigger chance: never, low, high, always. Shift + cell = row; Shift + Fn + cell = column
Play Mix | Grid becomes a mixer for each layer's volume
Play Pan | Grid moves around layers' stereo positions
Play FX | Press mapped cells to trigger live effects
Trigger Gate | Block, allow, or use custom probability per layer. Shift+Fn together + left layer cell toggles its gate.

## Behaviors

none | Inactive layer | keys | Finger-drumming
sequencer | Manual rhythm anchor | looper | Recorded grid gestures
life | Birth/survival/death cells | brain | Pulses and trails
ant | Walking grid agent | bounce | Moving collisions
shapes | Geometric regions | raindrops | Drops and ripples
dla | Branching growth

## Triggers

activate | Cell turns on
stable | Cell stays on
deactivate | Cell turns off
scanned | Scanner finds active cell
scanned empty | Scanner visits inactive cell

## Other Play controls

XY | Mappable two-axis surface for live-manipulating parameters
Play Drums | Tap assigned cells for the selected Drum slot, even while stopped
Transpose | Synth, FM, Plucked & enabled MIDI; not Sampler/Drum

## Patch orientation

1. Route sequencer or looper to sampler for a rhythm loop.
2. Add life, raindrops, bounce, or dla to a synth.
3. Use probability on sequencer cells so patterns feel alive.
4. Bind aux encoders to parameters or actions you keep reaching for.

Aux turns: Normal target: plain coarse, Fn fine. Shifted custom bank: Shift coarse, Shift+Fn fine; no fallback. Other turns are discrete. Shift+Fn is one combined modifier.

Factory preset hint: life on Layer 1, sequencer rhythm on Layer 2.

Sample browser: .. parent; [folder] folder; file rows are samples; (empty) means no entries. Play / Space previews the highlighted sample. Long names clip or scroll without overlapping other OLED text.

Bench safety: Power through the enclosure USB-C breakout; remove both the board microSD card and OLED microSD card before closing the case.

If the grid behaves unexpectedly, check the OLED. You are probably in an overlay or Play page. Use Back or Fn to leave.

octessera / quick reference / controls, behaviors, Play

octessera

# cell state to sound

From behavior state and direct input to MIDI, internal audio, routing, and optional live FX.

Flowchart from behavior and cell state through trigger mapping, instrument routing, optional FX branches, MIDI, and audio output

octessera / cell state -> behavior -> triggers -> Link -> instrument -> output

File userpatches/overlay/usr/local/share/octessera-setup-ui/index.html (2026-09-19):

 

Octessera setup

# Wi-Fi & access setup

Connect the instrument to Wi-Fi, choose how you’ll access it, and give it a name.

Until setup finishes, anyone nearby who joins this Wi-Fi can configure the device. Stay close to it. SSH keys are recommended.

## Device setup

Country code Use the two-letter country code for the Wi-Fi radio.

Available networks Scan for networks

Manual SSID

Wi-Fi password This network is open

Local device password

This password is used at the device’s local console and for attended sudo commands. It is required even when SSH is disabled.

Password Confirm password

Use at least 8 characters.

SSH access

SSH key SSH password No SSH setup

Public key

SSH key access only; password login stays disabled.

SSH password access uses the local device password above.

Remote access stays disabled while the local device password remains available.

Device name (optional)

Apply setup

## Applying setup

The device is applying Wi-Fi and access settings now.

Watch the OLED for the final result. After success, find the address in System > Sys. Info.

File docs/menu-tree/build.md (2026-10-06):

# Build Menu Tree

This file is part of the canonical split-out menu tree spec. See [`../menu-tree-spec.md`](../menu-tree-spec.md) for the canonical index.

### Build

```
Build
├── L1: ... (group)                              ← one group per layer, label computed from the layer label
│   ├── Behavior: <id> (group)                   ← browser-style selector for this layer's behavior
│   │   ├── [Human]
│   │   │   ├── ..
│   │   │   ├── keys
│   │   │   ├── looper
│   │   │   ├── none
│   │   │   ├── sequencer
│   │   │   └── weave
│   │   ├── [Rhythm]
│   │   │   ├── ..
│   │   │   ├── polyrhythm
│   │   │   ├── breaks
│   │   │   ├── fills
│   │   │   ├── clave
│   │   │   ├── groove
│   │   │   └── euclid
│   │   ├── [Musical]
│   │   │   ├── ..
│   │   │   ├── ostinato
│   │   │   ├── motif
│   │   │   ├── canon
│   │   │   ├── chords
│   │   │   ├── contour
│   │   │   ├── cadence
│   │   │   └── phrase
│   │   ├── [Cellular]
│   │   │   ├── ..
│   │   │   ├── ant
│   │   │   ├── brain
│   │   │   ├── cyclic
│   │   │   ├── forest_fire
│   │   │   ├── life
│   │   │   ├── predator_prey
│   │   │   └── twinkle
│   │   ├── [Fields]
│   │   │   ├── ..
│   │   │   ├── ink
│   │   │   ├── ising
│   │   │   ├── kuramoto
│   │   │   ├── lightning
│   │   │   ├── raindrops
│   │   │   ├── reaction_diffusion
│   │   │   ├── rivers
│   │   │   └── wave
│   │   ├── [Geometry]
│   │   │   ├── ..
│   │   │   ├── fractal_explorer
│   │   │   ├── maze_growth
│   │   │   └── shapes
│   │   ├── [Growth]
│   │   │   ├── ..
│   │   │   ├── coral
│   │   │   ├── cracks
│   │   │   ├── crystal_growth
│   │   │   ├── dla
│   │   │   ├── physarum
│   │   │   └── vines
│   │   ├── [Motion]
│   │   │   ├── ..
│   │   │   ├── bounce
│   │   │   ├── bubbles
│   │   │   ├── gravity
│   │   │   ├── boids
│   │   │   ├── lava_lamp
│   │   │   ├── orbit
│   │   │   └── sand_ripples
│   ├── Auto Label: [on | off]                   ← on: label auto-derives from behavior ID; off: label is manual text
│   ├── Layer Label: (text, max 32)               ← display label; editing sets Auto Label off
│   ├── Step Rate: [1/32T, 1/32, 1/16T, 1/16, 1/8T, 1/8, 1/4T, 1/4, 1/2T, 1/2, 1/1T, 1/1]   ← controls how often onTick() is called; hidden when Behavior is `none`
│   ├── ... per-behavior dynamic config from behavior's configMenu()
│   ├── Seeded: [off | on]                       ← on: this layer's behavior randomness follows Build > Seed; hidden when Behavior is `none`
│   └── Reset                                    ← reinitializes the active behavior state; hidden when Behavior is `none`
├── L2: ... (group)
├── L3: ... (group)                              ← up to layerCount layers total
└── Seed: [1..9999] step 1                       ← shared seed for every Seeded Build layer and Link layer (default 1)
```

Rows that open submenus or selectors render with a trailing `>`. Selecting a behavior row switches that layer immediately through the native runtime and returns focus to the layer's Behavior row. It does not rebuild the full menu tree; only the affected Build layer rows are refreshed. Behavior IDs remain the persisted payload values under each layer's `behaviorId`.
`glider` is no longer selectable. Its glider injection controls are part of `life`.
When Auto Label is on, the layer label is derived from the active behavior ID (e.g. `life`, `brain`). Editing the Layer Label text field switches Auto Label off.
Layer selectors (Fn+column selection, Link Layer selector) display the computed layer label (e.g. `L1: life`, `L2: rain`).
When a layer's behavior is `none`, the Build layer group shows Behavior, Auto Label, and Layer Label only; Step Rate, dynamic behavior config rows, Seeded, and Reset are hidden without deleting stored values.
`Seed` sits after the layer groups so the Build cursor still lands on the active layer. It is persisted per patch as `runtimeConfig.randomSeed`; each layer's `Seeded` is `layers.N.build.seeded` (default off). Unseeded layers keep their fresh, unrepeatable randomness. A Seeded layer draws all behavior randomness, including hash-style choices and the Rhythm/Musical/weave pattern `Seed`, from a stream mixed from the global Seed and the layer index. Seeded streams restart on play-from-stop, transport stop, external MIDI start, patch load, and when Seed or the layer's Seeded switch changes. Restarting a stream never resets an evolved grid, so exact replay starts from the same world (a loaded patch with saved grid state, or Reset). Audio-rate noise in instruments and FX is never seeded.
Parameter target pickers mirror the main menu root order (`Build`, `Link`, `Shape`, `Play`, `System`). Within `Build`, behavior `none` layers expose no Behavior targets, while real behavior layers expose `layers.N.algorithmStep` and `layers.N.build.behaviorConfig.*` targets under their own layer label.

Behavior categories:

| Category | Behaviors | Description |
|---|---|---|
| Human | keys, looper, none, sequencer, weave | Direct performance, recording, silence, step-style behaviors, and hand-playable pattern nudges. |
| Rhythm | polyrhythm, breaks, fills, clave, groove, euclid | Rhythm-first pattern worlds for interlocking pulses, asymmetry, breaks, fills, and Euclidean-style grids. |
| Musical | ostinato, motif, canon, chords, contour, cadence, phrase | Pitch-shape pattern worlds for repeated figures, delayed echoes, chord blocks, contours, cadences, and longer phrases. |
| Cellular | ant, brain, cyclic, forest_fire, life, predator_prey, twinkle | Cell-state simulations where neighboring cells or agents create evolving patterns. |
| Fields | ink, ising, kuramoto, lightning, raindrops, reaction_diffusion, rivers, wave | Field-style activity that spreads from localized events. |
| Geometry | fractal_explorer, maze_growth, shapes | Dynamic fractal exploration, maze carving, and explicit geometric pulse patterns. |
| Growth | coral, cracks, crystal_growth, dla, physarum, vines | Coral, crack, crystal, slime, vine, and diffusion-limited clusters that grow from seeded particles. |
| Motion | bounce, bubbles, gravity, boids, lava_lamp, orbit, sand_ripples | Moving objects, blobs, flocking/orbiting agents, bubbles, dunes, and granular avalanches through the grid. |

Behavior-specific config items (from `configMenu()`):

| Behavior | Config Items | Type/Options |
|---|---|---|
| none | *(none)* | — |
| life | Spawn Count: [0..20] | number, step 1 (default 12) |
| life | Spawn Interval: [1..20] | number, step 1 (default 1) |
| life | Glider Interval: [0..20] | number, step 1 (default 0; 0 disables automatic glider injection) |
| life | Spawn Step: [0..63] | number, step 1 |
| life | !Spawn Random | action, shared route `trigger.life.spawn_now` |
| life | !Spawn Glider | action, shared route `trigger.life.spawn_now` |
| sequencer | *(none)* | — |
| keys | Quantize: [immediate, step] | enum |
| looper | !Punch In/Out | action |
| looper | Length: [1..64] | number, step 1 (default 16) |
| looper | !Clear Loop | action |
| weave, Rhythm-category behaviors, Musical-category behaviors | Density: [10..80] | number, step 5 |
| weave, Rhythm-category behaviors, Musical-category behaviors | Variation: [0..100] | number, step 5 |
| weave, Rhythm-category behaviors, Musical-category behaviors | Cycle: [4..32] | number, step 1 |
| weave, Rhythm-category behaviors, Musical-category behaviors | Seed: [1..9999] | number, step 1 |
| brain | Fire Threshold: [1..4] | number, step 1 (default 2) |
| brain | Seed Interval: [0..30] | number, step 1 (default 2; 0 disables scheduled seeding) |
| brain | Spawn Step: [0..63] | number, step 1 (default 0) |
| brain | Spawn Count: [0..20] | number, step 1 (default 2) |
| brain | !Seed Random | action, shared route `trigger.life.spawn_now` |
| cyclic | States: [3..8] | number, step 1 (default 4) |
| cyclic | Threshold: [1..8] | number, step 1 (default 1) |
| cyclic | Range: [1..2] | number, step 1 (default 1) |
| cyclic | !Seed Cycle | action, shared route `trigger.life.spawn_now` |
| forest_fire | Tree Density: [0..100] | number, step 1 (default 34) |
| forest_fire | Grow Chance: [0..100] | number, step 1 (default 5) |
| forest_fire | Spread Chance: [0..100] | number, step 1 (default 70) |
| forest_fire | Reseed Threshold: [0..100] | number, step 1 (default 5) |
| forest_fire | Lightning: [0..20] | number, step 1 (default 1; per-thousand chance) |
| forest_fire | !Ignite Random | action, shared route `trigger.life.spawn_now` |
| predator_prey | Grass Grow: [0..100] | number, step 1 (default 15) |
| predator_prey | Herbivore Repro: [0..100] | number, step 1 (default 15) |
| predator_prey | Predator Repro: [0..100] | number, step 1 (default 8) |
| predator_prey | Starve Ticks: [1..32] | number, step 1 (default 8) |
| predator_prey | !Reseed Ecosystem | action, shared route `trigger.life.spawn_now` |
| twinkle | Density: [1..5] | number, step 1 (default 3; hard star cap) |
| twinkle | Birth Chance: [0..100] | number, step 1 (default 70) |
| twinkle | Fade Chance: [0..100] | number, step 1 (default 35) |
| twinkle | Star Life: [1..32] | number, step 1 (default 8; minimum fade age) |
| twinkle | Cluster Bias: [0..100] | number, step 1 (default 40; clipped neighborhood preference) |
| twinkle | Seed: [0..65535] | number, step 1 (default 1) |
| twinkle | !Reseed Stars | action, deterministic reset using `seed` |
| twinkle | !Clear Stars | action, clears the constellation without changing configuration |
| ant | Max Ants: [1..10] | number, step 1 |
| ant | !Spawn Ant | action, shared route `trigger.life.spawn_now` |
| bounce | Max Balls: [1..20] | number, step 1 |
| bounce | !Add Ball | action, shared route `trigger.life.spawn_now` |
| bubbles | Spawn Interval: [0..30] | number, step 1 |
| bubbles | Spawn Step: [0..63] | number, step 1 |
| bubbles | Spawn Count: [1..8] | number, step 1 |
| bubbles | Min Radius: [1..4] | number, step 1 |
| bubbles | Max Radius: [1..4] | number, step 1 |
| bubbles | Drift: [0..8] | number, step 1; eighth-cell units |
| bubbles | Current: [-8..8] | number, step 1; eighth-cell units |
| bubbles | Buoyancy: [1..8] | number, step 1; eighth-cell units |
| bubbles | Max Bubbles: [1..64] | number, step 1 |
| bubbles | !Add Bubble | action, shared route `trigger.life.spawn_now` |
| gravity | Spawn Rate: [0..100] | number, step 1 (default 20) |
| gravity | Slide Chance: [0..100] | number, step 1 (default 60) |
| gravity | Settle Age: [1..32] | number, step 1 (default 8) |
| gravity | Gravity Dir: [down, left, up, right] | enum |
| gravity | !Drop Sand | action, shared route `trigger.life.spawn_now` |
| gravity | !Clear Bottom | action, shared route `trigger.life.spawn_now` |
| gravity | !Invert Gravity | action, shared route `trigger.life.spawn_now` |
| boids | Flock Size: [1..24] | number, step 1 (default 12) |
| boids | Separation: [0..100] | number, step 1 (default 45) |
| boids | Alignment: [0..100] | number, step 1 (default 35) |
| boids | Cohesion: [0..100] | number, step 1 (default 25) |
| boids | !Scatter Flock | action, shared route `trigger.life.spawn_now` |
| boids | !Seed Flock | action, shared route `trigger.life.spawn_now` |
| orbit | Particle Count: [1..16] | number, step 1 (default 8) |
| orbit | Attraction: [0..100] | number, step 1 (default 45) |
| orbit | Orbit: [0..100] | number, step 1 (default 55) |
| orbit | Repel Mode: [off, always] | enum |
| orbit | !Reset Orbit | action, shared route `trigger.life.spawn_now` |
| orbit | !Nudge Attractor | action, shared route `trigger.life.spawn_now` |
| lava_lamp | Blob Count: [1..8] | number, step 1 (default 4) |
| lava_lamp | Viscosity: [0..100] | number, step 1 (default 30) |
| lava_lamp | Heat: [0..100] | number, step 1 (default 45) |
| lava_lamp | Merge: [0..100] | number, step 1 (default 25) |
| lava_lamp | !Heat Lamp | action, shared route `trigger.life.spawn_now` |
| lava_lamp | !Reset Blobs | action, shared route `trigger.life.spawn_now` |
| sand_ripples | Wind Strength: [0..100] | number, step 1 (default 45) |
| sand_ripples | Deposition: [0..100] | number, step 1 (default 35) |
| sand_ripples | Erosion: [0..100] | number, step 1 (default 25) |
| sand_ripples | !Gust | action, shared route `trigger.life.spawn_now` |
| sand_ripples | !Shift Wind | action, shared route `trigger.life.spawn_now` |
| sand_ripples | !Seed Dunes | action, shared route `trigger.life.spawn_now` |
| shapes | Shape: [ring, filled, diamond, cross, x] | enum |
| shapes | Lifespan: [1..12] | number, step 1 (default 3) |
| shapes | Max Radius: [4..32] | number, step 1 (default 12) |
| shapes | Spawn Interval: [0..20] | number, step 1 (default 4; 0 disables scheduled pulses) |
| shapes | Spawn Step: [0..63] | number, step 1 (default 2) |
| shapes | !Spawn Pulse | action, shared route `trigger.life.spawn_now` |
| fractal_explorer | Zoom Rate: [0..100] | number, step 1 (default 8) |
| fractal_explorer | Drift: [0..100] | number, step 1 (default 20) |
| fractal_explorer | Iteration Limit: [8..64] | number, step 1 (default 24) |
| fractal_explorer | Fractal Mode: [mandelbrot, julia] | enum |
| fractal_explorer | !Jump Region | action, shared route `trigger.life.spawn_now` |
| fractal_explorer | !Toggle Fractal Mode | action, shared route `trigger.life.spawn_now` |
| maze_growth | Carve: [0..100] | number, step 1 (default 55) |
| maze_growth | Collapse Age: [1..64] | number, step 1 (default 32) |
| maze_growth | Walker Count: [1..8] | number, step 1 (default 2) |
| maze_growth | !Restart Maze | action, shared route `trigger.life.spawn_now` |
| maze_growth | !Collapse Maze | action, shared route `trigger.life.spawn_now` |
| ink | Diffusion: [0..100] | number, step 1 (default 30) |
| ink | Fade: [0..100] | number, step 1 (default 8) |
| ink | Drop Strength: [1..255] | number, step 1 (default 180) |
| ink | !Drop Ink | action, shared route `trigger.life.spawn_now` |
| ink | !Clear Ink | action, shared route `trigger.life.spawn_now` |
| ising | Temperature: [0..100] | number, step 1 (default 35) |
| ising | Field Strength: [0..100] | number, step 1 (default 15) |
| ising | Noise: [0..100] | number, step 1 (default 8) |
| ising | !Heat Pulse | action, shared route `trigger.life.spawn_now` |
| ising | !Flip Field | action, shared route `trigger.life.spawn_now` |
| ising | !Randomize Spins | action, shared route `trigger.life.spawn_now` |
| reaction_diffusion | Feed: [0..100] | number, step 1 (default 35) |
| reaction_diffusion | Kill: [0..100] | number, step 1 (default 55) |
| reaction_diffusion | Diffusion: [0..100] | number, step 1 (default 35) |
| reaction_diffusion | Reaction: [0..100] | number, step 1 (default 50) |
| reaction_diffusion | Seed Interval: [0..64] | number, step 1 (default 3; 0 disables scheduled seeding) |
| reaction_diffusion | Spawn Step: [0..63] | number, step 1 (default 2) |
| reaction_diffusion | !Seed Chemicals | action, shared route `trigger.life.spawn_now` |
| reaction_diffusion | !Clear Chemicals | action, shared route `trigger.life.spawn_now` |
| rivers | Rain: [0..100] | number, step 1 (default 20) |
| rivers | Flow: [0..100] | number, step 1 (default 50) |
| rivers | Erosion: [0..100] | number, step 1 (default 15) |
| rivers | Evaporation: [0..100] | number, step 1 (default 8) |
| rivers | !Rain Burst | action, shared route `trigger.life.spawn_now` |
| rivers | !Reset Terrain | action, shared route `trigger.life.spawn_now` |
| kuramoto | Coupling: [0..100] | number, step 1 (default 10) |
| kuramoto | Frequency Spread: [0..32] | number, step 1 (default 10) |
| kuramoto | Jitter: [0..100] | number, step 1 (default 20) |
| kuramoto | !Desync Pulse | action, shared route `trigger.life.spawn_now` |
| lightning | Branch Chance: [0..100] | number, step 1 (default 25) |
| lightning | Jitter Chance: [0..100] | number, step 1 (default 20) |
| lightning | Decay Ticks: [1..16] | number, step 1 (default 4) |
| lightning | Leader Limit: [1..8] | number, step 1 (default 3) |
| lightning | Target Edge: [north, east, south, west] | enum (default south) |
| lightning | !Strike Now | action, shared route `trigger.life.spawn_now` |
| wave | Damping: [0..100] | number, step 1 (default 4) |
| wave | Tension: [0..100] | number, step 1 (default 25) |
| wave | Impulse Strength: [1..127] | number, step 1 (default 80) |
| wave | Impulse Interval: [0..64] | number, step 1 (default 4; 0 disables scheduled impulses) |
| wave | Spawn Step: [0..63] | number, step 1 (default 3) |
| wave | !Drop Impulse | action, shared route `trigger.life.spawn_now` |
| raindrops | !Drop Now | action, shared route `trigger.life.spawn_now` |
| cracks | Stress: [0..100] | number, step 1 (default 20) |
| coral | Growth: [0..100] | number, step 1 (default 35) |
| coral | Competition: [0..100] | number, step 1 (default 20) |
| coral | Breakaway Age: [1..64] | number, step 1 (default 30) |
| coral | !Seed Coral | action, shared route `trigger.life.spawn_now` |
| coral | !Break Coral | action, shared route `trigger.life.spawn_now` |
| cracks | Branch: [0..100] | number, step 1 (default 18) |
| cracks | Propagation: [0..100] | number, step 1 (default 100) |
| cracks | Shatter Threshold: [1..64] | number, step 1 (default 24) |
| cracks | !Impact | action, shared route `trigger.life.spawn_now` |
| cracks | !Replace Pane | action, shared route `trigger.life.spawn_now` |
| crystal_growth | Growth Chance: [0..100] | number, step 1 (default 45) |
| crystal_growth | Seed Interval: [0..64] | number, step 1 (default 16; 0 disables scheduled seeding) |
| crystal_growth | Seed Step: [0..63] | number, step 1 |
| crystal_growth | Cell Life: [0..256] | number, step 1; `0` disables aging/removal |
| crystal_growth | Symmetry: [cross, diagonal, snowflake] | enum |
| crystal_growth | !Seed Crystal | action, shared route `trigger.life.spawn_now` |
| dla | Spawn Interval: [1..20] | number, step 1 |
| dla | Spawn Step: [0..63] | number, step 1 |
| dla | Cell Life: [0..256] | number, step 1; `0` disables DLA aging/removal |
| dla | !Seed Cluster | action, shared route `trigger.life.spawn_now` |
| physarum | Agent Count: [1..32] | number, step 1 (default 20) |
| physarum | Sense Distance: [1..3] | number, step 1 (default 1) |
| physarum | Turn Bias: [0..100] | number, step 1 (default 55) |
| physarum | Deposit Amount: [1..64] | number, step 1 (default 18) |
| physarum | Evaporation: [0..100] | number, step 1 (default 18) |
| physarum | !Relocate Food | action, shared route `trigger.life.spawn_now` |
| physarum | !Seed Slime | action, shared route `trigger.life.spawn_now` |
| vines | Growth: [0..100] | number, step 1 (default 55) |
| vines | Branch: [0..100] | number, step 1 (default 18) |
| vines | Prune Age: [1..64] | number, step 1 (default 24) |
| vines | Light Bias: [0..100] | number, step 1 (default 50) |
| vines | !Plant Seed | action, shared route `trigger.life.spawn_now` |
| vines | !Prune Vines | action, shared route `trigger.life.spawn_now` |

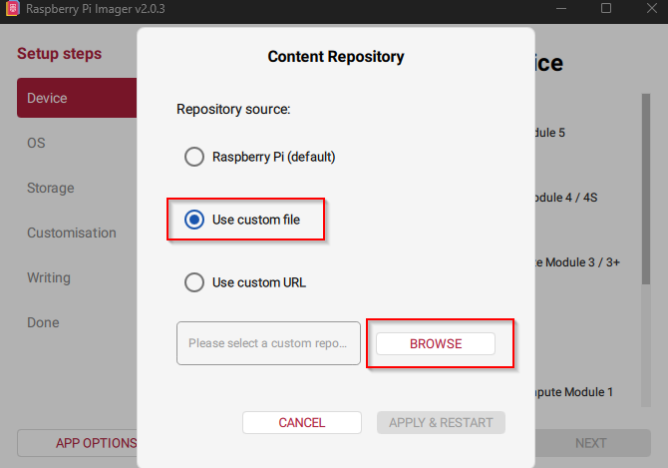
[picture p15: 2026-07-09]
userdocs/hardware/images/assembly/rpi-repository-source.png

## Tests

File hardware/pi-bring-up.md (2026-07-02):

# Raspberry Pi Bring-Up

This is the current end-user bring-up guide for the Raspberry Pi Zero 2 W hardware target.

Use it with:

- [`pinout-and-connections.md`](pinout-and-connections.md) for wiring and pin ownership.
- [`enclosure/README.md`](enclosure/README.md) for case, ports, and power rules.
- [`../docs/menu-and-controls-spec.md`](../docs/menu-and-controls-spec.md) for runtime controls and OLED/grid behavior.

## Hardware Target

- Compute: Raspberry Pi Zero 2 W
- Grid: four NeoTrellis 4x4 boards chained as an 8x8 matrix over I2C bus 1
- Buttons: NeoKey 1x4 over I2C bus 1
- Display: SSD1351 128x128 RGB OLED over SPI
- Audio: PCM5102-class DAC through the ADA6250 connector over I2S
- Controls: four clickable direct-GPIO rotary encoders: one main and three aux controls
- Power input: USB-C breakout to the shared `+5V` rail
- Bulk power smoothing: `C1` `470uf` polarized capacitor across `+5V` and `GND`
- I2C addresses: NeoTrellis `0x2E`, `0x2F`, `0x30`, `0x31`; NeoKey `0x3F`

## Power Rule

Power the device through the enclosure USB-C power input only.

Do not power the Raspberry Pi through its own micro-USB power port. The enclosure intentionally covers that connector.

## Software Path

- App: `apps/pi-zero`
- HAL crate: `crates/hal`
- Runtime: `crates/playback-runtime::NativeRunner`
- Core behavior logic: `crates/platform-core`
- Audio engine: `crates/realtime-engine` through `crates/rodio-engine-source`

The Pi app is native Rust. It does not start Node or TypeScript.

The device is intended to run as an appliance. The Pi app should launch on boot through `cellsymphony.service`. SSH is for setup, diagnostics, logs, and updates.

## Pi OS Boot Configuration

Use Raspberry Pi OS Lite. Configure `/boot/firmware/config.txt` so GPIO ownership matches the hardware:

```text
dtparam=audio=off

# I2S DAC: GPIO18 BCK, GPIO19 LRCK, GPIO21 DIN.
# Custom playback-only overlay keeps GPIO20 free for card detect.
dtoverlay=i2s-dac-no20

# OLED and OLED-module SD path.
dtparam=spi=on

# NeoTrellis and NeoKey.
dtparam=i2c_arm=on

# GPIO14 and GPIO15 are application GPIO, not UART.
enable_uart=0
```

After reboot, verify the I2S/card-detect split:

```bash
pinctrl get 18 19 20 21
```

Expected ownership:

- `GPIO18`, `GPIO19`, and `GPIO21`: PCM/I2S alternate function
- `GPIO20`: GPIO input for OLED microSD card detect

## Preflight Before Full Assembly

On the development PC:

```bash
cargo build -p cellsymphony-pi
cargo test -p platform-core -p playback-runtime
cargo test -p cellsymphony-pi render
```

On the Pi, before all hardware is attached:

```bash
ls /dev/i2c-1 /dev/spidev0.0
pinctrl get 2 3 7 8 9 10 11 14 15 18 19 20 21 23 16
aplay -l
```

From Windows, run the SSH preflight helper:

```powershell
./tools/pi-preflight.ps1 -Target pi@192.168.0.211
```

Running the normal app before the PCB/components are attached is only a negative smoke test. Missing OLED or I2C devices should fail clearly rather than silently falling back.

## Build And Deploy

Host-stub build:

```bash
cargo build -p cellsymphony-pi
```

Preferred hardware iteration from Windows:

```powershell
./tools/build-pi-cross.ps1
./tools/deploy-pi-fast.ps1 -Target pi@192.168.0.211 -LocalBinary target/pi-cross/cellsymphony-pi -NoTail
```

Fallback on-Pi build:

```powershell
./tools/deploy-pi-fast.ps1 -Target pi@192.168.0.211 -BuildOnPi -NoTail -AllowServiceFailure
```

`tools/deploy-pi-fast.ps1` preserves the Pi `target/` cache by default. Use `-CleanRemote` only when intentionally discarding that cache.

## Release Image

Explicit GitHub releases include a ready-to-flash Pi Zero 2 W image named `CellSymphony-<version>-pi-zero-2w.img.zip`.

The image is derived from standard Raspberry Pi OS Bookworm arm64 through pi-gen and includes:

- the release `cellsymphony-pi` binary built with `--release --features hardware-pi`;
- `cellsymphony.service` and the performance governor service;
- runtime audio/I2C/SPI dependencies;
- Cell Symphony boot config and the `i2s-dac-no20` overlay;
- empty `/home/pi/samples` and `/home/pi/presets` directories.

The release image must not include WiFi credentials, SSH keys, GitHub tokens, host logs, or local user secrets. SSH is disabled by default. Configure network access after first boot if you need SSH for setup.

## Verified Development Pi State

The current development Pi at `pi@192.168.0.211` has been verified with `tools/pi-preflight.ps1`:

- Raspberry Pi OS Lite aarch64, kernel `6.18.34+rpt-rpi-v8`
- Persistent journald enabled through `/var/log/journal`
- `dtparam=i2c_arm=on`, `dtparam=spi=on`, `dtparam=audio=off`, `enable_uart=0`, and `dtoverlay=i2s-dac-no20` active
- `/dev/i2c-1` and `/dev/spidev0.0` exist and are accessible to user `pi`
- GPIO14 and GPIO15 are GPIO inputs, not UART
- GPIO18/19/21 are PCM/I2S and GPIO20 remains input for card detect
- ALSA exposes the PCM5102/HifiBerry-style DAC
- `rppal` `0.22.1` is required for this OS/kernel; older `0.14.1` failed model detection
- On-Pi fallback builds with `CARGO_BUILD_JOBS=1 cargo build --profile pi-dev -p cellsymphony-pi --features hardware-pi` succeed but take about 24 minutes on first build
- The app enters persistent hardware fault mode instead of restart-looping when critical hardware initialization fails
- PCM5102/HifiBerry-style DAC output has produced a 440 Hz ALSA test tone on the physical hardware
- NeoKey has been detected at `0x3F` on the PCB I2C path
- NeoTrellis has been detected at `0x2E`, `0x2F`, `0x30`, and `0x31` through a corrected connector path
- The tested SSD1351 OLED module stayed blank with both the Pi and an Arduino Uno running Adafruit SSD1351 test code; replace or independently verify the module before treating PCB or runtime display output as failed
- During active bring-up, `cellsymphony.service` may be disabled to prevent automatic I2C access while checking wiring; re-enable it only after the clean bus scan matches the expected devices

## Bring-Up Checklist

1. Verify `+5V` and `+3.3V` rails under load.
2. Detect NeoTrellis at `0x2E`, `0x2F`, `0x30`, and `0x31`, and NeoKey at `0x3F`.
3. Initialize OLED and render a runtime snapshot frame.
4. Initialize DAC and produce audio output through the realtime engine path.
5. Verify each encoder direction and push switch.
6. Verify all grid coordinates and LED colors.
7. Verify transport timing and MIDI clock behavior.
8. Verify preset/default storage and sample browser paths.

Current open validation work is tracked in [`../docs/open-work.md`](../docs/open-work.md).
The no-OLED manual walkthrough and CLI diagnostics are defined in [`manual-hardware-test-suite.md`](manual-hardware-test-suite.md).

Quick diagnostics:

```bash
sudo systemctl disable --now cellsymphony.service
/usr/local/bin/cellsymphony-pi --hardware-test
/usr/local/bin/cellsymphony-pi --hardware-noise-test --skip-trellis --skip-encoders
```

The diagnostics print a final warning/failure summary. Raw NeoKey one-sample glitches with clean immediate rereads are warnings; confirmed idle input remains a failure.

## Planned Hardware Diagnostics

A future `System > Diagnostics > Hardware Test` action should guide the user through:

1. OLED color bars, border, text, and brightness steps.
2. NeoKey press and LED checks.
3. Encoder left/right/push checks.
4. NeoTrellis corner press and LED sweep checks.
5. DAC test tone through the realtime audio path.
6. OLED microSD card-detect GPIO state.
7. Summary and diagnostic log.

Implementation boundary: `playback-runtime` owns the menu action and platform effect; `apps/pi-zero` and `crates/hal` own hardware probes.

## Update/Rollback Plan

Use a simple A/B binary swap first:

1. Upload a release bundle containing `cellsymphony-pi`, version metadata, and optional resources.
2. Write it to `/opt/cellsymphony/releases/<version>/`.
3. Verify checksum and executable bit.
4. Update `/opt/cellsymphony/current` atomically.
5. Restart `cellsymphony.service`.
6. Keep the previous symlink target for rollback.

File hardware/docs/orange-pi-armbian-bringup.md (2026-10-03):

# Orange Pi Zero 2W Armbian bring-up

This is the ordered Orange Pi Zero 2W bring-up procedure for
the established Armbian production path. Use it at the workbench. The detailed
production image, service, storage, audio, USB, and updater contracts live in
the [Orange production reference](orange-pi-production-reference.md); image
construction commands live in
[`docs/workflows/image-construction-and-proof.md`](../../docs/workflows/image-construction-and-proof.md).

This is a hardware gate. Do not copy Raspberry Pi constants, overlays, or
`rppal` GPIO assumptions into Orange Pi support until these checks pass on the
target board and image. The Raspberry and Orange images, pinouts, ports, and
recovery paths are not interchangeable.

## Target context

- Board: Orange Pi Zero 2W, 2 GB RAM.
- Production image: Armbian Debian 13/Trixie for Orange Pi Zero 2W.
- Wiring goal: the same Octessera PCB and harness as the Raspberry Pi Zero 2 W
  build, with Orange-specific pin and port mapping.
- Exact profile: `orange-pi-zero-2w`; exact Armbian board ID: `orangepizero2w`.

Read [`docs/board-profiles.md`](../../docs/board-profiles.md) for the board
profile and artifact naming contract.

## Direct encoder mapping

H618 offsets use the established `port base + pin` mapping (`PC12 = 76`,
`PI14 = 270`). Do not use Raspberry BCM numbering.

| Encoder | A physical / H618 / offset | B physical / H618 / offset | Switch physical / H618 / offset | Implementation |
| --- | --- | --- | --- | --- |
| SW1 main | 29 / PI0 / 256 | 31 / PI15 / 271 | 32 / PI11 / 267 | available |
| SW2 aux1 | 33 / PI12 / 268 | 22 / PI6 / 262 | 11 / PH2 / 226 | available |
| SW3 aux2 | 13 / PH3 / 227 | 7 / PI13 / 269 | 8 / PH0 / 224 | A/B implemented; switch waits for UART0-disabled routing |
| SW4 aux3 | 37 / PI16 / 272 | 18 / PH4 / 228 | 15 / PI5 / 261 | available |

The Orange event boundary reverses all four literal board A/B directions; the
Raspberry path remains `rppal`-based. AUX2 A/B may be requested while UART0 is
active; its switch request is omitted until input-routing boot. Switch debounce
is 45 ms.

## Ordered bring-up

### 1. Choose and inspect the image

Use the exact Orange production or diagnostic mode described in the
[production reference](orange-pi-production-reference.md). Do not use a
Raspberry image or a runtime-only updater ZIP as a full image. Follow the
linked image workflow for image construction and its source checks.

Before any board change, inspect the basic Armbian state:

```sh
cat /etc/os-release
uname -a
cat /proc/device-tree/model 2>/dev/null || true
cat /boot/armbianEnv.txt
ls -R /boot/dtb/*/overlay /boot/dtb/overlay 2>/dev/null || true
ls /sys/class/udc 2>/dev/null || true
ls /dev/i2c-* /dev/spidev* 2>/dev/null || true
gpioinfo 2>/dev/null || true
aplay -l 2>/dev/null || true
USB_CONFIG_RE='CONFIGFS_FS|USB_LIBCOMPOSITE|USB_CONFIGFS|USB_F_UAC2|USB_F_MIDI'
zcat /proc/config.gz 2>/dev/null | grep -E "$USB_CONFIG_RE" || true
grep -E "$USB_CONFIG_RE" /boot/config-$(uname -r) 2>/dev/null || true
```

Install `gpiod` if `gpioinfo` is missing. Armbian uses `/boot/armbianEnv.txt`
and U-Boot overlays, not Raspberry `/boot/config.txt`, `dtoverlay=` names, or
BCM numbering. The reviewed SPI1 OLED+SD2 source is
`userpatches/overlay/usr/local/share/octessera/device-tree/octessera-h618-spi1-oled-sd2.dts`;
do not substitute the stock `spidev1_0` overlay. SD2 chip select is header
pin 26; H618 PH9 is SPI1 CS1 with mux `0x4`, while the OLED is SPI1 CS0.
Before using the shared OLED/microSD wiring, verify its coexistence with the
live kernel and the electrical setup.

### 2. Verify setup and SSH

To exercise the setup portal on either fixed board path:

- at the instrument, choose `System > Setup > Configure WiFi > Open Portal`;
- join the setup AP and load the captive page;
- apply Wi-Fi, hostname, SSH mode, and login settings;
- wait for the OLED terminal result before reconnecting;
- observe the 10-minute user window after portal readiness and its timeout;
- inspect AP traffic, HTTP responses, the current status file at
  `/run/octessera-setup-status/current.json`, logs, and artifacts for secret
  leakage.

An AP disconnect while settings apply is expected. Setup requires a usable
global `wlan0` IPv4 address; it does not require Internet access, a default
route, DNS, or ICMP.

Once SSH is reachable, run the read-only Windows probe:

```powershell
$OrangeTarget = "orangepi@<ORANGE_HOST>"
.\tools\orange-pi\run-opi-bringup.ps1 -Target $OrangeTarget
```

The owner check requires passwordless `sudo -n` or a root SSH session. Add
`-WithSudoChecks` only after SSH/recovery is stable. The probe never binds a
gadget; use the separate composer for USB tests.

### 3. Check passive peripherals

Before active transfers, GPIO requests, audio, or gadget binding, check:

- confirm the live DT/pinmux for I2C, SPI1/CS0, OLED D/C/reset, I2S, USB role,
  and UDC;
- device nodes, GPIO ownership, `aplay -l`, and `/sys/class/udc`;
- scan I2C for the NeoTrellis/NeoKey devices on the correct physical bus;
- run a minimal OLED transfer and confirm MOSI, SCLK, CS, DC, and reset pins;
- use `gpioinfo` and edge events for encoders, buttons, NeoKey, and NeoTrellis;
- record polarity and pullup/pulldown requirements;
- expose the expected I2S card, use `hw:CARD=octesseradac,DEV=0` at 44.1 kHz,
  and run a short playback plus underrun check.

The production image constructs the AHUB0 dummy-codec route
on APB0/DMA3/TDM0 and names the playback card exactly `octessera-dac`
(`octesseradac` in ALSA). It installs and composes the canonical overlay during
image construction; this is not an experimental or manual overlay procedure.

An HDMI/default ALSA sound does not establish the I2S route. Use the DAC pins
and live audio card when checking that route.

### 4. Check USB gadget behavior

Before binding, verify which USB-C port is OTG/data, the power topology, VBUS,
CC and role handling, and host sleep/replug behavior. An empty
`/sys/class/udc`, an unproven role, backfeed, brownout, pre-bound controller,
or failed teardown is a stop condition. Do not use Raspberry `dwc2` assumptions
or bind a pre-existing gadget.

The official hardware name for the gadget-capable MUSB/peripheral controller is
USB0. Use unambiguous physical connector names; do not infer them from user
numbering.

Run the fake-configfs contract check first:

```sh
bash ./tools/orange-pi/test-orange-pi-usb-gadget.sh
```

For host checks, inspect `lsusb -v`, the UAC2 endpoint `Octessera Audio`, the
combined composite product `Octessera Audio + MIDI`, and Windows
`DEVPKEY_Device_BusReportedDeviceDesc`. The setup gate is writable ConfigFS
`interface_string`; the actual MIDI interface descriptor, bus-reported value,
and MIDI Services endpoints must equal `Octessera MIDI`. Verify high-speed
combined UAC2+MIDI, 44.1 kHz stereo capture of a board-generated 1 kHz tone on
both channels, and exact MIDI traffic in both directions. See the [Orange
production reference](orange-pi-production-reference.md#usb-identity-boundary)
for the fixed USB identity contract.

The Orange SD2 source/image contract includes the fixed
`/run/octessera-orange-storage-control/storage.sock` seam and label-safe
`OCTESSERA` lifecycle.

For USB hardware testing:

- Use the exact release constructor image for the named identity and functional
  checks.
- Verify physical connector mapping, VBUS/CC/no-backfeed electrical behavior,
  physical reconnect and host suspend/resume, SD2 mass-storage
  start/eject/stop recovery, and the configured VID/PID values.

Before connecting a host to an instrument powered from the enclosure USB-C
input, follow the [safety and power
guidance](../../userdocs/hardware/safety-and-power.md) for
the fixed USB-A host path. Ordinary host cables carry VBUS; avoid
USB-C-to-USB-C/PD and do not treat the connector choice as isolation. This is
the no-backfeed safety gate.

### 5. Run the runtime diagnostic command

Run the non-destructive fixed-board diagnostic:

```sh
/usr/local/bin/octessera-pi --fat-diagnostic \
  --board-profile orange-pi-zero-2w \
  --evidence-dir "/tmp/octessera-fat-diagnostic-orange"
```

The diagnostic reports identity, readiness, service, storage, audio-route, and
USB state without binding USB, playing audio, or actuating the control surface.
`--hardware-test` and `--hardware-noise-test` are Raspberry interactive modes
and are rejected on Orange.

### Exact-source application FAT (not image FAT)

The command above checks the installed production runtime under
`/opt/octessera/releases` with the strict `octessera-runtime.json` contract. It
does not qualify the image. For an exact cross-built candidate, keep the
production service running, copy the binary and unchanged sidecar, and run:

```sh
cp /path/to/octessera-pi /tmp/octessera-pi
cp /path/to/octessera-pi.metadata.json /tmp/octessera-pi.metadata.json
chmod 0755 /tmp/octessera-pi
/tmp/octessera-pi --fat-diagnostic \
  --board-profile orange-pi-zero-2w \
  --evidence-dir "/tmp/octessera-fat-diagnostic-orange-candidate"
```

Do not copy the candidate into `/usr/local/bin` or `/opt/octessera/releases`,
and do not stop, restart, or replace the service. Candidate evidence names the
resolved executable, full source commit, and
`image_fat_claim=not_evaluated`. Run separate image FAT and construction checks
to qualify the image.

### 6. Fault handling

Stop before use when any mapping, power, recovery, UDC, I2S, GPIO, OLED,
control-surface, thermal, or service check fails. Fix the source, image, wiring,
or device before continuing.

The production runtime's selected-route readiness, service account, storage,
updater, and power boundaries are defined in the [technical
reference](orange-pi-production-reference.md).

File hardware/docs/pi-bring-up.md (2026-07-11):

# Raspberry Pi Bring-Up

This is the current end-user bring-up guide for the Raspberry Pi Zero 2 W hardware target.

The goal is simple: build, flash, start, and run diagnostics until the instrument proves that its buses, display, controls, and audio path behave.

Use it with:

- [`../../userdocs/README.md`](../../userdocs/README.md) for the user-facing docs home.
- [`pinout-and-connections.md`](pinout-and-connections.md) for wiring and pin ownership.
- [`../enclosure/README.md`](../enclosure/README.md) for case, ports, and power rules.
- [`../../docs/menu-and-controls-spec.md`](../../docs/menu-and-controls-spec.md) for runtime controls and OLED/grid behavior.

## Hardware Target

- Compute: Raspberry Pi Zero 2 W
- Grid: four NeoTrellis 4x4 boards chained as an 8x8 matrix over I2C bus 1
- Buttons: NeoKey 1x4 over I2C bus 1
- Display: SSD1351 128x128 RGB OLED over SPI
- Audio: PCM5102-class DAC through the ADA6250 connector over I2S
- Controls: four clickable direct-GPIO rotary encoders: one main and three aux controls
- Power input: USB-C breakout to the shared `+5V` rail
- Bulk power smoothing: `C1` `470uf` polarized capacitor across `+5V` and `GND`
- I2C addresses: NeoTrellis `0x2E`, `0x2F`, `0x30`, `0x31`; NeoKey `0x3F`

## Power Rule

Power the device through the enclosure USB-C power input only.

Do not power the Raspberry Pi through its own micro-USB power port. The enclosure intentionally covers that connector.

## Software Path

- App: `apps/pi-zero`
- HAL crate: `crates/hal`
- Runtime: `crates/playback-runtime::NativeRunner`
- Core behavior logic: `crates/platform-core`
- Audio engine: `crates/realtime-engine` through `crates/rodio-engine-source`

The Pi app is native Rust. It does not start Node or TypeScript.

The device is intended to run as an appliance. The Pi app should launch on boot through `octessera.service`. SSH is only for debugging, logs, and updates; it is not part of normal bring-up.

## Pi OS Boot Configuration

Use Raspberry Pi OS Lite. Configure `/boot/firmware/config.txt` so GPIO ownership matches the hardware:

```text
dtparam=audio=off

# I2S DAC: GPIO18 BCK, GPIO19 LRCK, GPIO21 DIN.
# Custom playback-only overlay keeps GPIO20 free for card detect.
dtoverlay=i2s-dac-no20

# OLED and OLED-module SD path.
dtparam=spi=on

# NeoTrellis and NeoKey.
dtparam=i2c_arm=on

# GPIO14 and GPIO15 are application GPIO, not UART.
enable_uart=0
```

After reboot, verify the I2S/card-detect split:

```bash
pinctrl get 18 19 20 21
```

Expected ownership:

- `GPIO18`, `GPIO19`, and `GPIO21`: PCM/I2S alternate function
- `GPIO20`: GPIO input for OLED microSD card detect

## Preflight Before Full Assembly

On the development PC:

```bash
cargo build -p octessera-pi
cargo test -p platform-core -p playback-runtime
cargo test -p octessera-pi render
```

On the Pi, before all hardware is attached:

```bash
ls /dev/i2c-1 /dev/spidev0.0
pinctrl get 2 3 7 8 9 10 11 14 15 18 19 20 21 23 16
aplay -l
```

Optional SSH debugging helpers:

```powershell
./tools/pi/pi-preflight.ps1 -Target pi@192.168.0.211
```

If the instrument still runs but SSH or `octessera.local` disappears during debugging, collect the network diagnostics before rebooting when possible:

```powershell
./tools/pi/collect-network-diagnostics.ps1 -Target pi@192.168.0.211
```

The report includes local reachability, WiFi power state, NetworkManager/SSH state, `brcmfmac` firmware errors, and `/var/log/octessera/network-health.log`. You do not need this for a normal first boot unless the network itself is what you are debugging.

Running the normal app before the PCB/components are attached is only a negative smoke test. Missing OLED or I2C devices should fail clearly rather than silently falling back.

## Build And Deploy

Host-stub build:

```bash
cargo build -p octessera-pi
```

Preferred hardware iteration from Windows:

```powershell
./tools/pi/build-pi-cross.ps1
./tools/pi/deploy-pi-fast.ps1 -Target pi@192.168.0.211 -LocalBinary target/pi-cross/octessera-pi -NoTail
```

Fallback on-Pi build:

```powershell
./tools/pi/deploy-pi-fast.ps1 -Target pi@192.168.0.211 -BuildOnPi -NoTail -AllowServiceFailure
```

`tools/pi/deploy-pi-fast.ps1` preserves the Pi `target/` cache by default. Use `-CleanRemote` only when intentionally discarding that cache.

## Release Image

Explicit GitHub releases include a ready-to-flash Pi Zero 2 W image named `octessera-<version>-pi-zero-2w.img.zip`.

The image is derived from standard Raspberry Pi OS Bookworm arm64 through pi-gen and includes:

- the release `octessera-pi` binary built with `--release --features hardware-pi`;
- `octessera.service` and the performance governor service;
- runtime audio/I2C/SPI dependencies;
- octessera boot config and the `i2s-dac-no20` overlay;
- empty `/home/pi/samples` and `/home/pi/presets` directories.

The release image must not include WiFi credentials, SSH keys, GitHub tokens, host logs, or local user secrets. SSH is disabled by default. Configure network access after first boot if you need SSH for setup.

## Verified Development Pi State

The current development Pi at `pi@192.168.0.211` has been verified with `tools/pi/pi-preflight.ps1`:

- Raspberry Pi OS Lite aarch64, kernel `6.18.34+rpt-rpi-v8`
- Persistent journald enabled through `/var/log/journal`
- `dtparam=i2c_arm=on`, `dtparam=spi=on`, `dtparam=audio=off`, `enable_uart=0`, and `dtoverlay=i2s-dac-no20` active
- `/dev/i2c-1` and `/dev/spidev0.0` exist and are accessible to user `pi`
- GPIO14 and GPIO15 are GPIO inputs, not UART
- GPIO18/19/21 are PCM/I2S and GPIO20 remains input for card detect
- ALSA exposes the PCM5102/HifiBerry-style DAC
- `rppal` `0.22.1` is required for this OS/kernel; older `0.14.1` failed model detection
- On-Pi fallback builds with `CARGO_BUILD_JOBS=1 cargo build --profile pi-dev -p octessera-pi --features hardware-pi` succeed but take about 24 minutes on first build
- The app enters persistent hardware fault mode instead of restart-looping when critical hardware initialization fails
- PCM5102/HifiBerry-style DAC output has produced a 440 Hz ALSA test tone on the physical hardware
- NeoKey has been detected at `0x3F` on the PCB I2C path
- NeoTrellis has been detected at `0x2E`, `0x2F`, `0x30`, and `0x31` through a corrected connector path
- The tested SSD1351 OLED module stayed blank with both the Pi and an Arduino Uno running Adafruit SSD1351 test code; replace or independently verify the module before treating PCB or runtime display output as failed
- During active bring-up, `octessera.service` may be disabled to prevent automatic I2C access while checking wiring; re-enable it only after the clean bus scan matches the expected devices

## Bring-Up Checklist

1. Verify `+5V` and `+3.3V` rails under load.
2. Detect NeoTrellis at `0x2E`, `0x2F`, `0x30`, and `0x31`, and NeoKey at `0x3F`.
3. Initialize OLED and render a runtime snapshot frame.
4. Initialize DAC and produce audio output through the realtime engine path.
5. Verify each encoder direction and push switch.
6. Verify all grid coordinates and LED colors.
7. Verify transport timing and MIDI clock behavior.
8. Verify preset/default storage and sample browser paths.

Current open validation work is tracked in [`../../docs/open-work.md`](../../docs/open-work.md).
The no-OLED manual walkthrough and CLI diagnostics are defined in [`manual-hardware-test-suite.md`](manual-hardware-test-suite.md).

Quick diagnostics:

```bash
sudo systemctl disable --now octessera.service
/usr/local/bin/octessera-pi --hardware-test
/usr/local/bin/octessera-pi --hardware-noise-test --skip-trellis --skip-encoders
```

The diagnostics print a final warning/failure summary. Raw NeoKey one-sample glitches with clean immediate rereads are warnings; confirmed idle input remains a failure.

## Planned Hardware Diagnostics

A future `System > Diagnostics > Hardware Test` action should guide the user through:

1. OLED color bars, border, text, and brightness steps.
2. NeoKey press and LED checks.
3. Encoder left/right/push checks.
4. NeoTrellis corner press and LED sweep checks.
5. DAC test tone through the realtime audio path.
6. OLED microSD card-detect GPIO state.
7. Summary and diagnostic log.

Implementation boundary: `playback-runtime` owns the menu action and platform effect; `apps/pi-zero` and `crates/hal` own hardware probes.

## Update/Rollback Plan

Use a simple A/B binary swap first:

1. Upload a release bundle containing `octessera-pi`, version metadata, and optional resources.
2. Write it to `/opt/octessera/releases/<version>/`.
3. Verify checksum and executable bit.
4. Update `/opt/octessera/current` atomically.
5. Restart `octessera.service`.
6. Keep the previous symlink target for rollback.

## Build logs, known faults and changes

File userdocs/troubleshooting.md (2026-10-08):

# Troubleshooting

Find the symptom that matches what you see, then follow the linked page.
Power down before opening the case, moving wiring, or reseating a connector.

| Symptom | First action | Next page |
|---|---|---|
| OLED is blank, flickering, unstable, or shows two writers | Power down and check the display connections. | [Flash and first boot](hardware/flash-and-first-boot.md) |
| Setup hotspot or page does not appear | Keep the device powered while following the setup steps; do not interrupt an apply in progress. | [Flash and first boot](hardware/flash-and-first-boot.md) |
| Setup finished but the hotspot disappeared | Reconnect using the new network or credentials, then start a new setup action if needed. | [Flash and first boot](hardware/flash-and-first-boot.md) |
| No sound from the device | Check the selected instrument, layer level, output route, and cable. Start with a synth. | [Controls](controls-cheat-sheet.md), [behaviors](behaviors-and-play.md) |
| USB audio or MIDI is missing | Check the documented data port, cable direction, and enclosure power input. | [USB roles](hardware/usb-roles.md), [safety and power](hardware/safety-and-power.md#usb-data) |
| Crackles or short dropouts while playing | Thin out dense patches or switch **System > Audio > Perf. Mode** to Capacity, and avoid updates or SSH maintenance while playing. | [Playing in front of people](README.md#playing-in-front-of-people) |
| Controls or grid respond unexpectedly | Look at the OLED for a Play page or other mode, then press **Back** or navigate with **Fn**. | [Controls cheat sheet](controls-cheat-sheet.md) |
| Brownout, reboot, heat, or power instability | Power down and check the regulated supply, input, cables, and ventilation. | [Safety and power](hardware/safety-and-power.md), [assembly manual](hardware/assembly-manual.md) |
| A sample is missing | Check the file path and format. The sampler uses WAV files; user samples can be added through the sample browser or board sample paths. | [Desktop simulator](desktop-simulator.md), [Flash and first boot](hardware/flash-and-first-boot.md) |
| The case does not fit or a port is blocked | Do not force it. Remove the microSD cards and check the fit and cable routing. | [Assembly manual](hardware/assembly-manual.md), [enclosure notes](hardware/enclosure.md) |
| Desktop simulator has no sound | Choose the computer's available audio output, choose a synth, and press **Space**. | [Desktop simulator](desktop-simulator.md#make-a-first-sound) |

If none of these matches, stop before changing wiring and return to the
[flash and first-boot guide](hardware/flash-and-first-boot.md), [USB roles](hardware/usb-roles.md),
or [safety and power](hardware/safety-and-power.md) page that best fits the
problem.

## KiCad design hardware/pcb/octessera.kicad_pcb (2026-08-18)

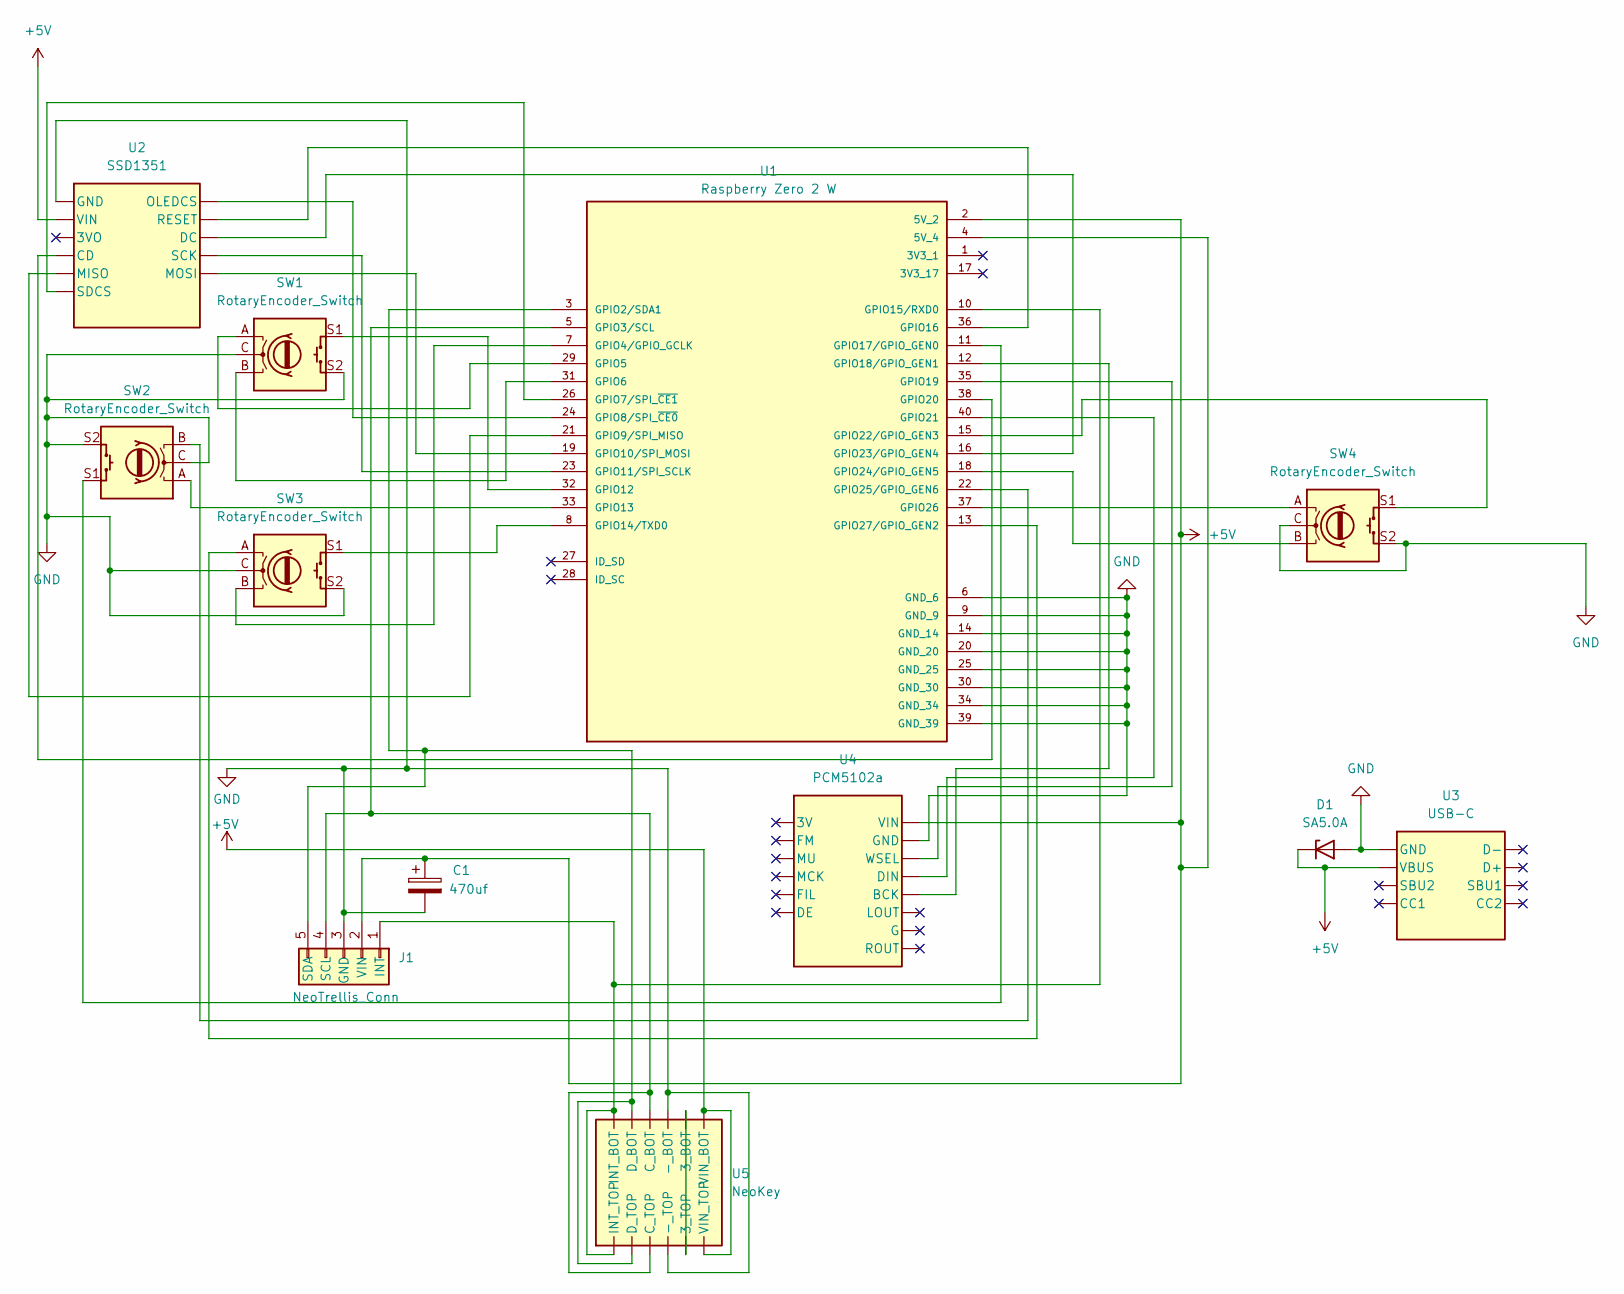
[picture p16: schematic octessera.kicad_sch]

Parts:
C1: 470uf; CP_Radial_D8.0mm_P3.50mm
D1: SA5.0A; D_DO-15_P10.16mm_Horizontal
J1: NeoTrellis_Conn; Adafruit_NeoTrellis_Connector_1x5
SW1, SW2, SW3, SW4: RotaryEncoder_Switch; RotaryEncoder_Alps_EC11E-Switch_Vertical_H20mm
U1: Raspberry Zero 2 W; MODULE_RASPBERRY_PI_ZERO_2_W; PARTREV April 2024
U2: SSD1351; Adafruit_SSD1351_OLED
U3: USB-C; Adafruit_USB_C_Breakout
U4: PCM5102a; Adafruit_PCM510x_I2S_DAC_6250
U5: NeoKey; Adafruit_NeoKey_1x4_QT

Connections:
+5V: C1.1, D1.1 (K), J1.2 (VIN), U1.2 (5V_2), U1.4 (5V_4), U2.+ (VIN), U3.VBUS, U4.VIN, U5.VIN (VIN_TOP)
GND: C1.2, D1.2 (A), J1.3 (GND), SW1.C, SW1.S2, SW2.C, SW2.S2, SW3.C, SW3.S2, SW4.C, SW4.S2, U1.6 (GND_6), U1.9 (GND_9), U1.14 (GND_14), U1.20 (GND_20), U1.25 (GND_25), U1.30 (GND_30), U1.34 (GND_34), U1.39 (GND_39), U2.G (GND), U3.GND, U4.GND, U5.- (-_TOP)
unnamed: J1.1 (INT), U1.10 (GPIO15/RXD0), U5.INT (INT_TOP)
unnamed: J1.4 (SCL), U1.5 (GPIO3/SCL), U5.C (C_TOP)
unnamed: J1.5 (SDA), U1.3 (GPIO2/SDA1), U5.D (D_TOP)
unnamed: SW3.B, U1.7 (GPIO4/GPIO_GCLK)
unnamed: SW1.A, U1.29 (GPIO5)
unnamed: SW1.B, U1.31 (GPIO6)
unnamed: U1.26 (GPIO7/SPI_~CE1), U2.SC (SDCS)
unnamed: U1.24 (GPIO8/SPI_~CE0), U2.OC (OLEDCS)
unnamed: U1.21 (GPIO9/SPI_MISO), U2.SO (MISO)
unnamed: U1.19 (GPIO10/SPI_MOSI), U2.SI (MOSI)
unnamed: U1.23 (GPIO11/SPI_SCLK), U2.CL (SCK)
unnamed: SW1.S1, U1.32 (GPIO12)
unnamed: SW2.A, U1.33 (GPIO13)
unnamed: SW3.S1, U1.8 (GPIO14/TXD0)
unnamed: U1.36 (GPIO16), U2.R (RESET)
unnamed: SW2.S1, U1.11 (GPIO17/GPIO_GEN0)
unnamed: U1.12 (GPIO18/GPIO_GEN1), U4.BCK
unnamed: U1.35 (GPIO19), U4.WSEL
unnamed: U1.38 (GPIO20), U2.CD
unnamed: U1.40 (GPIO21), U4.DIN
unnamed: SW4.S1, U1.15 (GPIO22/GPIO_GEN3)
unnamed: U1.16 (GPIO23/GPIO_GEN4), U2.DC
unnamed: SW4.B, U1.18 (GPIO24/GPIO_GEN5)
unnamed: SW2.B, U1.22 (GPIO25/GPIO_GEN6)
unnamed: SW4.A, U1.37 (GPIO26)
unnamed: SW3.A, U1.13 (GPIO27/GPIO_GEN2)

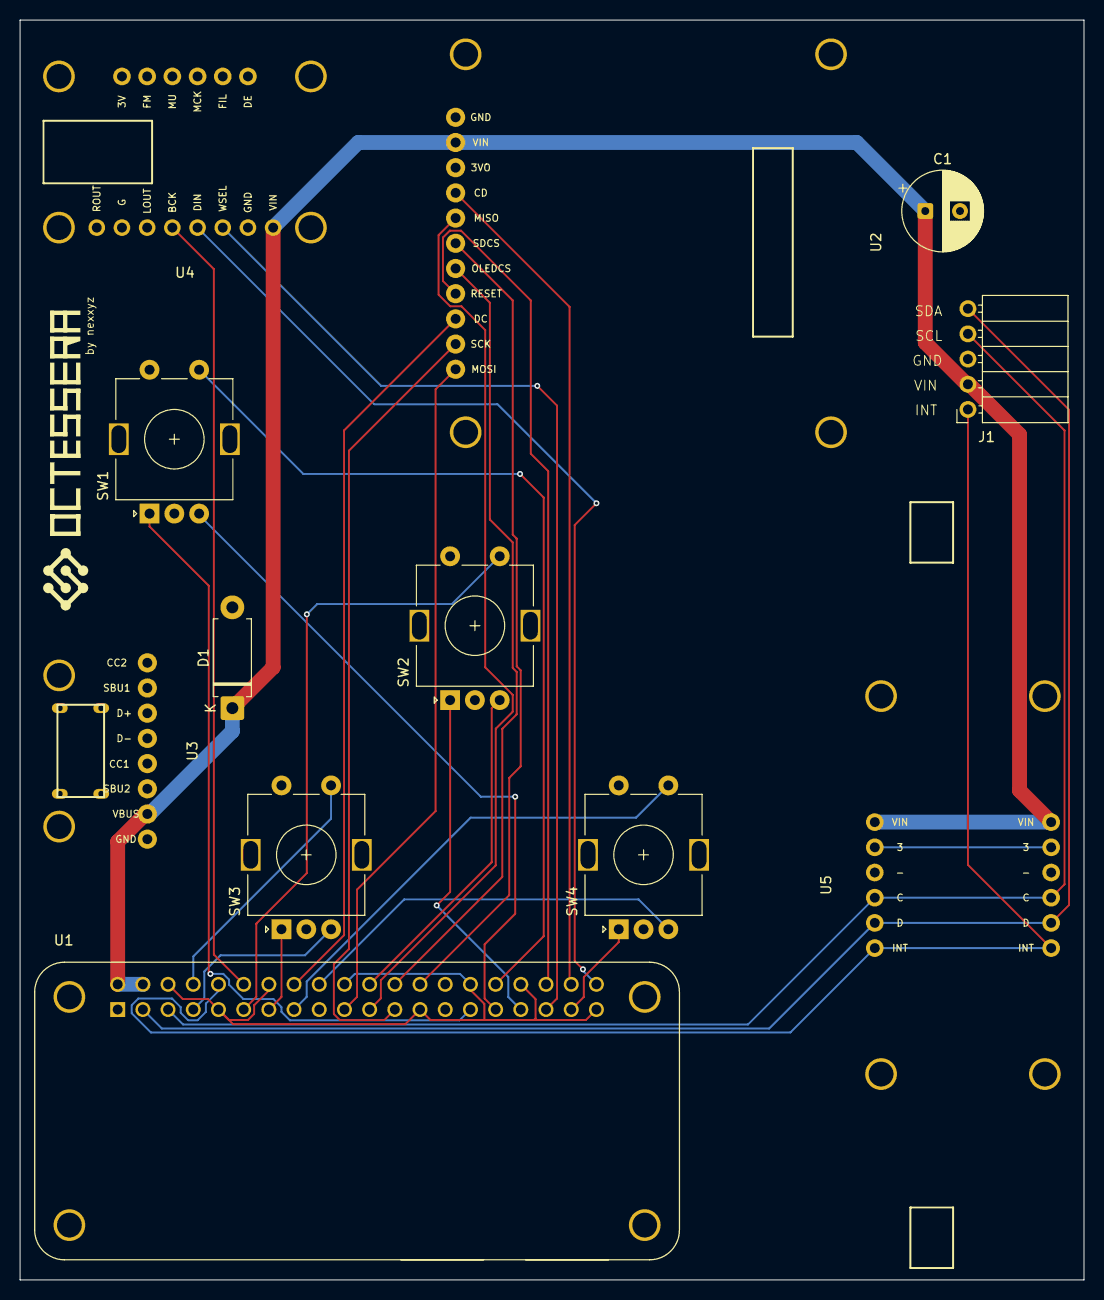
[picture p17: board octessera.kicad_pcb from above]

Board: 2 copper layers, 107.2 x 127.0 mm, 12 parts (0 on the bottom side), 28 nets.

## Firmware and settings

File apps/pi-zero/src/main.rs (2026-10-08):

#[cfg(feature = "hardware-orange-pi-zero-2w")]
mod input;
#[cfg(feature = "hardware-orange-pi-zero-2w")]
mod orange_device_apply;
#[cfg(feature = "hardware-orange-pi-zero-2w")]
mod orange_runtime;
mod render;
mod render_loop;
mod render_loop_queue;
mod seesaw_io;

#[cfg(feature = "native-audio")]
mod audio;
#[cfg(feature = "native-audio")]
mod audio_config_parse;
#[cfg(feature = "native-audio")]
mod audio_engine_owner;
#[cfg(feature = "native-audio")]
mod audio_event;
#[cfg(feature = "native-audio")]
mod audio_priority;
#[cfg(feature = "native-audio")]
mod audio_recording;
#[cfg(feature = "native-audio")]
mod audio_replay;
#[cfg(feature = "native-audio")]
mod audio_route;
#[cfg(feature = "native-audio")]
mod audio_stream_health;
#[cfg(feature = "native-audio")]
mod autoaux_menu;
#[cfg(feature = "native-audio")]
mod autoaux_sequence;
mod bluetooth;
mod boot_oled_handoff;
#[cfg(not(feature = "hardware-orange-pi-zero-2w"))]
mod boot_startup_delayed;
mod candidate_readiness;
mod device_update;
mod dsp_profile;
mod dsp_scenarios;
mod encoder_queue;
mod fat_diagnostic;
#[cfg(not(feature = "hardware-orange-pi-zero-2w"))]
mod hardware_fault;
#[cfg(not(feature = "hardware-orange-pi-zero-2w"))]
mod hardware_init;
mod hardware_runtime_scheduler;
#[cfg(not(feature = "hardware-orange-pi-zero-2w"))]
mod hardware_test;
#[cfg(not(feature = "hardware-orange-pi-zero-2w"))]
mod hardware_test_noise;
#[cfg(feature = "native-audio")]
mod hdmi_connector;
mod host_adapter;
#[cfg(feature = "native-audio")]
mod host_audio_command;
#[cfg(feature = "native-audio")]
mod host_audio_prep;
#[cfg(feature = "native-audio")]
mod host_power_lifecycle;
#[cfg(feature = "native-audio")]
mod initial_audio_prep;
#[cfg(all(feature = "native-audio", not(feature = "hardware-orange-pi-zero-2w")))]
mod input;
mod keyboard_capture;
#[cfg(any(
    feature = "hardware-orange-pi-zero-2w",
    all(
        feature = "hardware-raspberry-pi-zero-2w",
        feature = "routing-tree-benchmark",
        feature = "benchmark-voice-pools-128",
    )
))]
mod live_audio_benchmark;
mod main_paths;
#[cfg(feature = "external-midi")]
mod midi_host;
mod native_scene_pump;
mod normal_menu;
mod oled_frame_cache;
#[cfg(not(feature = "hardware-orange-pi-zero-2w"))]
mod oled_utility;
#[cfg(feature = "hardware-orange-pi-zero-2w")]
mod orange_audio;
#[cfg(feature = "hardware-orange-pi-zero-2w")]
mod orange_oled_suspend;
#[cfg(feature = "hardware-orange-pi-zero-2w")]
mod orange_oled_suspend_policy;
#[cfg(feature = "hardware-orange-pi-zero-2w")]
mod orange_reboot;
mod persistence;
#[cfg(feature = "native-audio")]
mod pi_boot_config;
mod pi_host_core;
#[cfg(test)]
mod pi_store_test_support;
mod platform_service;
mod power_lifecycle;
#[cfg(not(feature = "hardware-orange-pi-zero-2w"))]
mod raspberry_power;
#[cfg(not(feature = "hardware-orange-pi-zero-2w"))]
mod raspberry_runtime;
#[cfg(not(feature = "hardware-orange-pi-zero-2w"))]
mod rpi_device_apply;
#[cfg(not(feature = "hardware-orange-pi-zero-2w"))]
mod rpi_oled_handoff_runtime;
mod runtime_dispatch;
#[cfg(feature = "native-audio")]
mod runtime_init;
#[cfg(feature = "native-audio")]
mod runtime_loop;
#[cfg(feature = "native-audio")]
mod runtime_output;
mod runtime_thread;
mod sample_browser;
mod setup_portal;
mod setup_portal_files;
mod setup_portal_paths;
mod setup_portal_worker;
#[cfg(feature = "native-audio")]
mod show_hold;
#[cfg(test)]
mod test_temp_dir;
mod timing_input;
mod timing_load;
#[cfg(not(feature = "hardware-orange-pi-zero-2w"))]
mod timing_probe;
mod ui_profile;
#[cfg(not(feature = "hardware-orange-pi-zero-2w"))]
#[cfg(test)]
mod update_menu_fixture_tests;
#[cfg(feature = "native-audio")]
mod usb_config;
#[cfg(feature = "native-audio")]
mod usb_config_validation;
mod user_data_archive;
mod user_data_restore;
mod user_data_transfer;
mod utility_mode;
mod wake_trace;
#[cfg(not(feature = "hardware-orange-pi-zero-2w"))]
use audio::AudioManager;
#[cfg(not(feature = "hardware-orange-pi-zero-2w"))]
use hardware_init::{init_encoders, init_hardware, HardwareDevices};
#[cfg(not(feature = "hardware-orange-pi-zero-2w"))]
use input::{midi_realtime_message, MidiMessage};
#[cfg(not(feature = "hardware-orange-pi-zero-2w"))]
use render::HardwareRenderTargets;
#[cfg(not(feature = "hardware-orange-pi-zero-2w"))]
use render_loop::RenderWorker;
#[cfg(not(feature = "hardware-orange-pi-zero-2w"))]
use std::sync::mpsc;
#[cfg(not(feature = "hardware-orange-pi-zero-2w"))]
use std::sync::Arc;

#[cfg(not(feature = "hardware-orange-pi-zero-2w"))]
use main_paths::{default_samples_dir, default_store_dir, ensure_runtime_dirs};
use octessera_pi::board_profile;

#[cfg(not(all(
    feature = "hardware-raspberry-pi-zero-2w",
    feature = "routing-tree-benchmark",
    feature = "benchmark-voice-pools-128",
)))]
fn raspberry_benchmark_requested() -> bool {
    raspberry_benchmark_requested_from(std::env::args().skip(1))
}

#[cfg(all(
    feature = "hardware-raspberry-pi-zero-2w",
    feature = "routing-tree-benchmark",
    feature = "benchmark-voice-pools-128",
))]
fn orange_benchmark_requested_from(mut args: impl Iterator<Item = String>) -> bool {
    args.any(|arg| arg == "--benchmark-orange-audio")
}

#[cfg(any(
    test,
    not(all(
        feature = "hardware-raspberry-pi-zero-2w",
        feature = "routing-tree-benchmark",
        feature = "benchmark-voice-pools-128",
    ))
))]
fn raspberry_benchmark_requested_from(mut args: impl Iterator<Item = String>) -> bool {
    args.any(|arg| arg == "--benchmark-raspberry-audio")
}

#[cfg(feature = "native-audio")]
fn pin_normal_startup_thread() {
    if let Err(error) = audio_priority::pin_main_thread_to_cpu0() {
        eprintln!("Normal startup CPU affinity failed: {error}");
        std::process::exit(2);
    }
}

#[cfg(feature = "hardware-orange-pi-zero-2w")]
fn main() {
    if raspberry_benchmark_requested() {
        eprintln!("--benchmark-raspberry-audio requires the Raspberry diagnostic benchmark build");
        std::process::exit(2);
    }
    let utility_mode = match utility_mode::from_process() {
        Ok(mode) => mode,
        Err(error) => {
            eprintln!("Utility mode error: {error}");
            std::process::exit(2);
        }
    };
    if utility_mode == utility_mode::UtilityMode::Normal
        && octessera_pi::board_profile::metadata_requested()
    {
        octessera_pi::board_profile::print_build_metadata();
        return;
    }
    match utility_mode {
        utility_mode::UtilityMode::FatDiagnostic => std::process::exit(fat_diagnostic_exit_code()),
        utility_mode::UtilityMode::InteractiveHardware
        | utility_mode::UtilityMode::InteractiveNoise => {
            eprintln!(
                "interactive hardware test is only available on the canonical Raspberry build"
            );
            std::process::exit(2);
        }
        utility_mode::UtilityMode::Normal => {}
    }
    if dsp_profile::profile_requested() && live_audio_benchmark::requested() {
        eprintln!("--profile-dsp and live audio benchmark cannot be combined");
        std::process::exit(2);
    }
    if dsp_profile::profile_requested() {
        std::process::exit(exit_code(dsp_profile::run_dsp_profile().is_ok()));
    }
    if live_audio_benchmark::requested() {
        let result = live_audio_benchmark::run();
        if let Err(error) = &result {
            eprintln!("Live audio benchmark failed: {error}");
        }
        std::process::exit(exit_code(result.is_ok()));
    }
    #[cfg(feature = "native-audio")]
    pin_normal_startup_thread();
    #[cfg(target_os = "linux")]
    audio_priority::lock_process_memory();
    if let Err(error) = runtime_thread::run_on_runtime_thread(orange_runtime::run) {
        eprintln!("Orange foreground candidate failed: {error}");
        std::process::exit(error.exit_code());
    }
}

#[cfg(not(feature = "hardware-orange-pi-zero-2w"))]
fn main() {
    #[cfg(all(
        feature = "hardware-raspberry-pi-zero-2w",
        feature = "routing-tree-benchmark",
        feature = "benchmark-voice-pools-128",
    ))]
    if orange_benchmark_requested_from(std::env::args().skip(1)) {
        eprintln!("--benchmark-orange-audio requires the Orange diagnostic benchmark build");
        std::process::exit(2);
    }
    #[cfg(not(all(
        feature = "hardware-raspberry-pi-zero-2w",
        feature = "routing-tree-benchmark",
        feature = "benchmark-voice-pools-128",
    )))]
    if raspberry_benchmark_requested()
        || std::env::args()
            .skip(1)
            .any(|arg| arg == "--benchmark-orange-audio")
    {
        eprintln!("live audio benchmark arguments require their matching diagnostic build");
        std::process::exit(2);
    }
    let utility_mode = match utility_mode::from_process() {
        Ok(mode) => mode,
        Err(error) => {
            eprintln!("Utility mode error: {error}");
            std::process::exit(2);
        }
    };
    if utility_mode == utility_mode::UtilityMode::Normal && board_profile::metadata_requested() {
        board_profile::print_build_metadata();
        return;
    }
    match utility_mode {
        utility_mode::UtilityMode::FatDiagnostic => std::process::exit(fat_diagnostic_exit_code()),
        utility_mode::UtilityMode::InteractiveHardware => {
            std::process::exit(exit_code(hardware_test::run_interactive()))
        }
        utility_mode::UtilityMode::InteractiveNoise => {
            std::process::exit(exit_code(hardware_test::run_noise_only()))
        }
        utility_mode::UtilityMode::Normal => {}
    }

    #[cfg(all(
        feature = "hardware-raspberry-pi-zero-2w",
        feature = "routing-tree-benchmark",
        feature = "benchmark-voice-pools-128",
    ))]
    {
        if dsp_profile::profile_requested() && live_audio_benchmark::requested() {
            eprintln!("--profile-dsp and live audio benchmark cannot be combined");
            std::process::exit(2);
        }
        if dsp_profile::profile_requested() {
            std::process::exit(exit_code(dsp_profile::run_dsp_profile().is_ok()));
        }
        if live_audio_benchmark::requested() {
            #[cfg(feature = "native-audio")]
            pin_normal_startup_thread();
            let result = live_audio_benchmark::run();
            if let Err(error) = &result {
                eprintln!("Live audio benchmark failed: {error}");
            }
            std::process::exit(exit_code(result.is_ok()));
        }
    }

    run_requested_utility();

    #[cfg(feature = "native-audio")]
    pin_normal_startup_thread();
    #[cfg(all(target_os = "linux", feature = "hardware-raspberry-pi-zero-2w"))]
    audio_priority::lock_process_memory();
    let _ = simple_logger::init();

    let handoff_mode = match boot_oled_handoff::mode_from_env() {
        Ok(mode) => mode,
        Err(error) => {
            eprintln!("{error}");
            std::process::exit(2);
        }
    };

    if let Err(error) = board_profile::validate_runtime_profile() {
        eprintln!("{error}");
        std::process::exit(2);
    }

    println!("octessera - Pi native runtime");

    let store_dir = default_store_dir();
    let (usb_config, audio_optimization) = match usb_config::read_boot_runtime_config(&store_dir) {
        Ok(config) => config,
        Err(error) => {
            eprintln!("Pi System/Patch boot configuration is unavailable: {error}");
            std::process::exit(2);
        }
    };
    let hardware = match init_hardware(handoff_mode == boot_oled_handoff::HandoffMode::Direct) {
        Ok(devices) => devices,
        Err(fault) => hardware_fault::run_hardware_fault_mode(fault),
    };
    let (event_rx, _encoders) = match init_encoders() {
        Ok(encoders) => encoders,
        Err(mut fault) => {
            fault.attach_outputs(hardware.oled, Some(hardware.trellis), Some(hardware.neokey));
            hardware_fault::run_hardware_fault_mode(fault);
        }
    };
    let HardwareDevices {
        _i2c_bus,
        oled,
        trellis,
        neokey,
        input_interrupt,
        _dac,
    } = hardware;
    let seesaw_io = seesaw_io::spawn_interrupt(trellis, neokey, input_interrupt);
    let audio = match init_audio(audio_optimization, usb_config.audio_outputs) {
        Ok(audio) => audio,
        Err(error) => {
            eprintln!("Audio init failed: {error}");
            std::process::exit(2);
        }
    };
    #[cfg(feature = "hardware-raspberry-pi-zero-2w")]
    let mut audio = audio;
    #[cfg(feature = "hardware-raspberry-pi-zero-2w")]
    let audio_load_rx = audio
        .as_mut()
        .and_then(AudioManager::take_load_status_receiver);

    let (midi_tx, midi_rx) = mpsc::channel::<MidiMessage>();
    let midi_handler = Arc::new(move |bytes: Vec<u8>| {
        if let Some(message) = midi_realtime_message(&bytes) {
            let _ = midi_tx.send(message);
        }
    });

    let samples_dir = default_samples_dir();
    ensure_runtime_dirs(&store_dir, &samples_dir);
    let runtime_config = raspberry_runtime::RaspberryRuntimeConfig {
        audio: audio.as_ref().map(AudioManager::service),
        store_dir,
        samples_dir,
        midi_handler,
        usb_midi_out_enabled: usb_config.midi_out_enabled,
        audio_outputs: usb_config.audio_outputs,
        usb_data_role: usb_config.data_role,
        audio_optimization,
        #[cfg(feature = "hardware-raspberry-pi-zero-2w")]
        audio_load_rx,
        midi_rx,
        keyboard: seesaw_io.spawn_keyboard(usb_config.data_role),
        input_rx: seesaw_io.input_rx,
        encoder_rx: event_rx,
        early_boot_splash: handoff_mode == boot_oled_handoff::HandoffMode::V1,
    };
    let hdmi = render::hdmi::HdmiFramebuffer::new();
    if handoff_mode == boot_oled_handoff::HandoffMode::V1 {
        rpi_oled_handoff_runtime::run(runtime_config, seesaw_io.command_tx.clone(), hdmi);
    } else {
        let oled = oled.expect("direct startup must initialize OLED");
        #[cfg(all(test, not(feature = "hardware-orange-pi-zero-2w")))]
        let oled = render::test_oled_output::real_oled_output(oled);
        let render_worker = RenderWorker::spawn(HardwareRenderTargets {
            oled,
            seesaw_tx: seesaw_io.command_tx.clone(),
            oled_handoff: None,
            hdmi,
        });
        raspberry_runtime::run(runtime_config, render_worker);
    }
}

#[cfg(not(feature = "hardware-orange-pi-zero-2w"))]
fn run_requested_utility() {
    if dsp_profile::profile_requested() {
        std::process::exit(exit_code(dsp_profile::run_dsp_profile().is_ok()));
    }
    if timing_probe::requested() {
        std::process::exit(exit_code(timing_probe::run()));
    }
    if oled_utility::requested() {
        std::process::exit(exit_code(oled_utility::run()));
    }
}

fn fat_diagnostic_exit_code() -> i32 {
    diagnostic_result_exit_code(fat_diagnostic::run())
}

fn diagnostic_result_exit_code(result: Result<bool, String>) -> i32 {
    match result {
        Ok(true) => 0,
        Ok(false) => 1,
        Err(error) if error == "help requested" => 0,
        Err(error) => {
            eprintln!("FAT diagnostic argument/error: {error}");
            2
        }
    }
}

fn exit_code(success: bool) -> i32 {
    if success {
        0
    } else {
        1
    }
}

#[cfg(not(feature = "hardware-orange-pi-zero-2w"))]
fn init_audio(
    audio_optimization: playback_runtime::AudioOptimization,
    audio_outputs: playback_runtime::AudioOutputSet,
) -> Result<Option<AudioManager>, String> {
    match AudioManager::new(audio_optimization, audio_outputs) {
        Ok(audio) => {
            audio.service().ensure_route_readiness()?;
            println!("Audio ready");
            Ok(Some(audio))
        }
        Err(error) => Err(error),
    }
}
#[cfg(test)]
mod tests;

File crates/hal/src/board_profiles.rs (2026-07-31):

#[derive(Clone, Copy, Debug, Eq, PartialEq)]
pub struct EncoderPins {
    pub a: u8,
    pub b: u8,
    pub sw: u8,
}

#[derive(Clone, Copy, Debug, Eq, PartialEq)]
pub struct OrangeUartConflict {
    pub signal: &'static str,
    pub physical_pin: u8,
    pub offset: u32,
}

#[derive(Clone, Copy, Debug, Eq, PartialEq)]
pub struct OrangeEncoderPins {
    pub physical_a: u8,
    pub physical_b: u8,
    pub physical_sw: u8,
    pub a: u32,
    pub b: u32,
    pub sw: u32,
    pub uart_conflict: Option<OrangeUartConflict>,
    pub reverse_direction: bool,
}

impl OrangeEncoderPins {
    pub const fn qualified(
        physical_a: u8,
        physical_b: u8,
        physical_sw: u8,
        a: u32,
        b: u32,
        sw: u32,
    ) -> Self {
        Self {
            physical_a,
            physical_b,
            physical_sw,
            a,
            b,
            sw,
            uart_conflict: None,
            reverse_direction: true,
        }
    }

    pub const fn with_uart_conflict(
        physical_a: u8,
        physical_b: u8,
        physical_sw: u8,
        a: u32,
        b: u32,
        sw: u32,
        signal: &'static str,
    ) -> Self {
        Self {
            physical_a,
            physical_b,
            physical_sw,
            a,
            b,
            sw,
            uart_conflict: Some(OrangeUartConflict {
                signal,
                physical_pin: physical_sw,
                offset: sw,
            }),
            reverse_direction: true,
        }
    }

    pub const fn switch_available(self, uart0_active: bool) -> bool {
        !uart0_active || self.uart_conflict.is_none()
    }

    pub const fn requested_gpio_offsets(self, uart0_active: bool) -> [Option<u32>; 3] {
        [
            Some(self.a),
            Some(self.b),
            if self.switch_available(uart0_active) {
                Some(self.sw)
            } else {
                None
            },
        ]
    }

    pub const fn canonical_turn_delta(self, delta: i8) -> i8 {
        if self.reverse_direction {
            -delta
        } else {
            delta
        }
    }
}

#[derive(Clone, Copy, Debug, Eq, PartialEq)]
pub struct DeviceDescriptor {
    pub path: &'static str,
    pub controller: &'static str,
}

#[derive(Clone, Copy, Debug, Eq, PartialEq)]
pub struct OrangeGpioDescriptor {
    pub chip_label: &'static str,
    pub dc_offset: u32,
    pub reset_offset: u32,
    pub reset_active_low: bool,
}

#[derive(Clone, Copy, Debug, Eq, PartialEq)]
pub struct OrangePiDevices {
    pub i2c: DeviceDescriptor,
    pub trellis_addrs: [u16; 4],
    pub neokey_addr: u16,
    pub spi: DeviceDescriptor,
    pub gpio: OrangeGpioDescriptor,
    pub encoders: [OrangeEncoderPins; 1 + platform_core::AUX_ENCODER_COUNT],
}

#[derive(Clone, Copy, Debug, Eq, PartialEq)]
pub enum SeesawInputMode {
    Interrupt,
    Polling,
}

pub const RASPBERRY_PI_ZERO_2W_ID: &str = "raspberry-pi-zero-2w";
pub const ORANGE_PI_ZERO_2W_ID: &str = "orange-pi-zero-2w";

#[derive(Clone, Copy, Debug, Eq, PartialEq)]
pub struct BoardProfile {
    pub id: &'static str,
    pub i2c_bus: u8,
    pub i2c_path: &'static str,
    pub spi_bus: &'static str,
    pub oled_cs: u8,
    pub oled_dc: u8,
    pub oled_rst: u8,
    pub oled_sd_cs: u8,
    pub oled_sd_cd: u8,
    pub i2s_bck: u8,
    pub i2s_lrck: u8,
    pub i2s_din: u8,
    pub encoders: [EncoderPins; 1 + platform_core::AUX_ENCODER_COUNT],
    pub neokey_addr: u16,
    pub seesaw_int: u8,
    pub trellis_addrs: [u16; 4],
}

#[derive(Clone, Copy, Debug, Eq, PartialEq)]
pub struct OrangeBoardProfile {
    pub id: &'static str,
    pub devices: OrangePiDevices,
}

pub const RASPBERRY_PI_ZERO_2W: BoardProfile = BoardProfile {
    id: RASPBERRY_PI_ZERO_2W_ID,
    i2c_bus: 1,
    i2c_path: "/dev/i2c-1",
    spi_bus: "/dev/spidev0.0",
    oled_cs: 8,
    oled_dc: 23,
    oled_rst: 16,
    oled_sd_cs: 7,
    oled_sd_cd: 20,
    i2s_bck: 18,
    i2s_lrck: 19,
    i2s_din: 21,
    encoders: [
        EncoderPins { a: 6, b: 5, sw: 12 },
        EncoderPins {
            a: 25,
            b: 13,
            sw: 17,
        },
        EncoderPins {
            a: 4,
            b: 27,
            sw: 14,
        },
        EncoderPins {
            a: 24,
            b: 26,
            sw: 22,
        },
    ],
    neokey_addr: 0x3F,
    seesaw_int: 15,
    trellis_addrs: [0x2E, 0x2F, 0x30, 0x31],
};
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

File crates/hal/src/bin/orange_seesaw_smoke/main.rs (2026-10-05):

use std::env;
use std::process;
#[cfg(any(test, target_os = "linux"))]
use std::time::{Duration, Instant};

#[cfg(target_os = "linux")]
use std::sync::atomic::{AtomicBool, Ordering};

#[cfg(any(test, target_os = "linux"))]
use octessera_hal::board_profiles::ORANGE_PI_ZERO_2W_DEVICES;
use octessera_hal::orange_metadata::{print_build_metadata_for, SEESAW_BINARY_NAME};

#[cfg(any(test, target_os = "linux"))]
const I2C_PATH: &str = ORANGE_PI_ZERO_2W_DEVICES.i2c.path;
#[cfg(any(test, target_os = "linux"))]
const STATUS_BASE: u8 = 0x00;
#[cfg(any(test, target_os = "linux"))]
const HW_ID: u8 = 0x01;
#[cfg(any(test, target_os = "linux"))]
const SW_RESET: u8 = 0x7F;
#[cfg(any(test, target_os = "linux"))]
const VALID_HW_IDS: [u8; 7] = [0x55, 0x84, 0x85, 0x86, 0x87, 0x88, 0x89];
#[cfg(target_os = "linux")]
const RESET_DELAY: Duration = Duration::from_millis(500);
#[cfg(target_os = "linux")]
const OPERATION_BUDGET: Duration = Duration::from_secs(3);

#[cfg(target_os = "linux")]
static INTERRUPTED: AtomicBool = AtomicBool::new(false);

#[derive(Clone, Copy, Debug, Eq, PartialEq)]
struct Options {
    confirm_active_test: bool,
    print_build_metadata: bool,
}

#[cfg(any(test, target_os = "linux"))]
trait I2cOperations {
    fn write(&mut self, address: u16, data: &[u8]) -> Result<(), String>;

    fn write_read(
        &mut self,
        address: u16,
        write_data: &[u8],
        read_data: &mut [u8],
    ) -> Result<(), String>;
}

fn main() {
    let options = match parse_args(env::args().skip(1)) {
        Ok(options) => options,
        Err(error) => {
            eprintln!("{error}");
            eprintln!("usage: orange-seesaw-smoke --confirm-active-test | --print-build-metadata");
            process::exit(2);
        }
    };

    if options.print_build_metadata {
        if let Err(error) = print_build_metadata_for(SEESAW_BINARY_NAME) {
            eprintln!("Orange Seesaw build metadata check failed: {error}");
            process::exit(1);
        }
        return;
    }

    if let Err(error) = require_active_test_confirmation(options) {
        eprintln!("{error}");
        process::exit(2);
    }

    #[cfg(not(target_os = "linux"))]
    {
        eprintln!("Orange Seesaw smoke requires a Linux target with the real Orange HAL");
        process::exit(2);
    }

    #[cfg(target_os = "linux")]
    if let Err(error) = run_smoke_test() {
        eprintln!("Orange Seesaw smoke failed: {error}");
        process::exit(1);
    }
}

fn parse_args<I, S>(args: I) -> Result<Options, String>
where
    I: IntoIterator<Item = S>,
    S: Into<String>,
{
    let mut options = Options {
        confirm_active_test: false,
        print_build_metadata: false,
    };
    for arg in args {
        match arg.into().as_str() {
            "--confirm-active-test" if !options.confirm_active_test => {
                options.confirm_active_test = true;
            }
            "--confirm-active-test" => return Err("duplicate --confirm-active-test".into()),
            "--print-build-metadata" if !options.print_build_metadata => {
                options.print_build_metadata = true;
            }
            "--print-build-metadata" => return Err("duplicate --print-build-metadata".into()),
            unknown => return Err(format!("unknown argument: {unknown}")),
        }
    }
    if options.confirm_active_test && options.print_build_metadata {
        return Err("--print-build-metadata is exclusive with --confirm-active-test".into());
    }
    Ok(options)
}

fn require_active_test_confirmation(options: Options) -> Result<(), &'static str> {
    if options.confirm_active_test {
        Ok(())
    } else {
        Err("refusing active Orange Seesaw test without --confirm-active-test")
    }
}

#[cfg(any(test, target_os = "linux"))]
fn ensure_safe<F>(deadline: Instant, interrupted: &mut F, phase: &str) -> Result<(), String>
where
    F: FnMut() -> bool,
{
    if interrupted() {
        return Err(format!(
            "Orange Seesaw smoke interrupted; synchronous I2C operations are observed only between calls ({phase})"
        ));
    }
    if Instant::now() >= deadline {
        return Err(format!(
            "Orange Seesaw smoke cooperative budget expired; {phase}"
        ));
    }
    Ok(())
}

#[cfg(any(test, target_os = "linux"))]
fn sleep_reset_delay_until<F>(
    deadline: Instant,
    reset_delay: Duration,
    interrupted: &mut F,
) -> Result<(), String>
where
    F: FnMut() -> bool,
{
    ensure_safe(deadline, interrupted, "before reset delay")?;
    let wake_time = Instant::now()
        .checked_add(reset_delay)
        .ok_or_else(|| "Orange Seesaw smoke reset delay overflowed its deadline".to_string())?;
    if wake_time >= deadline {
        return Err("Orange Seesaw smoke reset delay would exceed its cooperative budget".into());
    }
    std::thread::sleep(reset_delay);
    ensure_safe(deadline, interrupted, "after reset delay")
}

#[cfg(any(test, target_os = "linux"))]
fn device_addresses() -> [u16; 5] {
    let devices = ORANGE_PI_ZERO_2W_DEVICES;
    [
        devices.trellis_addrs[0],
        devices.trellis_addrs[1],
        devices.trellis_addrs[2],
        devices.trellis_addrs[3],
        devices.neokey_addr,
    ]
}

#[cfg(any(test, target_os = "linux"))]
fn device_name(address: u16) -> &'static str {
    if ORANGE_PI_ZERO_2W_DEVICES.neokey_addr == address {
        "NeoKey"
    } else {
        "NeoTrellis"
    }
}

#[cfg(any(test, target_os = "linux"))]
fn run_diagnostic<T: I2cOperations>(
    bus: &mut T,
    reset_delay: Duration,
    deadline: Instant,
    mut interrupted: impl FnMut() -> bool,
) -> Result<Vec<(u16, u8)>, String> {
    for address in device_addresses() {
        ensure_safe(deadline, &mut interrupted, "before reset")?;
        bus.write(address, &[STATUS_BASE, SW_RESET, 0xFF])
            .map_err(|error| {
                format!(
                    "{} reset failed at {address:#04x}: {error}",
                    device_name(address)
                )
            })?;
        ensure_safe(deadline, &mut interrupted, "after reset")?;
    }
    sleep_reset_delay_until(deadline, reset_delay, &mut interrupted)?;

    let mut ids = Vec::with_capacity(device_addresses().len());
    for address in device_addresses() {
        let mut id = [0_u8; 1];
        ensure_safe(deadline, &mut interrupted, "before HW ID read")?;
        bus.write_read(address, &[STATUS_BASE, HW_ID], &mut id)
            .map_err(|error| {
                format!(
                    "{} HW ID read failed at {address:#04x}: {error}",
                    device_name(address)
                )
            })?;
        ensure_safe(deadline, &mut interrupted, "after HW ID read")?;
        if !is_valid_hw_id(id[0]) {
            return Err(format!(
                "{} HW ID invalid at {address:#04x}: {:#04x}",
                device_name(address),
                id[0]
            ));
        }
        ids.push((address, id[0]));
    }
    Ok(ids)
}
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

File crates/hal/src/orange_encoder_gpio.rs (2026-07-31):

#[cfg(target_os = "linux")]
use crate::board_profiles::{OrangeEncoderPins, OrangeGpioDescriptor, ORANGE_PI_ZERO_2W_DEVICES};
#[cfg(target_os = "linux")]
use crate::encoder_gpio::{HardwareEvent, QuadratureState, SWITCH_DEBOUNCE_MS};
#[cfg(target_os = "linux")]
use gpiocdev::line::{Bias, EdgeDetection, EdgeKind, Value};
#[cfg(target_os = "linux")]
use gpiocdev::{Chip, Request};
#[cfg(target_os = "linux")]
use std::fs;
#[cfg(target_os = "linux")]
use std::path::{Path, PathBuf};
#[cfg(target_os = "linux")]
use std::sync::atomic::{AtomicBool, Ordering};
#[cfg(target_os = "linux")]
use std::sync::{mpsc::Sender, Arc};
#[cfg(target_os = "linux")]
use std::thread::{self, JoinHandle};
#[cfg(target_os = "linux")]
use std::time::Duration;

#[cfg(target_os = "linux")]
pub struct OrangeEncoderGpio {
    stop: Arc<AtomicBool>,
    worker: Option<JoinHandle<()>>,
}

#[cfg(target_os = "linux")]
impl OrangeEncoderGpio {
    pub fn new(
        id: &'static str,
        pins: &OrangeEncoderPins,
        tx: Sender<HardwareEvent>,
    ) -> Result<Self, String> {
        Self::new_with_uart0_active(id, pins, true, tx)
    }

    pub fn new_with_uart0_active(
        id: &'static str,
        pins: &OrangeEncoderPins,
        uart0_active: bool,
        tx: Sender<HardwareEvent>,
    ) -> Result<Self, String> {
        let chip_path = find_gpio_chip(ORANGE_PI_ZERO_2W_DEVICES.gpio, pins, uart0_active)?;
        let quadrature = request_quadrature(&chip_path, pins)?;
        let switch = pins
            .switch_available(uart0_active)
            .then(|| request_switch(&chip_path, pins))
            .transpose()?;
        let initial = quadrature_state(&quadrature, pins)?;
        let stop = Arc::new(AtomicBool::new(false));
        let worker_stop = Arc::clone(&stop);
        let descriptor = *pins;
        let worker = thread::Builder::new()
            .name(format!("octessera-orange-{id}"))
            .spawn(move || run_worker(id, descriptor, quadrature, switch, initial, worker_stop, tx))
            .map_err(|error| format!("{id} encoder worker start failed: {error}"))?;
        Ok(Self {
            stop,
            worker: Some(worker),
        })
    }
}

#[cfg(target_os = "linux")]
impl Drop for OrangeEncoderGpio {
    fn drop(&mut self) {
        self.stop.store(true, Ordering::Release);
        if let Some(worker) = self.worker.take() {
            let _ = worker.join();
        }
    }
}

#[cfg(target_os = "linux")]
fn request_quadrature(chip_path: &Path, pins: &OrangeEncoderPins) -> Result<Request, String> {
    Request::builder()
        .on_chip(chip_path)
        .with_consumer("octessera-orange-encoder")
        .with_lines(&[pins.a, pins.b])
        .as_input()
        .with_bias(Bias::PullUp)
        .with_edge_detection(EdgeDetection::BothEdges)
        .request()
        .map_err(|error| format!("encoder A/B GPIO request failed: {error}"))
}

#[cfg(target_os = "linux")]
fn request_switch(chip_path: &Path, pins: &OrangeEncoderPins) -> Result<Request, String> {
    Request::builder()
        .on_chip(chip_path)
        .with_consumer("octessera-orange-encoder")
        .with_line(pins.sw)
        .as_input()
        .with_bias(Bias::PullUp)
        .with_edge_detection(EdgeDetection::BothEdges)
        .with_debounce_period(Duration::from_millis(SWITCH_DEBOUNCE_MS))
        .request()
        .map_err(|error| format!("encoder switch GPIO request failed: {error}"))
}

#[cfg(target_os = "linux")]
fn quadrature_state(
    request: &Request,
    pins: &OrangeEncoderPins,
) -> Result<QuadratureState, String> {
    let a = value_bit(
        request
            .value(pins.a)
            .map_err(|error| format!("encoder A GPIO read failed: {error}"))?,
    );
    let b = value_bit(
        request
            .value(pins.b)
            .map_err(|error| format!("encoder B GPIO read failed: {error}"))?,
    );
    Ok(QuadratureState::new_bits((a << 1) | b))
}
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

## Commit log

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2026-08-22 Fix board image audio and startup
    [board_profile.rs, main.rs]
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2026-09-21 Stabilize realtime audio and runtime controls
    [menu-help-texts.tsv]
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2026-09-28 Fix Pi host CI fixtures and boot digest
    [main.rs]
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2026-10-01 Smooth enclosure shoulder and correct Orange gadget docs
    [case_top_two_level_cadquery_orange-pi-zero-2w.step, case_top_two_level_cadquery_orange-pi-zero-2w.stl, case_top_two_level_cadquery_raspberry-pi-zero-2w.step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]
2026-10-01 Test the Pi routing-tree executor in CI and pre-push
    CI and pre-push only built rodio-engine-source and realtime-engine with
    default features, so the executor tests that cover the production Pi
    audio path were never compiled. They had rotted: InstrumentSlotConfig
    literals lacked the drum/pluck fields, and one rodio test still expected
    the pre-smoothing freeze hard-cut to silence (changed intentionally in
    d9875c42). Fix both and run the executor-feature tests and clippy.
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2026-10-01 Use nested modules instead of #[path] chains in realtime-engine
    Replace 87 #[path] attributes with the standard module layout: each file
    moves to the directory of the module that declares it (e.g.
    routing_tree_capacity_tests.rs -> routing_tree_pipeline_tests/capacity.rs).
    Module names and contents are unchanged; only include paths and the
    attributes themselves are rewritten.
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2026-10-01 Fix rotted routing-tree timing test
    The benchmark-timing executor test still built SetPreparedInstruments as
    a tuple variant and lacked the drum/pluck slot fields, so the diagnostic
    feature combination (output-provenance + source-worker-benchmark-timing)
    no longer compiled its tests.
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2026-10-02 Use Orange's Aux timing driver on both boards
    Raspberry AutoAux and Orange timing input drove the same shared
    AutoAuxSequence and menu preflight through two board drivers, two
    command-evidence counters, and two store-result paths (Raspberry buffered
    results from every dispatch in the adapter; Orange accepted them from its
    host-result drain). Replace both with timing_input.rs: Orange's driver,
    generic over a TimingHost, with one TimingStudyEvidence recorded at each
    board's host-result drain. The sequence refreshes its final revision
    before accepting a save so drain ordering cannot drop the receipt.
    Raspberry studies now use OCTESSERA_TIMING_AUTOAUX/AUTOPLAY and Orange's
    report keys (rev_*, s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
    [main.rs]
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2026-10-02 Replace the Orange respin record chain with one parent hash check
    The runtime respin carried a requested-build record, a respin provenance
    sidecar, a full production-proof re-run, and a post-proof record with its
    own validator around a transactional, rollback-capable mutation of a
    private image copy. Replace the respin step with tools/image-respin/
    respin.py: verify the parent image against the reviewed parent record's
    sha256, install the runtime release and links, update update-state.json
    and the runtime keys of build-metadata.env, and fail if the partition
    table, pre-partition bytes, or anything under /boot changes. Output is the
    image plus a SHA256SUMS file.
    Validated locally (WSL, root)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
2026-10-02 Build the System document directly from runner state
    system_document projected the full config payload just to keep its
    runtimeConfig. Build the system runtimeConfig straight from runner state
    and split Aux bindings with the existing helper, with tests pinning parity
    against the device projection and excluding musical behavior state.
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2026-10-02 Tidy the shared Aux timing driver after review
    - Record autosave results returned by flush_native_persistence_at as study
    evidence on both boards, so a failed final save fails the study at once
    instead of after the 18 s timeout.
    - Rename OCTESSERA_PI_TIMING_KEEP_AWAKE to OCTESSERA_TIMING_KEEP_AWAKE to
    match the other timing variables; update both boards' study tooling.
    - Drop the test-only Deref from TimingInput and keep both boards' timing
    tests beside their runtime loops.
    - Remove a stale clippy allow and a no-op rebinding in raspberry_runtime.
    - Document the env-gated autoplay and keep-awake startup behaviour.
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2026-10-02 Accept Duck source strings in host FX command validation
    Selecting Duck on an FX bus slot sends SetFxBusSlot with the string
    params source (I1..I8/B1..B4) and sourceTap (pre/post). Both the Pi and
    desktop hosts required every FX param to be a finite number, so every
    interactive Duck selection was rejected: the menu showed a runtime error,
    the engine kept the previous slot effect, and later Duck edits ran against
    a slot the runner no longer agreed with, stopping playback. Presets with
    Duck loaded fine because they use the full-config path.
    Expose playback_runtime::is_valid_fx_string_param, built on the existing
    config rules, and let both hosts accept those strings while keeping the
    finite-nu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
2026-10-02 Replace single-element loop in FAT diagnostic artifact check
    Rust 1.99 clippy rejects iterating a one-element array
    (single_element_loop), which failed Rust clippy, both Pi host test jobs,
    and the cross build on CI. Read the board profile contract directly.
2026-10-02 Provision the Orange test store like a real device
    Since System and patch saves were split, startup expects system.json and
    default.patch.json; real images provision both and boot refuses to start
    without them. The test-only store in prepare_runtime was empty, so on
    Linux CI startup showed "System document is unavailable" and two Orange
    tests failed. Write the shipped Pi defaults into the temp store and expect
    the audio config revision a provisioned startup applies.
2026-10-02 Fix shellcheck findings in split save-document checks
    The Board profile script checks job failed on SC2015 in
    verify-boot-layout.sh (A && B || C used as if/else) and on SC2317 for a
    read_file stub that the eval'd validate_save_document calls indirectly.
    Use an explicit if, annotate the indirect call, and refresh the pinned
    verify-boot-layout.sh digest in the Raspberry boot-layer contract.
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2026-10-02 Share one host core between the Raspberry and Orange Pi adapters
    Both Pi host adapters carried their own copies of the platform service,
    pending default save, MIDI host, OLED frame cache, recovery-save status
    and keyboard capture control, plus the logic around them. Move that state
    and the shared store/MIDI/OLED/keyboard handling into PiHostCore so each
    adapter keeps only its board-specific audio, power and recording paths.
    - Drop QueueFailureStyle; both boards report queue failures the same way
    through one enqueue_job.
    - Load/save store effects and the shutdown-pending guard are handled once.
    - Raspberry failures are request-identified like Orange's, and unknown
    effects report "unsuppo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
    [main.rs]
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2026-10-03 Give the Orange SD2 slot its card-detect line
    Without card detect the kernel polled the empty mmc-spi slot on SPI1 about
    14 times a second. On the debug-enabled Armbian kernel every poll logged an
    spi setup line (~850/min), which rotated the service's own logs out of the
    20 MB volatile journal within hours, and the polls shared SPI1 with the OLED.
    Wire the OLED module's CD line (header pin 38, H618 PI4, high when a card is
    present, pull-up) through the binding's legacy gpios property. Verified on
    the board: the poll flood stops, removal and insertion raise the CD
    interrupt, and a card present at probe registers as mmcblk. The validators
    allow exactly this one property; the unmerged-overlay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
2026-10-03 Give a hot-inserted SD2 card time to power up on both boards
    mmc_spi requests a 1 ms card-detect debounce. Neither board's pin controller
    debounces in hardware, so the core used 1 ms as its detect delay and tried
    to initialise a freshly inserted card before it had powered up; the single
    attempt failed until the card was reinserted. On the Orange with the OLED
    busy on the shared SPI bus, probing 0-500 ms after insertion failed, while
    1, 2 and 3 s all succeeded.
    Carry a one-line kernel patch for both kernels that waits 2 s, register it
    in the shared patch manifest, the source gate (which now also stages
    mmc_spi.c and checks the patched call), both Raspberry kernel contracts and
    the Orange ker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
2026-10-03 Give the audio engine a single owner instead of a sink registry
    Only the DAC stream ever owns an engine; USB, HDMI and recording copy its
    output. Replace the sink list, attach gate and separate replay lock with one
    owner that remembers replay state and re-seeds the engine when the DAC
    stream (re)opens.
    Closes #7
    [main.rs]
2026-10-03 Skip the latest-control scan when nothing was published
    Every audio callback snapshotted all 1,897 latest-value cells (about 45 KB of
    atomics, more than the A53 L1) to find changes, and the routing executor
    scanned them again. A board profile showed this was the largest single
    self-time item in the Orange audio callback. A publication counter lets the
    callback skip the scan until something is published.
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2026-10-03 Remount the OLED SD card when a re-inserted card reuses the device name
    Nothing reacts to card removal, so after a swap the old exFAT mount stayed in
    place. The re-inserted card came back under the same device name, the helper
    took the dead mount for a healthy one and failed with I/O errors. Record the
    kernel disk sequence at mount time and lazily replace a mount whose card was
    since replaced.
2026-10-03 Ship BlueZ on both boards with the controller unpowered by default
    Raspberry no longer disables the Bluetooth radio (enable_uart=0 stays, so
    SW3 keeps GPIO14) and runs bluetooth.service; hciuart stays masked because
    the radio attaches through serdev. Orange installs bluez explicitly. Both
    set AutoEnable=false, so the controller stays off until Octessera powers it.
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2026-10-04 Make Pi tests hold up on a loaded host
    Parallel tests named temp directories from the process id and a coarse
    clock tick, so two tests could share a directory and delete each other's
    files; a shared helper now adds a process-wide counter. Worker and scene
    tests wait on outcomes or a frozen display clock instead of short wall
    clock windows, and the transfer server puts accepted connections back
    in blocking mode (Windows otherwise inherits the listener's non-blocking
    mode and drops slow requests).
    [main.rs]
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2026-10-04 Share one runtime-thread helper between the boards
    Replaces the temporary Orange spawn with the octessera-runtime thread helper
    Raspberry now uses too. Orange AutoAux studies on the thread matched or beat
    the inline baseline (startup max 66-69 ms vs 62-70 ms, steady mean 321-338 us
    vs 328-342 us, steady max 6.5-9.2 ms vs 7.3-12 ms, one startup underrun
    each), and Raspberry already measured worse inline.
    [main.rs]
2026-10-04 Use one host adapter for both boards
    PiPlaybackHostAdapter and OrangeHostAdapter merge into PiHostAdapter. Board
    differences shrink to construction and the device-apply handoff (Raspberry
    has already saved the boot config; Orange carries its apply transaction),
    both expressed through one PowerRequest. The unused OrangeAudioHost goes
    away. Two small behaviour alignments: a failed device apply now reports a
    failure toast on Orange as on Raspberry, and Hardware Test answers as
    unsupported on both boards instead of a silent Raspberry log line.
    [main.rs]
2026-10-04 Use one native scene pump for both boards
    The Raspberry and Orange scene pumps were the same apart from capture-time
    profiling (now recorded on both boards) and how a failed render resets the
    in-flight generation (the stricter Orange handling is kept).
    [main.rs]
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2026-10-04 Run both boards through one runtime loop
    The Raspberry scheduler loop becomes the shared loop for both boards:
    three runtime advances around MIDI, host input, encoders and the timing
    driver, with board hooks only for per-iteration audio upkeep and what a
    power request does. Orange keeps its startup and shutdown resolution, and
    its audio recovery, health checks and readiness gate become its upkeep
    hook. Raspberry power handling moves to raspberry_power.rs.
    Behaviour aligned to Raspberry on Orange: a failed runtime dispatch or
    advance is logged instead of ending the process (required audio faults
    stay fatal), host input is drained 16 messages at a time, and wake traces
    are available on both b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
    [main.rs]
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2026-10-04 Share the reboot/shutdown lifecycle between the boards
    Both boards run the ordinary power lifecycle through host_power_lifecycle
    (save, silence, terminal frame, then the board's power command); the
    Raspberry device-apply reboot reuses the same terminal-frame step. Only
    the power command itself stays per board.
    [main.rs]
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2026-10-06 Play a connected Bluetooth speaker as a low-priority monitor of the mix
    System > Bluetooth > Audio Out copies the final mix to the first paired,
    connected speaker. The primary callback only fills a bounded monitor tap;
    a background feeder (SCHED_OTHER, nice 10, DSP cores) hands it to aplay on
    bluez-alsa, so a slow or missing speaker drops monitor audio and never
    touches the wired outputs. Both images ship bluez-alsa with its daemon kept
    below the audio threads.
    Refs #6
    [menu-help-texts.tsv]
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2026-10-06 Keep the MIDI note-off clock from dropping sub-millisecond ticks
    The runtime advanced its scheduled-MIDI clock in whole milliseconds, so
    loop ticks shorter than 1 ms never moved it and external note-offs drifted
    late. Accumulate the clock as a Duration instead.
2026-10-06 Fix small desktop simulator input and store slips
    - Report a corrupt preset file as an error, as the Pi does, instead of
    treating it as missing.
    - Only release Shift/Fn on mouse-leave while the mouse button is held.
    - Clear the Tauri IPC timeout timer once the call settles.
2026-10-06 Add a Build Seed that seeded layers and Link sections can opt into
    Build > Seed (1..9999) is one per-patch seed. Build > Lx > Seeded makes a
    layer's behavior randomness, including hash-style choices and the pattern
    seed, follow a stream mixed from Seed and the layer. Link > Lx > Seeded
    does the same for trigger probability and random arp order. Unseeded
    sources keep today's fresh randomness, so existing patches play as before.
    Seeded streams restart on every transport reset, on patch load, and when
    Seed or a Seeded switch changes, so the same patch, inputs and timing
    replay the same world. Audio-rate noise stays unseeded.
    [menu-help-texts.tsv]
2026-10-06 Keep seeded streams exact across resets and old patch loads
    - Run the transport-phase reset inside the layer's seeded scope, after the
    streams restart, so pattern layers start seeded.
    - Restart a seeded Twinkle's draw counter on transport reset.
    - Default missing Seed and Seeded fields when loading a patch, so an older
    patch doesn't inherit seeding from the one before it.
    - Pin the stream algorithm to ChaCha12 so saved seeds survive rand upgrades.
    - Keep Seed out of modulation bindings.
    - Say plainly that restarting the dice doesn't rewind an evolved world.
    [menu-help-texts.tsv]
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2026-10-07 Run the behavior liveness probe in the normal suite under fixed seeds
    It never ran because unseeded randomness made it flaky (about 2% of runs
    caught predator_prey in a static stretch). A seeded stream per behavior
    makes it deterministic, so it now guards default liveness every run.
2026-10-07 Let the update guard wait briefly for apply to switch the candidate
    The guard service can start before apply has switched current and marked
    the transaction validating. It then rolled back while apply carried on,
    which in the worst interleaving left current on an unguarded candidate.
    Wait up to 5 s for the switch before treating it as a failure.
2026-10-07 Poll retired audio state instead of blocking the reaper on it
    A reaper blocked in select on retired_rx registers a crossbeam waker, so
    every retirement the audio callback hands off takes the channel's waker
    mutex and issues a futex wake on the realtime thread. Draining with
    try_recv on a 5 ms poll keeps the callback's try_send purely atomic.
2026-10-07 Poll the shutdown channel too so no reaper waker reaches the audio thread
    recv_timeout on shutdown_rx still registered a crossbeam waker, so a source
    drop's try_send could take the waker mutex and free its entry on the
    sending thread. That also made the burst retirement test's no-dealloc
    check flaky on CI, where its fixture blocked the same way. Poll both
    channels, in the reaper and the test fixtures.
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2026-10-07 Let the Raspberry AutoAux study run any build, not only HEAD
    The study required the artifact's metadata commit to equal the checkout's
    HEAD, which blocked A/B runs against older builds and broke runs whenever
    anything was committed mid-study. Record the commit from the artifact's own
    metadata instead; its binary hash is still checked against that metadata so
    results stay labelled with the build that was measured.
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2026-10-07 Lock the board runtime's memory so page eviction cannot stall the audio callback
    Under memory pressure (reproduced with the daily apt refresh on the
    Raspberry) the audio callback took dozens of major page faults and underran
    for seconds. Both services already grant LimitMEMLOCK=infinity; mlockall with
    MCL_ONFAULT keeps touched pages resident without prefaulting stacks.
    [main.rs]
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2026-10-08 Add System > Setup > Show Hold to postpone board housekeeping for a show
    Hold 48h writes an expiry to /var/lib/octessera/show-hold/until; the board
    images give fstrim, logrotate, dpkg-db-backup, tmpfiles-clean and the
    Raspberry network logger an ExecCondition that skips them until it passes.
    The hold survives reboots and Release ends it early. Also masks the no-op
    e2scrub_all timer and drops Armbian's apt update counter and login quotes.
    [menu-help-texts.tsv]
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2026-10-09 Document this week's board timing work for players and contributors
    User docs: expected press-to-sound per Perf. Mode and a warning not to run
    apt upgrade on the board. Perf. Mode help states the trade-off. Runtime
    boundaries describe the input wake and memory locking; the profiling guide
    covers the load/probe harness and the board tools that found the fixes.
    [menu-help-texts.tsv]
2026-10-09 Hold the boards' kernel, firmware and bootloader packages against apt upgrades
    Raspberry keeps the stock rpi kernel images next to Octessera's kernel and
    Orange's Armbian kernel, dtb, u-boot and BSP packages were unheld, so a
    manual apt upgrade could replace the boot chain. Images and Raspberry
    provisioning now apt-mark hold them; our own installer uses dpkg -i, which
    holds do not block.
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2026-10-09 Keep the Raspberry boot splash finished for the rest of the boot
    octessera.service wants the splash, and the splash exits once the runtime
    takes over the OLED, so every later restart of octessera started it again.
    It then refused to overwrite this boot's handoff and left a failed unit
    behind. RemainAfterExit keeps it active once it has finished, so restarts
    leave it alone.
2026-10-09 Add Twinkle to the player's behavior catalog and refresh the save-split status
    Twinkle was in the menu but missing from the user catalog, and the save-split
    note still said no board had been migrated.
2026-10-09 Make Auto Label, Link axis Invert and recording Max Time work from the controls
    Since the menu edit path stopped falling back to a full apply (July), four
    rows had no keyed handler: turning instrument or bus Auto Label, or a Link
    X/Y slot Invert, was rejected and only logged, so the row showed the new
    value while nothing changed. Recording Max Time had a handler that read the
    number row as text and never applied. Each now has a direct handler, and a
    test turns every editable menu row through the real edit dispatch so a
    missing handler fails in CI instead of on the board.
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2026-10-10 Store instrument volume and MIDI note length in the ranges their rows show
    The menu, audio engine and bindings use 0-100 for instrument volume and
    10-2000 ms for MIDI note length, but patch validation, loading and the
    modulation clamp still allowed 0-127 and 10-5000, so an old or hand-edited
    patch could hold a value its row could not show. All saved stores on both
    boards and this host were checked first: none are outside the new ranges.
2026-10-10 Run menu tests through the real edit path and drop the test-only full apply
    apply_menu_state() existed only under cfg(test), so menu tests passed while
    devices used a different path; that is how four broken rows went unnoticed.
    Tests now select the row, turn it and dispatch it exactly as the controls do.
    Three tests that pinned a full audio-config rebuild now pin what devices
    actually send (direct synth/sample commands, a single-slot rebuild for a type
    change). The test-only full apply and the helpers only it used are removed,
    and the dispatch test file goes back to LF line endings.
2026-10-10 Check that every live Synth, FM and Plucked control sounds like the same patch value
    Turning a sound parameter while a note holds must leave the engine exactly
    where loading a patch with that value would, or a tweak sounds different
    after a reload. Each test walks the config's own numeric fields, changes
    each one live and through a prepared patch on a held note, and compares
    512 samples bit for bit; it also fails if a live control has no patch field.
    This covers all 64 controls instead of the four spot checks before.
2026-10-10 Check that every sound command the runtime sends is one the Pi accepts
    The Pi host validates synth and sample parameter paths against hand-written
    lists while FM and Plucked use the parameter tables; the lists now come from
    the tables too, so they cannot drift. Tests send every offered modulation
    target and every menu edit (all instrument and effect types) and fail if the
    Pi would drop the resulting command, which would change the sound on the
    desktop but not on a board.
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2026-10-11 Follow up the review of this week's control and audio-core fixes
    - deploy-pi.sh writes its own network-health unit; give it the same
    AllowedCPUs=2-3, or a deploy would put the job back on the audio core.
    - A Link axis Slot Invert with no target now shows Off instead of keeping
    On until the next rebuild, and a real invert change recomposes modulation
    at once like the grid toggle does.
    - The Auto Label handler checks the key before looking up its row.
    - The player's guide no longer claims LFO targets can be rejected for an
    existing owner (they add on top), and describes the synth's two envelopes
    correctly.
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2026-10-12 Let recordings follow OLED Sleep and record sleeping frames black
    A take used to hold the OLED awake, which burns a static menu into the panel
    during long unattended recordings. The normal sleep timer now applies, and
    while the screen sleeps the Audio+Video picture is all black, as on the
    device.
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
